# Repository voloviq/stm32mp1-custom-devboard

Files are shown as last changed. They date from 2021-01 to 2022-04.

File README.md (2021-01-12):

# stm32mp1-visionsom-custom-devboard
Custom development board for is located in two separated branch for stm32mp1-visionsom from Somlabs and osd32mp1 from Octavo Systems.

Development boards are created in KiCad.

Boards supported with DSI Display with touchscreen, arduino header, power supply, ethernet and usb.

Board 3D View

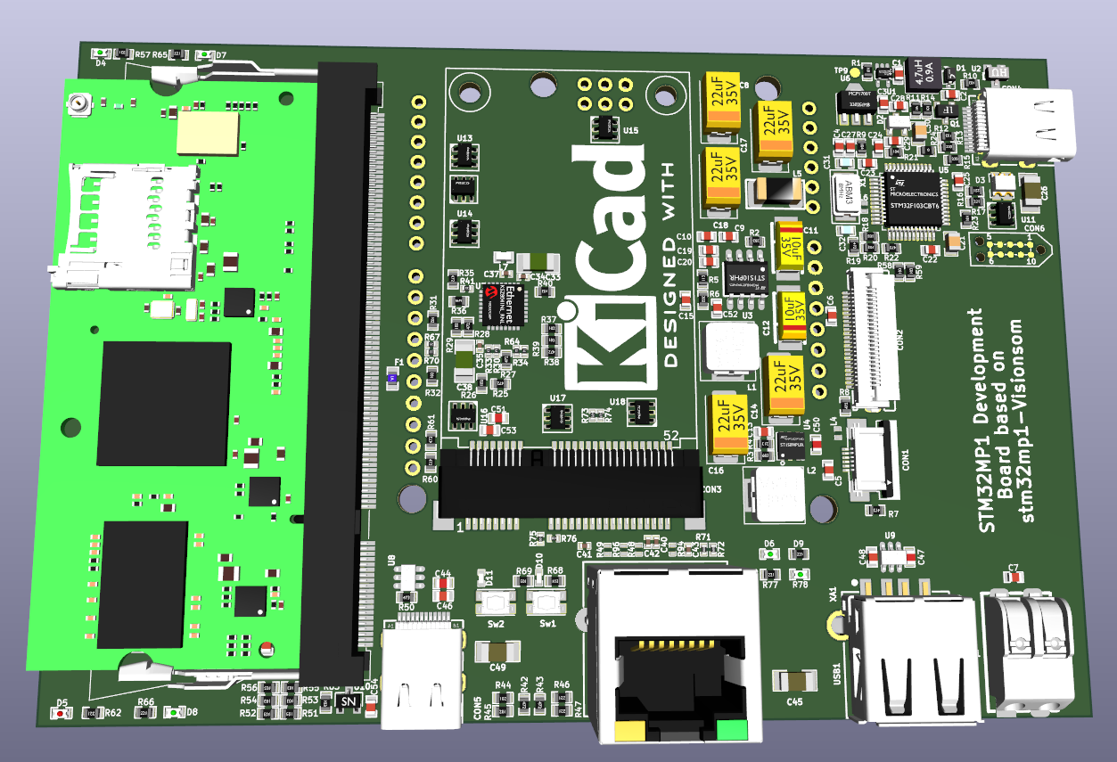
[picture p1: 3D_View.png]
Board 3D View


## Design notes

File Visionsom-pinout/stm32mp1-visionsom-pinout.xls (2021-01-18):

VisionSom STM32MP1xxx Pinout – MPU model STM32MP157AABxx LFBGA354
Signal Name | Module Pin Number | Ball Id | Pin Port Alternate function | Complete Pin Port Functions Description
DSI-Ckp | 195 | B14 | NA | DSI_CKP
DSI-Ckn | 193 | A14 | NA | DSI_CKN
SD2-CLK | 179 | A5 | AF9 | PE3_TRACED0,TIM15_BKIN,SAI1_SD_B,SDMMC2_CK,FMC_A19,EVENTOUT
SD2-DATA2 | 175 | A7 | AF9 | PB3_TRACED9,TIM2_CH2,SAI4_CK1,SPI1_SCK/I2S1_CK,SPI3_SCK/I2S3_CK,SPI6_SCK,SDMMC2_D2,SAI4_MCLK_A,UART7_RX,EVENTOUT
SD2-CMD | 173 | A6 | AF10 | PG6_TRACED14,TIM17_BKIN,SDMMC2_CMD,DCMI_D12,LCD_R7,EVENTOUT
SD2-DATA1 | 171 | A8 | AF9 | PB15_RTC_REFIN,TIM1_CH3N,TIM12_CH2,TIM8_CH3N,USART1_RX,SPI2_MOSI/I2S2_SDO,DFSDM1_CKIN2,SDMMC2_D1,EVENTOUT
SD2-DATA3 | 169 | B9 | AF9 | PB4_TRACED8,TIM16_BKIN,TIM3_CH1,SAI4_CK2,SPI1_MISO/I2S1_SDI,SPI3_MISO/I2S3_SDI,SPI2_NSS/I2S2_WS,SPI6_MISO,SDMMC2_D3,SAI4_SCK_A,UART7_TX,EVENTOUT
SD2-DATA0 | 167 | C9 | AF9 | PB14_TIM1_CH2N,TIM12_CH1,TIM8_CH2N,USART1_TX,SPI2_MISO/I2S2_SDI,DFSDM1_DATIN2,USART3_RTS/USART3_DE,SDMMC2_D0,EVENTOUT
LCD-ENABLE | 163 | C2 | AF14 | PE13_HDP2,TIM1_CH3,DFSDM1_CKIN5,SPI4_MISO,SAI2_FS_B,FMC_D10/FMC_DA10,DCMI_D6,LCD_DE,EVENTOUT
LCD-CLK | 161 | D3 | AF14 | PE14_TIM1_CH4,SPI4_MOSI,UART8_RTS/UART8_DE,SAI2_MCLK_B,SDMMC1_D123DIR,FMC_D11/FMC_DA11,LCD_G0,LCD_CLK,EVENTOUT
GPIO-PA1 | 157 | U4 | ? | PA1_ETH_CLK,TIM2_CH2,TIM5_CH2,LPTIM3_OUT,TIM15_CH1N,USART2_RTS/USART2_DE,UART4_RX,QUADSPI_BK1_IO3,SAI2_MCLK_B,ETH1_GMII_RX_CLK/ETH1_MII_RX_CLK/ETH1_RGMII_RX_CLK/ETH1_RMII_REF_CLK,LCD_R2,EVENTOUT,ADC1_INP17,ADC1_INN16
LCD-DATA1 | 155 | ? | ? | ?
LCD-DATA0 | 153 | ? | ? | ?
LCD-B6 | 151 | W6 | AF14 | REF_CLK
LCD-B5 | 149 | P3 | AF14 | PA3_TIM2_CH4,TIM5_CH4,LPTIM5_OUT,TIM15_CH2,USART2_RX,LCD_B2,ETH1_GMII_COL/ETH1_MII_COL,LCD_B5,EVENTOUT,ADC1_INP15,PVD_IN
LCD-DATA9 | 145 | ? | ? | ?
LCD-DATA8 | 143 | ? | ? | ?
LCD-G6 | 141 | A9 | AF14 | PC7_HDP4,TIM3_CH2,TIM8_CH2,DFSDM1_DATIN3,I2S3_MCK,USART6_RX,SDMMC1_D123DIR,SDMMC2_D123DIR,SDMMC2_D7,SDMMC1_D7,DCMI_D1,LCD_G6,EVENTOUT
LCD-G5 | 139 | U5 | AF14 | PF11_SPI5_MOSI,SAI2_SD_B,DCMI_D12,LCD_G5,EVENTOUT,ADC1_INP2
LCD-R2 | 137 | D11 | AF14 | PC10_TRACED2,DFSDM1_CKIN5,SPI3_SCK/I2S3_CK,USART3_TX,UART4_TX,QUADSPI_BK1_IO1,SAI4_MCLK_B,SDMMC1_D2,DCMI_D8,LCD_R2,EVENTOUT
LCD-DATA17 | 133 | ? | ? | ?
LCD-R6 | 131 | B8 | AF14 | PA8_MCO1,TIM1_CH1,TIM8_BKIN2,I2C3_SCL,SPI3_MOSI/I2S3_SDO,USART1_CK,SDMMC2_CKIN,SDMMC2_D4,OTG_FS_SOF/OTG_HS_SOF,SAI4_SD_B,UART7_RX,LCD_R6,EVENTOUT,
LCD-R5 | 129 | C8 | AF14 | PA9_TIM1_CH2,I2C3_SMBA,SPI2_SCK/I2S2_CK,USART1_TX,SDMMC2_CDIR,SDMMC2_D5,DCMI_D0,LCD_R5,EVENTOUT
GPIO-PE2 | 121 | T1 | ? | PE2_TRACECLK,SAI1_CK1,I2C4_SCL,SPI4_SCK,SAI1_MCLK_A,QUADSPI_BK1_IO2,ETH1_GMII_TXD3/ETH1_MII_TXD3/ETH1_RGMII_TXD3,FMC_A23,EVENTOUT
GPIO-PC2 | 119 | T2 | ? | PC2_DFSDM1_CKIN1,SPI2_MISO/I2S2_SDI,DFSDM1_CKOUT,ETH1_GMII_TXD2/ETH1_MII_TXD2/ETH1_RGMII_TXD2,DCMI_PIXCLK,EVENTOUT,ADC1_INP12,ADC1_INN11
GPIO-PA14 | 117 | R1 | ? | PA14_DBTRGO,DBTRGI,MCO2,EVENTOUT
GPIO-PA13 | 113 | P2 | ? | PA13_DBTRGO,DBTRGI,MCO1,UART4_TX,EVENTOUT,BOOTFAILN
GPIO-PD15 | 111 | G1 | ? | PD15_TIM4_CH4,SAI3_MCLK_A,UART8_CTS,FMC_D1/FMC_DA1,LCD_R1,EVENTOUT
GPIO-PG12 | 109 | F1 | ? | PG12_LPTIM1_IN1,SPI6_MISO,SAI4_CK2,USART6_RTS/USART6_DE,SPDIFRX_IN1,LCD_B4,SAI4_SCK_A,ETH1_PHY_INTN,FMC_NE4,LCD_B1,EVENTOUT
ENET1-CRS-DV | 101 | T6 | AF11 | PA7_TIM1_CH1N,TIM3_CH2,TIM8_CH1N,SAI4_D1,SPI1_MOSI/I2S1_SDO,SPI6_MOSI,TIM14_CH1,QUADSPI_CLK,ETH1_GMII_RX_DV/ETH1_MII_RX_DV/ETH1_RGMII_RX_CTL/ETH1_RMII_CRS_DV,SAI4_SD_A, EVENTOUT,ADC1_INP7,ADC1_INN3,ADC2_INP7,ADC2_INN3
ENET1-RXD1 | 99 | V4 | AF11 | PC5_SAI1_D3,DFSDM1_DATIN2,SAI4_D4, SAI1_D4,SPDIFRX_IN3,ETH1_GMII_RXD1/ETH1_MII_RXD1/ETH1_RGMII_RXD1/ETH1_RMII_RXD1, SAI4_D3,EVENTOUT,ADC1_INP8,ADC1_INN4,ADC2_INP8,ADC2_INN4
ENET1-RXD0 | 97 | W4 | AF11 | PC4_DFSDM1_CKIN2,I2S1_MCK,SPDIFRX_IN2,ETH1_GMII_RXD0/ETH1_MII_RXD0/ETH1_RGMII_RXD0/ETH1_RMII_RXD0,EVENTOUT,ADC1_INP4,ADC2_INP4
USART6-TXD | 79 | U1 | AF7 | PG14_TRACED1,LPTIM1_ETR,SPI6_MOSI, SAI4_D1,USART6_TX,QUADSPI_BK2_IO3,SAI4_SD_A,ETH1_GMII_TXD1/ETH1_MII_TXD1/ETH1_RGMII_TXD1/ETH1_RMII_TXD1,FMC_A25,LCD_B0,EVENTOUT
UART4-RXD | 77 | T13 | AF8 | PB2_TRACED4,RTC_OUT2,SAI1_D1,DFSDM1_CKIN1,USART1_RX,I2S_CKIN,SAI1_SD_A,SPI3_MOSI/I2S3_SDO,UART4_RX,QUADSPI_CLK,EVENTOUT
UART4-TXD | 75 | V6 | AF6 | PG11_TRACED11,USART1_TX,UART4_TX,SPDIFRX_IN0,ETH1_GMII_TX_EN/ETH1_MII_TX_EN/ETH1_RGMII_TX_CTL/ETH1_RMII_TX_EN,DCMI_D3,LCD_B3, EVENTOUT
USART1-TXD | 73 | T12 | AF7 | PB6_TIM16_CH1N,TIM4_CH1,I2C1_SCL, CEC,I2C4_SCL,USART1_TX,FDCAN2_TX,QUADSPI_BK1_NCS,DFSDM1_DATIN5,UART5_TX,DCMI_D5,EVENTOUT
USART1-RXD | 69 | T16 | AF7 | PA10_TIM1_CH3,SPI3_NSS/I2S3_WS,USART1_RX,MDIOS_MDIO,SAI4_FS_B,DCMI_D1,LCD_B1,EVENTOUT,OTG_FS_ID,OTG_HS_ID
USART3-RXD | 67 | G3 | AF7 | PD9_DFSDM1_DATIN3,SAI3_SD_B,USART3_RX,FMC_D14/FMC_DA14,DCMI_HSYNC,LCD_B0,EVENTOUT
USART3-TXD | 65 | F2 | AF7 | PD8_DFSDM1_CKIN3,SAI3_SCK_B,USART3_TX,SPDIFRX_IN1,FMC_D13/FMC_DA13,LCD_B7,EVENTOUT
UART8-RXD | 63 | C4 | AF8 | PE0_LPTIM1_ETR,TIM4_ETR,LPTIM2_ETR,SPI3_SCK/I2S3_CK,SAI4_MCLK_B,UART8_RX,SAI2_MCLK_A,FMC_NBL0,DCMI_D2,EVENTOUT
ENET1-MDIO | 61 | W2 | AF11 | PA2_TIM2_CH3,TIM5_CH3,LPTIM4_OUT,TIM15_CH1,USART2_TX,SAI2_SCK_B,SDMMC2_D0DIR, ETH1_MDIO, MDIOS_MDIO, LCD_R1, EVENTOUT, ADC1_INP14, WKUP2
UART8-TXD | 57 | B1 | AF8 | PE1_LPTIM1_IN2,I2S2_MCK,SAI3_SD_B,UART8_TX,FMC_NBL1,DCMI_D3,EVENTOUT
GPIO-PC0-ADC1-10 | 55 | T7 | ANALOG | PC0_DFSDM1_CKIN0,LPTIM2_IN2,DFSDM1_DATIN4,SAI2_FS_B,QUADSPI_BK2_NCS,LCD_R5,EVENTOUT,ADC1_INP10,ADC2_INP10
ENET1-MDC | 53 | V2 | AF11 | PC1_TRACED0,SAI1_D1,DFSDM1_DATIN0,DFSDM1_CKIN4,SPI2_MOSI/I2S2_SDO,SAI1_SD_A,SDMMC2_CK,ETH1_MDC,MDIOS_MDC,EVENTOUT,ADC1_INP11,ADC1_INN10,ADC2_INP11,ADC2_INN10,TAMP_IN3,WKUP6
GPIO-PD13 | 49 | U12 | ? | PD13_LPTIM1_OUT,TIM4_CH2,I2C4_SDA,I2C1_SDA,I2S3_MCK,QUADSPI_BK1_IO3,SAI2_SCK_A,FMC_A18,DSI_TE,EVENTOUT
GPIO-PC3-ADC1-13 | 47 | T3 | ANALOG | PC3_TRACECLK,DFSDM1_DATIN1,SPI2_MOSI/I2S2_SDO,ETH1_GMII_TX_CLK/ETH1_MII_TX_CLK,EVENTOUT,ADC1_INP13,ADC1_INN12
GPIO-PG10 | 45 | V7 | ? | PG10_TRACED10,UART8_CTS,LCD_G3,SAI2_SD_B,QUADSPI_BK2_IO2,FMC_NE3,DCMI_D2,LCD_B2,EVENTOUT
JTAG-TDI | 43 | D13 | NA | JTDI
USB-OTG2-DN | 27 | V13 | NA | USBH_HS_DM2,OTG_HS_DM
USB-OTG2-DP | 25 | W13 | NA | USBH_HS_DP2,OTG_HS_DP
USB-OTG1-DN | 21 | W14 | NA | USBH_HS_DM1
USB-OTG1-DP | 19 | V14 | NA | USBH_HS_DP1
USB-OTG2-VBUS | 11 |  | NA | NA
BOOT0 | 9 |  | NA | NA
BOOT1 | 7 |  | NA | NA
PWR-ON | 5 |  | NA | NA
PWR-LP | 3 |  | NA | NA
DSI-D1p | 194 | B15 | NA | DSI_D1P
DSI-D1n | 192 | A15 | NA | DSI_D1N
DSI-D0p | 188 | B13 | NA | DSI_D0P
DSI-D0n | 186 | A13 | NA | DSI_D0N
LCD-B7 | 166 | D9 | AF14 | PB9_HDP7,TIM17_CH1,TIM4_CH4,DFSDM1_DATIN7,I2C1_SDA,SPI2_NSS/I2S2_WS,I2C4_SDA,SDMMC2_CDIR,UART4_TX,FDCAN1_TX,SDMMC2_D5,SDMMC1_CDIR,SDMMC1_D5,DCMI_D7,LCD_B7,EVENTOUT
LCD-B2 | 164 | E3 | AF14 | PD6_TIM16_CH1N,SAI1_D1,DFSDM1_CKIN4,DFSDM1_DATIN1,SPI3_MOSI/I2S3_SDO,SAI1_SD_A,USART2_RX,FMC_NWAIT,DCMI_D10,LCD_B2,EVENTOUT
LCD-VSYNC | 162 | R4 | AF14 | PA4_HDP0,TIM5_ETR,SAI4_D2,SPI1_NSS/I2S1_WS,SPI3_NSS/I2S3_WS,USART2_CK,SPI6_NSS,SAI4_FS_A,DCMI_HSYNC,LCD_VSYNC,EVENTOUT,ADC1_INP18,ADC2_INP18,DAC_OUT1
LCD-HSYNC | 160 | D10 | AF14 | PC6_HDP1,TIM3_CH1,TIM8_CH1,DFSDM1_CKIN3,I2S2_MCK,USART6_TX,SDMMC1_D0DIR,SDMMC2_D0DIR,SDMMC2_D6,DSI_TE,SDMMC1_D6,DCMI_D0,LCD_HSYNC,EVENTOUT
LCD-B4 | 158 | D2 | AF14 | PE12_TIM1_CH3N,DFSDM1_DATIN5,SPI4_SCK,SDMMC1_D0DIR,SAI2_SCK_B,FMC_D9/FMC_DA9,LCD_B4,EVENTOUT
LCD-B3 | 154 | C5 | AF14 | PD10_RTC_REFIN,TIM16_BKIN,DFSDM1_CKOUT,I2C5_SMBA,SPI3_MISO/I2S3_SDI,SAI3_FS_B,USART3_CK,FMC_D15/FMC_DA15,LCD_B3,EVENTOUT
LCD-G2 | 152 | T5 | AF14 | PA6_TIM1_BKIN,TIM3_CH1,TIM8_BKIN,SAI4_CK2,SPI1_MISO/I2S1_SDI,SPI6_MISO,TIM13_CH1,MDIOS_MDC,SAI4_SCK_A,DCMI_PIXCLK,LCD_G2,EVENTOUT,ADC1_INP3,ADC2_INP3
LCD-G4 | 150 | W5 | AF14 | PB10_TIM2_CH3,LPTIM2_IN1,I2C2_SCL,SPI2_SCK/I2S2_CK,DFSDM1_DATIN7,USART3_TX,QUADSPI_BK1_NCS,ETH1_GMII_RX_ER/ETH1_MII_RX_ER,LCD_G4,EVENTOUT
LCD-G3 | 148 | C1 | AF14 | PE11_TIM1_CH2,DFSDM1_CKIN4,SPI4_NSS,USART6_CK,SAI2_SD_B,FMC_D8/FMC_DA8,DCMI_D4,LCD_G3,EVENTOUT
LCD-DATA16 | 144 | ? | ? | ?
LCD-G7 | 142 | U7 | AF14 | PG8_TRACED15,TIM2_CH1/TIM2_ETR,ETH_CLK,TIM8_ETR,SPI6_NSS,SAI4_D2,USART6_RTS/USART6_DE,USART3_RTS/USART3_DE,SPDIFRX_IN2,SAI4_FS_A,ETH1_PPS_OUT,LCD_G7,EVENTOUT
LCD-R4 | 140 | P4 | AF14 | PA5_TIM2_CH1/TIM2_ETR,TIM8_CH1N,SAI4_CK1,SPI1_SCK/I2S1_CK,SPI6_SCK,SAI4_MCLK_A,LCD_R4,EVENTOUT,ADC1_INP19,ADC1_INN18,ADC2_INP19,ADC2_INN18,DAC_OUT2
LCD-R3 | 138 | W3 | AF9 | PB0_TIM1_CH2N,TIM3_CH3,TIM8_CH2N,DFSDM1_CKOUT,UART4_CTS,LCD_R3,ETH1_GMII_RXD2/ETH1_MII_RXD2/ETH1_RGMII_RXD2,MDIOS_MDIO,LCD_G1,EVENTOUT,ADC1_INP9,ADC1_INN5,ADC2_INP9,ADC2_INN5
LCD-R7 | 134 | E1 | AF14 | PE15_HDP3,TIM1_BKIN,TIM15_BKIN,USART2_CTS/USART2_NSS,UART8_CTS,FMC_NCE2,FMC_D12/FMC_DA12,LCD_R7,EVENTOUT
ENET1-TXD1 | 124 | T9 | AF11 | PB13_TIM1_CH1N,DFSDM1_CKOUT,LPTIM2_OUT,SPI2_SCK/I2S2_CK,DFSDM1_CKIN1,USART3_CTS/USART3_NSS,FDCAN2_TX,ETH1_GMII_TXD1/ETH1_MII_TXD1/ETH1_RGMII_TXD1/ETH1_RMII_TXD1,UART5_TX,EVENTOUT
ENET1-TXD0 | 122 | U2 | AF11 | PG13_TRACED0,LPTIM1_OUT,SAI1_CK2,SAI4_CK1,SPI6_SCK,SAI1_SCK_A,USART6_CTS/USART6_NSS,SAI4_MCLK_A,ETH1_GMII_TXD0/ETH1_MII_TXD0/ETH1_RGMII_TXD0/ETH1_RMII_TXD0,FMC_A24,LCD_R0,EVENTOUT
ENET1-CLK | 118 | T8 | AF0 | PB5_ETH_CLK,TIM17_BKIN,TIM3_CH2,SAI4_D1,I2C1_SMBA,SPI1_MOSI/I2S1_SDO,I2C4_SMBA,SPI3_MOSI/I2S3_SDO,SPI6_MOSI,FDCAN2_RX,SAI4_SD_A,ETH1_PPS_OUT,UART5_RX,DCMI_D10,LCD_G7,EVENTOUT
ENET1-TX-EN | 114 | V1 | AF11 | PB11_TIM2_CH4,LPTIM2_ETR,I2C2_SDA,DFSDM1_CKIN7,USART3_RX,ETH1_GMII_TX_EN/ETH1_MII_TX_EN/ETH1_RGMII_TX_CTL/ETH1_RMII_TX_EN,DSI_TE,LCD_G5,EVENTOUT
USART1-RTS | 80 | U16 | AF7 | PA12_TIM1_ETR,I2C6_SDA,I2C5_SDA,UART4_TX,USART1_RTS/USART1_DE,SAI2_FS_B,FDCAN1_TX,LCD_R5,EVENTOUT,OTG_FS_DP
USART3-RTS | 78 | U11 | AF7 | PD12_LPTIM1_IN1,TIM4_CH1,LPTIM2_IN1,I2C4_SCL,I2C1_SCL,USART3_RTS/USART3_DE,QUADSPI_BK1_IO1,SAI2_FS_A,FMC_ALE/FMC_A17,EVENTOUT
USART1-CTS | 76 | V17 | AF7 | PA11_TIM1_CH4,I2C6_SCL,I2C5_SCL,SPI2_NSS/I2S2_WS,UART4_RX,USART1_CTS/USART1_NSS,FDCAN1_RX,LCD_R4,EVENTOUT,OTG_FS_DM
UART8-RTS | 74 | W10 | AF8 | PG7_TRACED5, SAI1_MCLK_A, USART6_CK, UART8_RTS/UART8_DE, QUADSPI_CLK, QUADSPI_BK2_IO3, DCMI_D13, LCD_CLK, EVENTOUT
USART3-CTS | 72 | V8 | AF7 | PD11_LPTIM2_IN2,I2C4_SMBA,I2C1_SMBA,USART3_CTS/USART3_NSS,QUADSPI_BK1_IO0,SAI2_SD_A,FMC_CLE/FMC_A16,EVENTOUT
USART6-RXD | 68 | T14 | AF7 | PG9_DBTRGO,USART6_RX,SPDIFRX_IN3,QUADSPI_BK2_IO2,SAI2_FS_B,FMC_NCE/FMC_NE2,DCMI_VSYNC,LCD_R1,EVENTOUT
UART8-CTS | 66 | F3 | AF8 | PD14_TIM4_CH3, SAI3_MCLK_B,UART8_CTS,FMC_AD0/FMC_D0, EVENTOUT
GPIO-PF10 | 64 | U9 | ? | PF10_TIM16_BKIN,SAI1_D3,SAI4_D4,SAI1_D4,QUADSPI_CLK,SAI4_D3,DCMI_D11, LCD_DE,EVENTOUT
GPIO-PA0-ADC1-16 | 62 | R3 | ANALOG | PA0_TIM2_CH1/TIM2_ETR,TIM5_CH1,TIM8_ETR,TIM15_BKIN,USART2_CTS/USART2_NSS,UART4_TX,SDMMC2_CMD,SAI2_SD_B,ETH1_GMII_CRS/ETH1_MII_CRS,EVENTOUT
GPIO-PB1-ADC1-5 | 58 | V3 | ANALOG | PB1_TIM1_CH3N,TIM3_CH4,TIM8_CH3N,DFSDM1_DATIN1,LCD_R6,ETH1_GMII_RXD3/ETH1_MII_RXD3/ETH1_RGMII_RXD3,MDIOS_MDC,LCD_G0,EVENTOUT,ADC1_INP5,ADC2_INP5
GPIO-PB7 | 56 | B5 | ? | PB7_TIM17_CH1N,TIM4_CH2,I2C1_SDA,I2C4_SDA,USART1_RX,SDMMC2_D1,DFSDM1_CKIN5,FMC_NL,DCMI_VSYNC,EVENTOUT
JTAG-TCK | 54 | D16 | NA | JTCK-SWCLK
JTAG-TDO | 52 | D14 | NA | JTDO-TRACESWO
JTAG-nTRST | 48 | D12 | NA | NJTRST
JTAG-TMS | 46 | D15 | NA | JTMS-SWDIO
BOOT2 | 10 |  | NA | NA
STM32-nRST | 4 |  | NA | NA

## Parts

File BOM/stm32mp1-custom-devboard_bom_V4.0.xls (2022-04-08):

Component | Description | References | Value | Footprint | Quantity Per PCB | Datasheet | Manufacturer | Manufacturer Part Number | Supplier | Supplier Part Number | URL | LCSC Part #(optional)
1 | 100nF, 50V, X7R, ±10%, -55ºC to +125ÂḞC | C5 C6 C7 C9 C10 C13 C19 C20 C22 C23 C24 C25 C27 C28 C29 C34 C35 C37 C40 C41 C42 C43 C46 C48 C52 C53 C54 C55 C56 | 100nF/50V | 402 | 29 | https://www.tme.eu/Document/558f361ed82994aff5a3e7789d970dd1/GRM155R71H104KE14-01.pdf | Murata | GRM155R71H104KE14D | Tme | GRM155R71H104KE14D | https://www.tme.eu/pl/details/grm155r71h104ke14d/kondensatory-mlcc-smd-0402/murata/ | C131394
2 | 10nF / 50V, X7R, ±10%, -55ºC to +125ºC | C15 | 10nF/50V | 603 | 1 | https://www.tme.eu/Document/6a5ad7ac81542ad65ce1ca82bcd21ffa/vjw1bcbascomseries.pdf | VISHAY | VJ0603Y103KXAPW1BC | Tme | VJ0603Y103KXAPW1BC | https://www.tme.eu/pl/details/vj0603y103kxapw1bc/kondensatory-mlcc-smd-0603/vishay/ | C342901
3 | 10uF, 6.3V, X5R, 10%, -55ºC to +85ºC MLCC | C44 C47 C50 C51 C21 C30 | 10uF | 603 | 6 | https://www.tme.eu/Document/08070be221b22b3ff38fe1f90e5753ee/C0603C106M9PACTU.pdf | KEMET | C0603C106M9PACTU | TME | C0603C106M9PAC | https://www.tme.eu/pl/details/c0603c106m9pac/kondensatory-mlcc-smd-0603/kemet/c0603c106m9pactu/ | C162265
4 | 10uF 35VDC Size C 2312 +/10% -55...125ºC Tantalum | C11 C12 | 10uF/35V | Size_C | 2 | https://www.tme.eu/Document/a5d90d85079967994fb49c0e8f8ad6e9/293d.pdf | VISHAY | 293D106X9035C2TE3 | TME | 293D106X9035C2TE3 | https://www.tme.eu/pl/details/293d106x9035c2te3/kondensatory-tantalowe-smd/vishay/ | C169217
5 | 1nF 2kV X7R ±10% -55...125ºC MLCC | C26 C45 C49 | 1nF/2kV | 1206 | 3 | https://www.tme.eu/Document/fbb9415081fcefba62c0f8bbf5b21210/UPY-GPHC_X7R_6.3V-to-50V_20.pdf | YAGEO | CC1206KKX7RDBB102 | Tme | CC1206KKX7RD102 | https://www.tme.eu/pl/details/cc1206kkx7rd102/kondensatory-mlcc-smd-1206/yageo/cc1206kkx7rdbb102/ | C282813
6 | 1uF/16V, X7R, ±10%, -55ºC to +125ºC | C1 C3 C4 | 1uF/16V | 603 | 3 | https://www.tme.eu/Document/4a42202b32dab16128fe107dd69598cc/samsung-chip-cap.pdf | SAMSUNG | CL10B105KO8NNNC | TME | CL10B105KO8NNNC | https://www.tme.eu/pl/details/cl10b105ko8nnnc/kondensatory-mlcc-smd-0603/samsung/ | C105504
7 | 20pF / 50V, C0G, 5%, -55ºC to +125ºC | C31 C32 | 20pF/50V | 603 | 2 | https://www.tme.eu/Document/83573c8f0792501446537ba84bc905ab/C0603C200J5GACTU.pdf | Kemet | C0603C200J5GACTU | Tme | C0603C200J5GAC | https://www.tme.eu/pl/details/c0603c200j5gac/kondensatory-mlcc-smd-0603/kemet/c0603c200j5gactu/ | C165733
8 | 22uF 35VDC Size C 2312 +/10% -55...125ºC Tantalum | C8 C14 C16 C17 C18 | 22uF35V | Size_D | 5 | https://www.tme.eu/Document/a5d90d85079967994fb49c0e8f8ad6e9/293d.pdf | VISHAY | 293D226X9035D2TE3 | TME | 293D226X9035D2TE3 | https://www.tme.eu/pl/details/293d226x9035d2te3/kondensatory-tantalowe-smd/vishay/ | C126947
9 | 22uF 10VDC Size C 2312 +/10% -55...125ºC Tantalum | C33 C38 | 22uF6V3 | 2312/Size_C | 2 | https://www.tme.eu/Document/a5d90d85079967994fb49c0e8f8ad6e9/293d.pdf | VISHAY | 293D226X9010C2TE3 | TME | 293D226X9010C2TE3 | https://www.tme.eu/pl/en/details/293d226x9010c2te3/smd-tantalum-capacitors/vishay/ | C159757
10 | 4_7uF / 6.3V SMD Capacitor | C2 | 4.7uF/35V | 603 | 1 | Smd_0603/Components_Documentation/KEM_C1005_Y5V_SMD.pdf | SAMSUNG | CL10A475KQ8NNNC | TME | CL10A475KQ8NNNC | https://www.tme.eu/pl/details/cl10a475kq8nnnc/kondensatory-mlcc-smd-0603/samsung/ | C326580
11 | Gold Flash Mini PCI-Express 52 pin Connector with hooks 0.5A 8mm high 0.8mm pitch | CON3 | 119A-80A00-R02-SET | MiniPci52 | 1 | https://www.tme.eu/Document/6644d089e05690dabd52e371ce675bbb/119A.pdf | ATTEND | 119A-80A00-R02 SET | Tme | 119A-80A00.SET | https://www.tme.eu/pl/details/119a-80a00.set/zlacza-do-kart/attend/119a-80a00-r02-set/
12 | FPC 24 pins bottom 0.5mm raster from MOLEX | CON2 | 505110-2491 | SMD/SMT FPC/FFC | 1 | https://pl.mouser.com/datasheet/2/276/2/5051102491_FFC_FPC_CONNECTORS-705759.pdf | MOLEX | 505110-2491 | Mouser | 538-505110-2491 | https://pl.mouser.com/ProductDetail/Molex/505110-2491?qs=fSIr1QPo%2F%2FQZaS1NuXTizw%3D%3D | C479748
13 | 6-Pin FPC FFC 0.5mm Pitch Bottom Entry MOLEX Connector | CON1 | 52746-0671 | fpc-6pos | 1 | https://pl.mouser.com/datasheet/2/276/0527460671_FFC_FPC_CONNECTORS-170646.pdf | MOLEX | 52746-0671 | Mouser | 538-52746-0671 | https://pl.mouser.com/ProductDetail/Molex/52746-0671?qs=6mwHGXDh%252BQw5M6CFKCiadw%3D%3D | C709367
14 | WR-COM USB 3.1 Type C Receptacle Horizontal Mid-Mount THR / SMT 1.6 mm | CON4 CON5 | 632723300011 | USB C | 2 | https://pl.mouser.com/datasheet/2/445/632723300011-1718173.pdf | Wurth Elektronik | 632723300011 | Mouser | 710-632723300011 | https://pl.mouser.com/ProductDetail/Wurth-Elektronik/632723300011?qs=NK6InXoXhq4%252B5eM1PePLPg%3D%3D
15 | SMD 0402 C=10pF Vdc=12V Wuerth ESD Suppressor | D10 D11 | 82357120100 | 402 | 2 | https://pl.mouser.com/datasheet/2/445/82357120100-1004233.pdf | Wurth Elektronik | 82357120100 | Mouser | 710-82357120100 | https://pl.mouser.com/ProductDetail/Wurth-Elektronik/82357120100?qs=zPgndZZmKGaQLkp%252BJgSqWQ%3D%3D | C39109
16 | Double Led Diode - Red / Green R(626nm), G(572nm) 4...15mcd 65/65mW 170º 2,1...2,6/2,2...2,6V 20mA | D3 | HSMF-C155 | 1210 | 1 | https://www.tme.eu/Document/5347ca759446376109b2a8fec5a7b694/HSMF-C155.pdf | Broadcom/Avago | HSMF-C155 | Tme | HSMF-C155 | https://www.tme.eu/pl/details/hsmf-c155/diody-led-smd-kolorowe/broadcom-avago/ | C273608
17 | Red LED 630nm 20mA 200...350mcd 120º -40ºC to +85ºC | D5 | KPG-1608SURKC-T | 603 | 1 | https://www.tme.eu/Document/d1801a08836278504c2ab877cf18852c/KPG-1608SURKC-T.pdf | KINGBRIGHT ELECTRONIC | KPG-1608SURKC-T | TME | KPG-1608SURKC-T | https://www.tme.eu/pl/details/kpg-1608surkc-t/diody-led-smd-kolorowe/kingbright-electronic/ | C192315
18 | Green LED 570nm 20mA 10...40mcd 120º -40ºC to +85ºC | D4 D6 D7 D8 D9 | KPT-1608CGCK | 603 | 5 | https://www.tme.eu/Document/a39d324b494aca9bed634649dc83966d/kp-1608cgck.pdf | KINGBRIGHT ELECTRONIC | KP-1608CGCK | TME | KP-1608CGCK | https://www.tme.eu/pl/details/kp-1608cgck/diody-led-smd-kolorowe/kingbright-electronic/ | C192316
19 | Schottky Barrier Diode 500mA | D1 | NSR0530H-D |  | 1 | https://www.digikey.pl/pl/datasheets/on-semiconductor/on-semiconductor-nsr0530h-d | On Semiconductor | NSR0530H | Digi-Key | NSR0530HT1G | https://www.digikey.pl/pl/products/detail/onsemi/NSR0530HT1G/5761752?s=N4IgTCBcDaIHIGUBKAGArAZhQCRAXQF8g | C191023
20 | Schottky Barrier Diode IF=1.5A Vr=20V Low VF - 65â +125â | D2 D12 | PMEG2015EA | SOD-323 | 2 | https://pl.mouser.com/datasheet/2/916/PMEG2015EA-1599826.pdf | Nexperia | PMEG2015EA,115 | Mouser | 771-PMEG2015EA115 | https://pl.mouser.com/ProductDetail/Nexperia/PMEG2015EA115?qs=LOCUfHb8d9uL8QMkobJwRA%3D%3D | C191023
21 | Fuse Super Quick Acting 1A 32V | F1 | FF_PW_1A0 | 603 | 1 | https://www.tme.eu/Document/d23fed0116a9e0192c3db408cb2a3cd4/81.pdf | ESKA | FUSE 0603-FF PW 1A | Tme | BSMD0603-SS1.0 | https://www.tme.eu/pl/details/bsmd0603-ss1.0/bezpieczniki-smd-0603-superszybkie/eska/fuse-0603-ff-pw-1a0/ | C354888
22 | 3.3uH 13.5A 45MHz 28mΩ ±20% -55...+125 ºC Inductor Ferrite | L1 L2 | 3.3uH-13.5A | 7.2 mm x 6.65 mm x 3 mm | 2 | https://pl.mouser.com/datasheet/2/3/ASPI-0630HI-1774982.pdf | ABRACON | ASPI-0630HI-3R3M-T15 | Mouser | 815-ASPI0630HI3R3T15 | https://pl.mouser.com/ProductDetail/ABRACON/ASPI-0630HI-3R3M-T15?qs=bWAYEm3xoCYwUcwgROPtBA%3D%3D | C351116
23 | 4.7uH 0.9A 35MHz 409mΩ ±20% -40...+125 ºC | L3 | 4.7uH-0.9A | 3mm x 3mm x 1mm | 1 | https://pl.mouser.com/datasheet/2/445/744030004-1720746.pdf | Wurth | 74438333047 | Mouser | 710-74438333047 | https://pl.mouser.com/ProductDetail/Wurth-Elektronik/744030004?qs=2kOmHSv6VfR%252BWe9vXKDhWA%3D%3D | C354565
24 | Z=785Ohm Load=3A R=50mOhm Temp=-55ºC+85ºC 1812 Ferrite Beads WE-TMSB Suppression | L5 | 742792515 | 1812 | 1 | https://pl.mouser.com/datasheet/2/445/742792515-1720486.pdf | Wurth Elektronik | 742792515 | Mouser | 710-742792515 | https://pl.mouser.com/ProductDetail/Wurth-Elektronik/742792515?qs=5twSNpOB8ICAMx1lqqYekg%3D%3D | C394526
25 | EMI Suppression Filters EMIFIL Z=600Ohm Load=0.3A R=0.7Ohm, -55...125ºC | L4 L6 | BLM15HG601SN1D | 402 | 2 | https://www.tme.eu/Document/ea442a092e4ff19cd70ec3627ff4728b/BLM15HG601SN1%23.pdf | MURATA | BLM15HG601SN1D | Tme | BLM15HG601SN1D | https://www.tme.eu/pl/details/blm15hg601sn1d/ferryty-koraliki/murata/ | C76890
26 | Z=120Ohm,Load=2A,R=0.05Ohm, Temp=-55C+125C, EMI Suppression Filters EMIFIL | L7 | BLM18PG121SN1D | 603 | 1 | https://www.tme.eu/Document/19a35c43258593752611d1c31a7dbf1a/MURATA-BLM18P.pdf | MURATA | BLM18PG121SN1D | Tme | BLM18PG121SN1D | https://www.tme.eu/pl/details/blm18pg121sn1d/ferryty-koraliki/murata/ | C14709
27 | 2-pole WAGO SMD flat compact connector | P1 | Main Power Supply |  | 1 | https://www.tme.eu/Document/28804af55c4b82310280e81efa5b25a7/smd%20terminal%20blocks.pdf | WAGO | 2060-452/998-404 | TME | 2060-452/998-404 | https://www.tme.eu/pl/details/2060-452_998-404/zlacza-do-led/wago/2060-452-998-404/ | C2765055
28 | NPN General Purpose Transistor 100mA 45V 0.25W | Q1 | BC847B | SOT23-3 | 1 | https://www.tme.eu/Document/6f1446946b61c6ee994e420fd75b3124/bc847_8_9_bc850.pdf | INFINEON TECHNOLOGIES | BC847BE6327 | TME | BC847BE6327 | https://www.tme.eu/pl/details/bc847be6327/tranzystory-npn-smd/infineon-technologies/ | C545561
29 | 0Ω 0,1W ±5% -55...155ºC | R24 | 0R | 603 | 1 | https://www.tme.eu/Document/4f50d320a6ddacb273098f84373b6259/rezystor-smd.pdf | ROYAL OHM | 0603SAJ0000T5E | TME | SMD0603-0R | https://www.tme.eu/pl/details/smd0603-0r/rezystory-smd-0603/royal-ohm/0603saj0000t5e/ | C15402
30 | 0Ω, 62.5mW, 50V, ±5%, -55...155ºC | R79 R80 | 0R | 402 | 2 | https://pl.mouser.com/datasheet/2/447/PYu_RC_Group_51_RoHS_L_10-1664068.pdf | Yageo | RC0402JR-070RL | TME | 603-RC0402JR-070RL | https://pl.mouser.com/ProductDetail/Yageo/RC0402JR-070RL?qs=5Bml4Cp94iv7ykKkzPrwpQ%3D%3D | C325378
31 | 100Ω 0,1W ±1% -55...155ºC | R14 R23 | 100R | 603 | 2 | https://www.tme.eu/Document/ec37243ca557adb02ebafc5c1ab83104/CQ%20datasheet.pdf | Royal Ohm | CQ03SAF1000T5E | Tme | CQ0603-100R-1% | https://www.tme.eu/pl/details/cq0603-100r-1%25/rezystory-smd-0603/royal-ohm/cq03saf1000t5e/ | C269700
32 | 100kΩ 0,1W ±1% -55...155ºC | R9 R21 | 100k | 603 | 2 | https://www.tme.eu/Document/fa390a0a31e891a154d3713216995c6e/HighPowerHP.pdf | ROYAL OHM | HP03W5J0104T5E | TME | HP03-100K5% | https://www.tme.eu/pl/details/hp03-100k5%25/rezystory-smd-0603/royal-ohm/hp03w5j0104t5e/ | C269699
33 | 10Ω 63mW ±1% -55...155ºC | R71 R72 | 10R | 402 | 2 | https://www.tme.eu/Document/9e42ba54d36a9bd3dfa2901986ac022d/rezystor-smd.pdf | ROYAL OHM | 0402WGF100JTCE | TME | SMD0402-10R-1% | https://www.tme.eu/pl/details/smd0402-10r-1%2525/rezystory-smd-0402/royal-ohm/0402wgf100jtce/ | C269385
34 | 10kΩ 0,1W ±5% -55...155ºC | R10 R18 R20 R40 R51 R52 R53 R54 R55 R56 R58 R59 R63 R68 R69 | 10k | 603 | 15 | https://www.tme.eu/Document/4f50d320a6ddacb273098f84373b6259/rezystor-smd.pdf | ROYAL OHM | 0603SAJ0103T5E | TME | SMD0603-10K | https://www.tme.eu/pl/details/smd0603-10k/rezystory-smd-0603/royal-ohm/0603saj0103t5e/ | C269701
35 | 10Ω 0,1W ±1% -55...155ºC | R1 | 10Ω/1%/0.1Wat | 603 | 1 | https://www.tme.eu/Document/b315665a56acbc42df513c99b390ad98/ROYALOHM-THICKFILM.pdf | ROYAL OHM | 0603SAF100JT5E | TME | SMD0603-10R-1% | https://www.tme.eu/pl/details/smd0603-10r-1%2525/rezystory-smd-0603/royal-ohm/0603saf100jt5e/ | C269702
36 | 11kΩ 0,1W ±5% -55...155ºC | R5 | 11k,1% | 603 | 1 | https://www.tme.eu/Document/b315665a56acbc42df513c99b390ad98/ROYALOHM-THICKFILM.pdf | ROYAL OHM | 0603SAF1102T5E | TME | SMD0603-11K-1% | https://www.tme.eu/pl/details/smd0603-11k-1%2525/rezystory-smd-0603/royal-ohm/0603saf1102t5e/ | C25950
37 | 1kΩ 0,1W ±1% -55...155ºC | R26 R29 R31 R32 R37 R39 R75 R76 | 1k | 603 | 8 | https://www.tme.eu/Document/b315665a56acbc42df513c99b390ad98/ROYALOHM-THICKFILM.pdf | ROYAL OHM | 0603SAF1001T5E | TME | SMD0603-1K-1% | https://www.tme.eu/pl/details/smd0603-1k-1%2525/rezystory-smd-0603/royal-ohm/0603saf1001t5e/ | C21190
38 | 1.5kΩ 0,1W ±1% -55...155ºC | R13 | 1k5 | 603 | 1 | https://www.tme.eu/Document/9e42ba54d36a9bd3dfa2901986ac022d/rezystor-smd.pdf | Royal Ohm | 0603SAF1501T5E | TME | SMD0603-1K5-1% | https://www.tme.eu/pl/details/smd0603-1k5-1%25/rezystory-smd-0603/royal-ohm/0603saf1501t5e/ | C22843
39 | 1kΩ 0,1W ±1% -55...155ºC | R44 R45 | 1k_NM | 603 | 2 | https://www.tme.eu/Document/b315665a56acbc42df513c99b390ad98/ROYALOHM-THICKFILM.pdf | ROYAL OHM | 0603SAF1001T5E | TME | SMD0603-1K-1% | https://www.tme.eu/pl/details/smd0603-1k-1%2525/rezystory-smd-0603/royal-ohm/0603saf1001t5e/
40 | 21kΩ 0,1W ±5% -55...155ºC | R4 | 21k | 603 | 1 | https://www.tme.eu/pl/details/smd0603-21k-1%25/rezystory-smd-0603/royal-ohm/0603saf2102t5e/ | ROYAL OHM | 0603SAF2102T5E | Tme | SMD0603-21K-1% | https://www.tme.eu/pl/details/smd0603-21k-1%25/rezystory-smd-0603/royal-ohm/0603saf2102t5e/ | C177529
41 | 220Ω 0,1W ±1% -55...155ºC | R16 R17 R46 R47 R57 R62 R65 R66 R77 R78 | 220R | 603 | 10 | https://www.tme.eu/Document/ec37243ca557adb02ebafc5c1ab83104/CQ%20datasheet.pdf | Royal Ohm | CQ03SAF2203T5E | Tme | CQ0603-220K-1% | https://www.tme.eu/pl/details/cq0603-220k-1%25/rezystory-smd-0603/royal-ohm/cq03saf2203t5e/ | C103414
42 | 22Ω 0,1W ±1% -55...155ºC | R12 R15 | 22R | 603 | 2 | https://www.tme.eu/Document/ec37243ca557adb02ebafc5c1ab83104/CQ%20datasheet.pdf | Royal Ohm | CQ03SAF220JT5E | Tme | CQ0603-22R-1% | https://www.tme.eu/pl/details/cq0603-22r-1%25/rezystory-smd-0603/royal-ohm/cq03saf220jt5e/ | C177623
43 | 2kΩ 0,1W ±5% -55...155ºC | R2 R6 | 2k,1% | 603 | 2 | https://www.tme.eu/Document/ec37243ca557adb02ebafc5c1ab83104/CQ%20datasheet.pdf | ROYAL OHM | CQ03SAF2001T5E | Tme | CQ0603-2K-1% | https://www.tme.eu/pl/details/cq0603-2k-1%25/rezystory-smd-0603/royal-ohm/cq03saf2001t5e/ | C234435
44 | 33Ω 63mW ±1% -55...155ºC | R30 R33 R34 R41 R64 R67 R70 | 33R | 402 | 7 | https://www.tme.eu/Document/9e42ba54d36a9bd3dfa2901986ac022d/rezystor-smd.pdf | Royal Ohm | CQ02WGF330JTCE | Tme | CQ0402-33R-1% | https://www.tme.eu/pl/details/cq0402-33r-1%25/rezystory-smd-0402/royal-ohm/cq02wgf330jtce/ | C208868
45 | 36kΩ 0,1W ±5% -55...155ºC | R11 | 36k | 603 | 1 | https://www.tme.eu/Document/9e42ba54d36a9bd3dfa2901986ac022d/rezystor-smd.pdf | Royal Ohm | 0603SAJ0363T5E | Tme | SMD0603-36K | https://www.tme.eu/pl/details/smd0603-36k/rezystory-smd-0603/royal-ohm/0603saj0363t5e/ | C170729
46 | 47kΩ 0,1W ±1% -55...155ºC | R50 | 47k | 603 | 1 | https://www.tme.eu/Document/b315665a56acbc42df513c99b390ad98/ROYALOHM-THICKFILM.pdf | Royal Ohm | 0603SAF4702T5E | Tme | SMD0603-47K-1% | https://www.tme.eu/pl/details/smd0603-47k-1%25/rezystory-smd-0603/royal-ohm/0603saf4702t5e/ | C105579
47 | 49.9Ω 63mW ±1% -55...155ºC | R48 R49 R94 R96 | 49R9_1% | 402 | 4 | https://www.tme.eu/Document/9e42ba54d36a9bd3dfa2901986ac022d/rezystor-smd.pdf | Royal Ohm | 0402WGF499JTCE | Tme | SMD0402-49.9R-1% | https://www.tme.eu/pl/details/smd0402-49.9r-1%25/rezystory-smd-0402/royal-ohm/0402wgf499jtce/ | C325388
48 | 4.7kΩ 0,1W ±5% -55...155ºC | R7 R8 R19 R22 R25 R27 R28 R35 R42 R43 R60 R61 R73 R74 | 4k7 | 603 | 14 | https://www.tme.eu/Document/b315665a56acbc42df513c99b390ad98/ROYALOHM-THICKFILM.pdf | ROYAL OHM | 0603SAF4701T5E | TME | SMD0603-4K7-1% | https://www.tme.eu/pl/details/smd0603-4k7-1%2525/rezystory-smd-0603/royal-ohm/0603saf4701t5e/ | C23162
49 | 4.7kΩ 0,1W ±5% -55...155ºC | R38 | 4k7_NM | 603 | 1 | https://www.tme.eu/Document/b315665a56acbc42df513c99b390ad98/ROYALOHM-THICKFILM.pdf | ROYAL OHM | 0603SAF4701T5E | TME | SMD0603-4K7-1% | https://www.tme.eu/pl/details/smd0603-4k7-1%2525/rezystory-smd-0603/royal-ohm/0603saf4701t5e/
50 | 68kΩ 0,1W ±5% -55...155ºC | R3 | 68k | 603 | 1 | https://www.tme.eu/Document/4f50d320a6ddacb273098f84373b6259/rezystor-smd.pdf | ROYAL OHM | 0603SAF6802T5E | TME | SMD0603-68K-1% | https://www.tme.eu/pl/details/smd0603-68k-1%2525/rezystory-smd-0603/royal-ohm/0603saf6802t5e/ | C228221
51 | 6.49Ω 0,1W ±1% -55...155ºC | R36 | 6k49 | 603 | 1 | https://www.tme.eu/Document/4f50d320a6ddacb273098f84373b6259/rezystor-smd.pdf | ROYAL OHM | 0603SAF6491T5E | Tme | SMD0603-6K49-1% | https://www.tme.eu/pl/details/smd0603-6k49-1%25/rezystory-smd-0603/royal-ohm/0603saf6491t5e/ | C269508
52 | VisionSOM-STM32MP1 based on STM32MP157AABxx LFBGA354 SD Card in SODIMM footprint | SOM1 | VisionSOM-STM32MP1 | SODIMM | 1 | https://somlabs.com/product/visionsom-stm32mp1-stm32mp157/ | Somlabs | VisionSOM-STM32MP1 | Soyter | Som000025 | https://soyter.pl/system-on-module-somlabs-visionsom-sls18mp157a_650c_512r_usd_0sf_c,c223,p2459,pl.html
53 | Wurth Electronics Tactile Switches WS-TASV SMD Switch 3.5x2.9 x1.7mm Jbend | Sw1 Sw2 | 434153017835 | 3.5x2.9 x1.7mm | 2 | https://pl.mouser.com/datasheet/2/445/434153017835-1717089.pdf | Wurth Electronics | 434153017835 | Mouser | 710-434153017835 | https://pl.mouser.com/ProductDetail/Wurth-Elektronik/434153017835?qs=DvsTirrhYfPgFeivYdn0UQ%3D%3D
54 | LAN-Transformer WE-RJ45LAN 10/100BaseT - 40ºC to + 85ºC | CON7 | LMJ3628844TA753 | Through Hole | 1 | https://www.tme.eu/Document/7dff8992a9b9ebe0d6e0b648b26633ee/LMJ362884XTA753.pdf | AMPHENOL | LMJ3628844TA753 | Tme | LMJ3628844TA753 | https://www.tme.eu/pl/details/lmj3628844ta753/zlacza-rj/amphenol/
55 | Microcontroller Supervisory Circuit with Open Drain Output | U10 | APX803D-29SRG-7 | SOT-23R | 1 | https://pl.mouser.com/datasheet/2/115/APX803-D-Not-Recommended-1512836.pdf | Diodes Incorporated | APX803D-29SRG-7 | Mouser | 621-APX803D-29SRG-7 | https://pl.mouser.com/ProductDetail/Diodes-Incorporated/APX803D-29SRG-7?qs=j2HO5yQWbRfWqxaJ%252BVX6CA%3D%3D | C460556
56 | Dual USB 2.0 integrated ESD protection | U11 U12 U13 U14 U15 U16 U17 U18 U19 | IP4220CZ6 | SOT-457 | 9 | https://www.tme.eu/Document/8d0df3f4f949e8290c51efff41085b51/IP4220CZ6.pdf | NEXPERIA | IP4220CZ6.125 | TME | IP4220CZ6 | https://www.tme.eu/pl/details/ip4220cz6/diody-zabezpieczajace-drabinki/nexperia/ip4220cz6-125/ | C2687127
57 | MII/RMII 10BASE-T/100BASE-TX Physical Layer Transceiver | U7 | KSZ8041NL_RNL | QFN-32 | 1 | https://pl.mouser.com/datasheet/2/268/00002245B-1369279.pdf | Microchip / Micrel | KSZ8041NL-TR | Mouser | 998-KSZ8041NLTR | https://pl.mouser.com/ProductDetail/Microchip-Technology-Micrel/KSZ8041NL-TR/?qs=U6T8BxXiZAVZIRxJn65IVw%3D%3D | C11146
58 | 3V3 / 250mA Low Dropout Positive Voltage Regulator | U6 | MCP1700T-3302E_MB | SOT89 | 1 | https://www.tme.eu/Document/952a4cca9caea28f850f0bc3e82de190/MCP1700-3002ETO.pdf | Microchip Technology | MCP1700T-3302E/MB | TME | MCP1700T-3302E/MB | https://www.tme.eu/pl/details/mcp1700t-3302e_mb/stabilizatory-napiecia-nieregulowane-ldo/microchip-technology/ | C108493
59 | 3V3 / 250mA Low Dropout Positive Voltage Regulators (Quiescent Current) | U2 | MCP1703T-3302E | SOT23 | 1 | https://www.tme.eu/Document/de7d38f249f36fadffea0e6430703bcf/_LDO_SG.pdf | MICROCHIP TECHNOLOGY | MCP1703T-3302E/CB | Tme | MCP1703T3302ECB | https://www.tme.eu/pl/details/mcp1703t3302ecb/stabilizatory-napiecia-nieregulowane-ldo/microchip-technology/mcp1703t-3302e-cb/ | C39051
60 | 2 A, 1.5 MHz PWM step-down switching regulator with synchronous rectification | U4 | ST1S09IPUR | DFN-6 | 1 | https://pl.mouser.com/datasheet/2/389/st1s09-1850123.pdf | ST Microelectronics | ST1S09IPUR | Mouser | 511-ST1S09IPUR | https://pl.mouser.com/ProductDetail/STMicroelectronics/ST1S09IPUR?qs=z4PnFkYVEVnLKA2ltiW6RQ%3D%3D | C361028
61 | IOUT=3A MAX_VOUT=15V VIN=18V 900kHz step down regulator | U3 | ST1S10PHR | SOIC-8 | 1 | https://pl.mouser.com/datasheet/2/389/st1s10-1850024.pdf | ST Microelectronics | ST1S10PHR | Mouser | 511-ST1S10PHR | https://pl.mouser.com/ProductDetail/STMicroelectronics/ST1S10PHR?qs=qolwYojYp3QSBN7PdO5xhg%3D%3D | C11175
62 | Medium-density performance line ARMÂ®-based 32-bit MCU with 64 or 128 KB Flash, USB, CAN, 7 timers, 2 ADCs, 9 com. interfaces | U5 | STM32F103C(8-B)Tx | LQFP-48 | 1 | https://pl.mouser.com/datasheet/2/389/stm32f103c8-1851025.pdf | ST Microelectronics | STM32F103CBT6 | Mouser | 511-STM32F103CBT6 | https://pl.mouser.com/ProductDetail/STMicroelectronics/STM32F103CBT6/?qs=WxFF5lh7QM3goh6GV5Ogig%3D%3D | C8304
63 | LED Lighting Drivers TPS61169 38-V High Current-Boost WLED Driver With PWM Control | U1 | TPS61169DCKR | SC70-5 | 1 | http://www.ti.com/general/docs/suppproductinfo.tsp?distId=26 | Texat Instruments | TPS61169DCKR | Mouser | 595-TPS61169DCKR | https://pl.mouser.com/ProductDetail/Texas-Instruments/TPS61169DCKR | C71045
64 | Very low capacitance ESD protection 2 data line protection 3.5pF 150nA leakage current | U8 U9 | USBLC6-2 | SOT23-6 | 2 | https://www.tme.eu/Document/db59d28d28a96c34f26d05f234ff409c/USBLC6-2.pdf | STMicroelectronics | USBLC6-2SC6 | Tme | USBLC6-2SC6 | https://www.tme.eu/pl/details/usblc6-2sc6/diody-zabezpieczajace-drabinki/stmicroelectronics/ | C7519
65 | USB Connectors WR-COM Type A SMT 4Pin Horztl Female | USB1 | USB-A-Wurth-62900416021 | USB Type A Connectors SMT | 1 | https://pl.mouser.com/datasheet/2/445/62900416021-1718169.pdf | Wurth | 62900416021 | Mouser | 710-62900416021 | https://pl.mouser.com/ProductDetail/?qs=7gQLVZk5cPluNNYrEeR0bw==
66 | 8MHz Abracon 5mm x 3.2mm SMD Crystal Resonator | X1 | 8.000MHZ | 5032 | 1 | Resonators/Components_Documentation/ABM8G-106-12.000MHz-T.pdf | ABRACON | ABM3AIG-8.000MHZ-8-1R-T | Mouser | 815-ABM8G-106-12-T | https://pl.mouser.com/ProductDetail/ABRACON/ABM3AIG-8000MHZ-8-1R-T | C156253

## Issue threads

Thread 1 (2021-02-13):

Dsi Panel reset panel

voloviq, 2021-02-13:
During yocto bring-up discover that reset pin is necessary for and dts. Unfortunately, there are insufficient available ports.

voloviq, 2021-02-13:
Considering change ethernet from MII to RMII. This allows 4 port to be free.

voloviq, 2021-05-25:
Resolved in different solution

Closed 2021-05-25.

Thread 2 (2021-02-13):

Mistake port id on schematic

voloviq, 2021-02-13:
During the system, bring-up discover that one of the i2c connected to touch panel. Change PE2_I2C4_SDA to PB7_I2C4_SDA.

voloviq, 2021-05-25:
Corrected.

Closed 2021-05-25.

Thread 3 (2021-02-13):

Arduino Shield

voloviq, 2021-02-13:
The AREF pin is nowhere connected on the Arduino shield.

voloviq, 2021-05-25:
Corrected.

Closed 2021-05-25.

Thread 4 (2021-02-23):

Wrong capacitor used for MCP1703T-3302E

voloviq, 2021-02-23:
Discover the wrong capacitor used for MCP1703T-3302E.
According to the documentation, output capacitance should be 1uF at least.

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

Currently, used capacitors are only 100nF.

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

Replace in BOM and on schematic capacitors from 100nF to 1uF.

voloviq, 2021-02-23:
Applied

Closed 2021-02-23.

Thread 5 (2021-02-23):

BOM błędna specyfikacja LDO

voloviq, 2021-02-23:
The wrong part number of LDO U2 discover on 54 positions in BOM
Link go trough
https://www.tme.eu/pl/details/mcp1703t-3302e_db/stabilizatory-napiecia-nieregulowane-ldo/microchip-technology/
Correctly part number is specified in LCSC Part #(optional).
Proper LDO should be **MCP1700T-3302E/TT**

https://www.tme.eu/pl/details/mcp1700t3302ett/stabilizatory-napiecia-nieregulowane-ldo/microchip-technology/mcp1700t-3302e-tt/

Update BOM and schematic part.

voloviq, 2021-02-23:
Issue applied

Closed 2021-02-23.

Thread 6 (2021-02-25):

Rak833 wrong connections

voloviq, 2021-02-25:
During bring up procedure discover the wrong pin set on RAK833 and some pins unavailable.

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

Adopt freed signals to other functions with other modules

voloviq, 2021-05-25:
Corrected.

Closed 2021-05-25.

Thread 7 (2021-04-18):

Ethernet problem PG13/PG14

voloviq, 2021-04-18:
Discover that TXD0 is missing. Currently, ENET1_TXD0 is assigned to PG14 but PG14 have no TXD0 function. PG13 has a TXD0 function so PG13 and PG14 need to be swapped.

voloviq, 2021-05-25:
Corrected.

Closed 2021-05-25.

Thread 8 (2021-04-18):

Backlight dc-dc konverter wrong track size

voloviq, 2021-04-18:
Discover that 3.3V line which supply TPS backlight dc-dc have too thin track. On the output, lines backlight high and low can be 10mils due to high voltage about 22VDC with max current 60mA. Instead of using power track use polygons.

voloviq, 2021-05-25:
Not necessary.

Closed 2021-05-25.

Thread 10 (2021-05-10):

3V3 DC-DC Converter wrong connected

voloviq, 2021-05-10:
During board bring up DC-DC converter is wrong connected to the main power supply. This converter should be connected to 5V due to its limit to 6V max.

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

voloviq, 2021-05-25:
Correted.

Closed 2021-05-25.

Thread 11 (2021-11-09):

Ethernet power supply wrong connections

voloviq, 2021-11-09:
Discover wrong connection in the power supply path - connect 3V3 to C38.
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

voloviq, 2025-02-03:
Postponed maybe in future.

Closed 2025-02-03.

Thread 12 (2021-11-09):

Wrong connection on separate transformer

voloviq, 2021-11-09:
Documentation order to the following connection

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

Align to schematic and on PCB

voloviq, 2025-02-03:
Postponed maybe in future.

Closed 2025-02-03.

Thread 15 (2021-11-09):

IRQ change pin

voloviq, 2021-11-09:
According to CubeMX change, IRQ pin from PE12 to PG12, just swap the pins

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

voloviq, 2025-02-03:
Postponed maybe in future.

Closed 2025-02-03.

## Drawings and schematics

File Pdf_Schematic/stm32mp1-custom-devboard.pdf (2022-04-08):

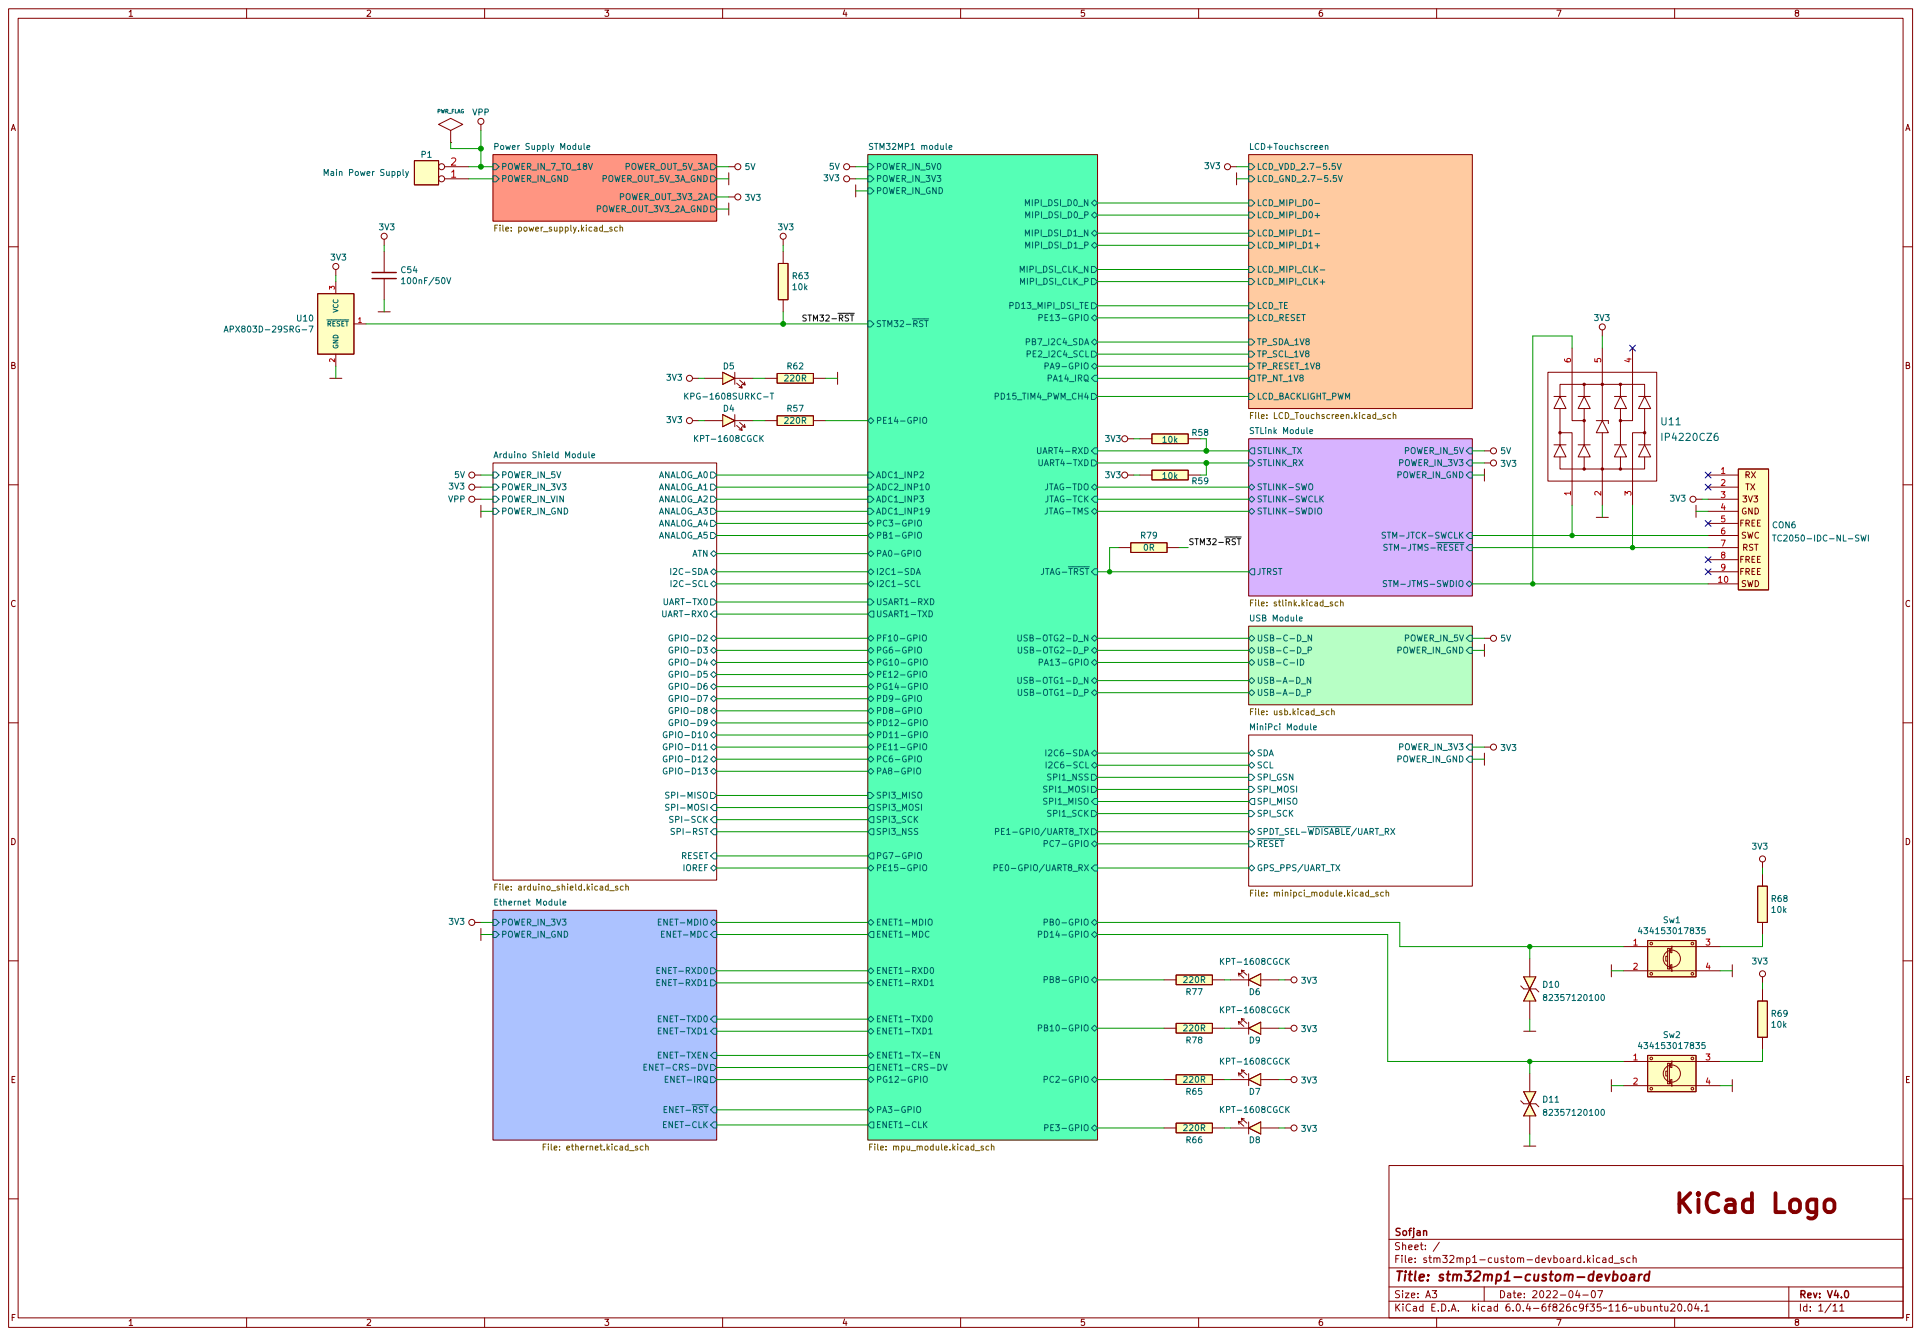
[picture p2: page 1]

Arduino Shield Module File: arduino_shield.kicad_sch

8 10

I2C-SDA
I2C-SCL UART-TX0 UART-RX0 GPIO-D2 GPIO-D3 GPIO-D4 GPIO-D5 GPIO-D6 GPIO-D7 GPIO-D8 GPIO-D9 GPIO-D10 GPIO-D11 GPIO-D12 GPIO-D13 SPI-MISO

USB Module File: usb.kicad_sch

SCL SDA MiniPci Module File: minipci_module.kicad_sch

SPI-MOSI SPI-SCK

IOREF
ENET-RXD0 ENET-TXD1 ENET-TXD0 ENET-MDC

ENET-~{RST} Ethernet Module File: ethernet.kicad_sch

File: stm32mp1-custom-devboard.kicad_sch Sheet: / Sofjan

Id: 1/11 Title: stm32mp1-custom-devboard

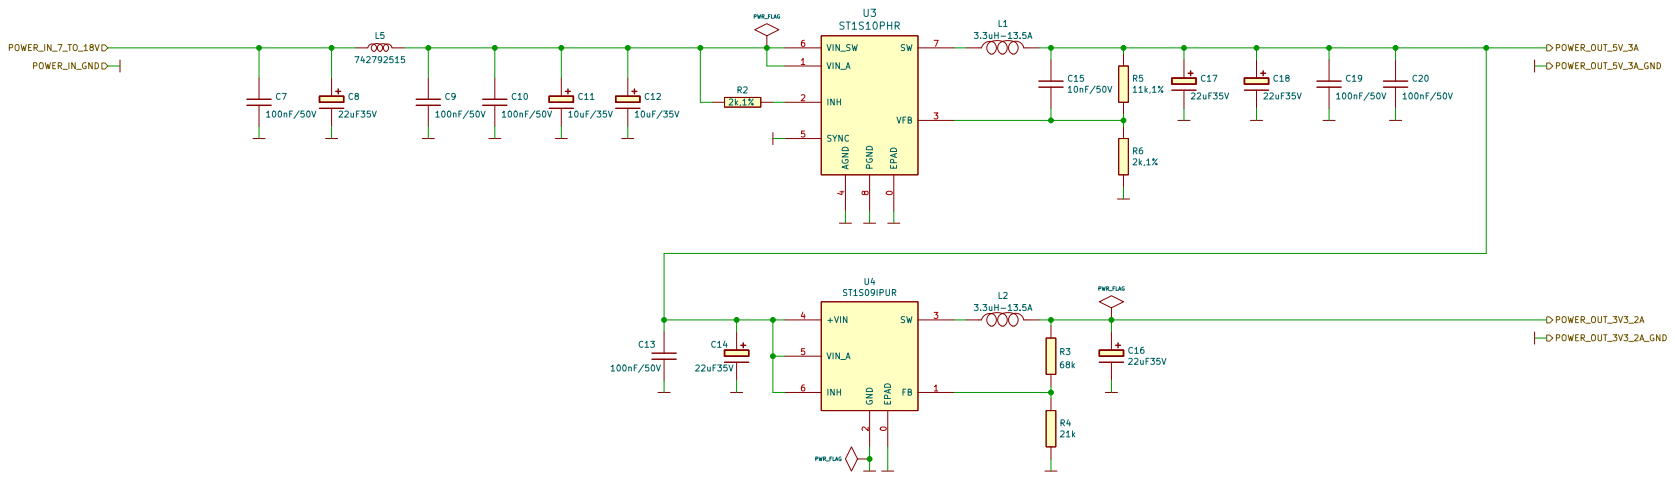
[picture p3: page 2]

Embedded System Labs
Sheet: /Power Supply Module/
File: power_supply.kicad_sch
Id: 2/11 Title: Power Supply Module 5V/3V3

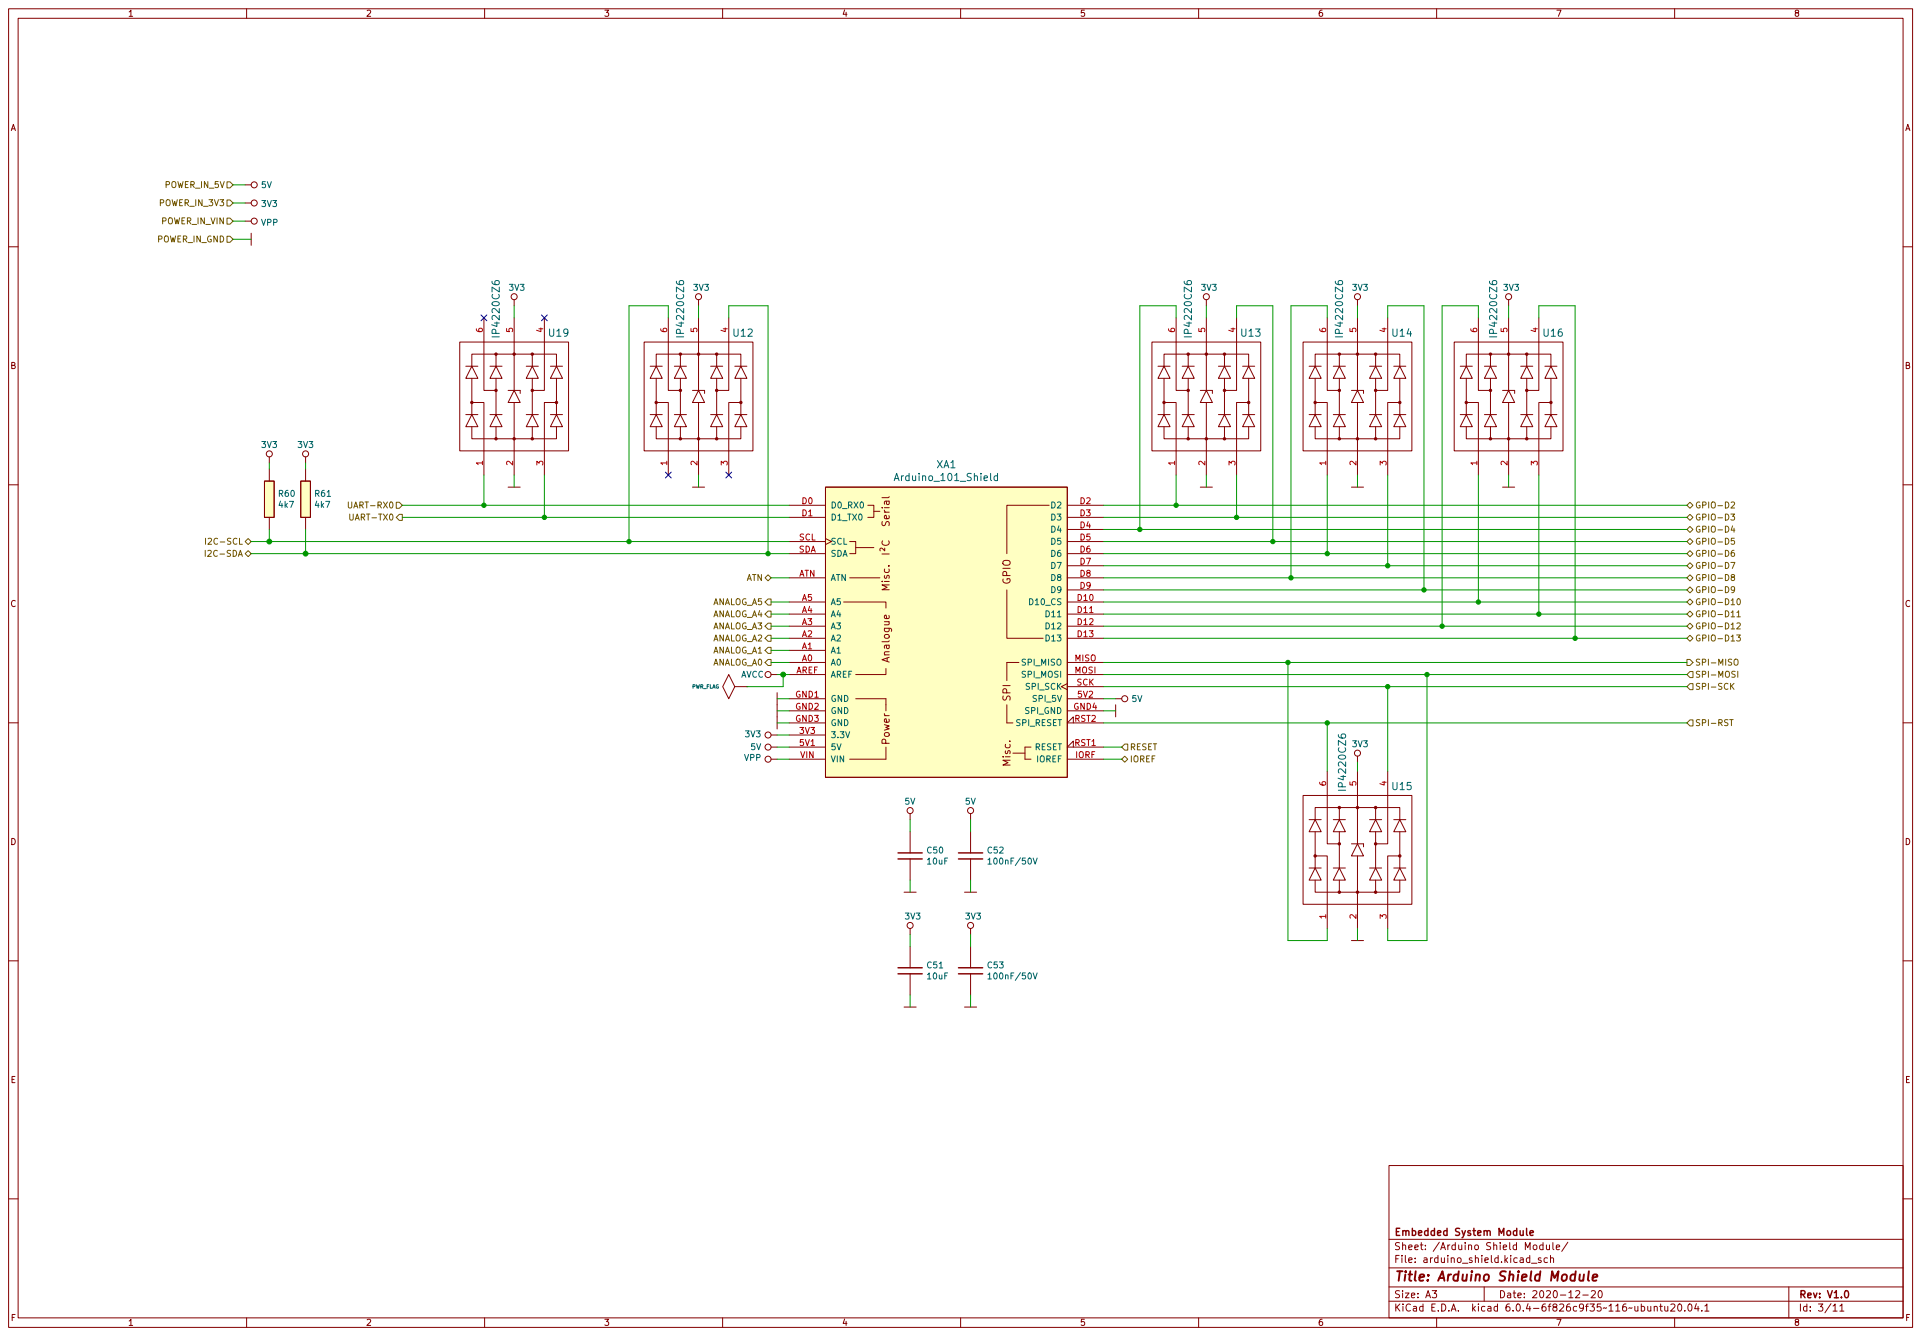
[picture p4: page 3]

File: arduino_shield.kicad_sch Sheet: /Arduino Shield Module/ Embedded System Module

Id: 3/11 Title: Arduino Shield Module

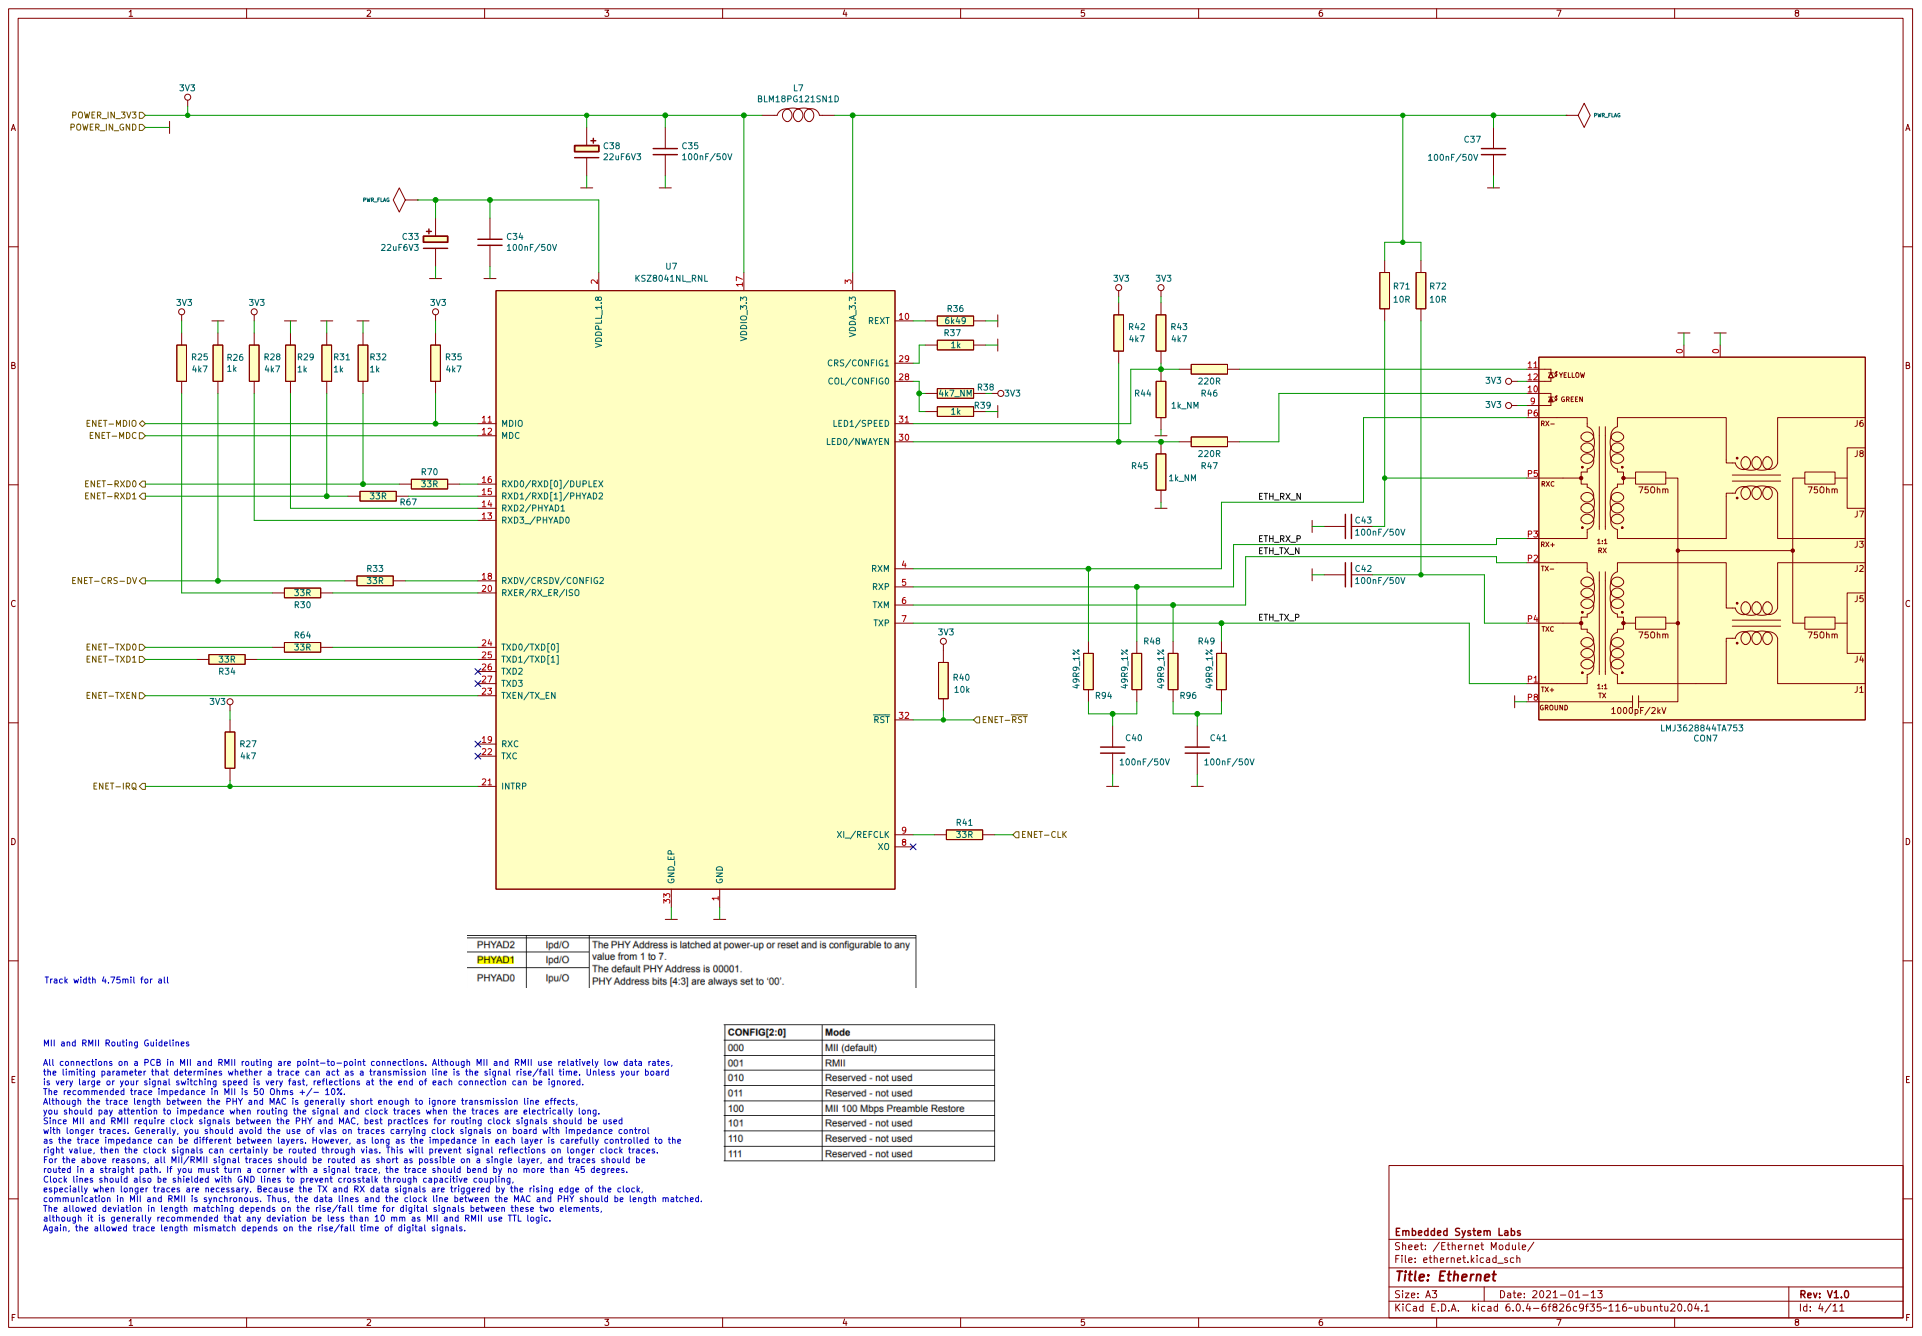
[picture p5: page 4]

1 REXT 10 MDIO 11 MDC 12 RXD3_/PHYAD0 13 RXD2/PHYAD1 14 RXD1/RXD[1]/PHYAD2 15 RXD0/RXD[0]/DUPLEX 16 VDDIO_3.3 17 RXDV/CRSDV/CONFIG2 18 RXC 19 VDDPLL_1.8

ENET-~{RST} ENET-MDIO
ENET-MDC

J8 RX RX+ RX- RXC

ENET-RXD0 ENET-RXD1 ENET-CRS-DV

Track width 4.75mil for all MII and RMII Routing Guidelines

All connections on a PCB in MII and RMII routing are point-to-point connections. Although MII and RMII use relatively low data rates,
the limiting parameter that determines whether a trace can act as a transmission line is the signal rise/fall time. Unless your board
is very large or your signal switching speed is very fast, reflections at the end of each connection can be ignored.
The recommended trace impedance in MII is 50 Ohms +/- 10%.
Although the trace length between the PHY and MAC is generally short enough to ignore transmission line effects,
you should pay attention to impedance when routing the signal and clock traces when the traces are electrically long.
Since MII and RMII require clock signals between the PHY and MAC, best practices for routing clock signals should be used
with longer traces. Generally, you should avoid the use of vias on traces carrying clock signals on board with impedance control
as the trace impedance can be different between layers. However, as long as the impedance in each layer is carefully controlled to the
right value, then the clock signals can certainly be routed through vias. This will prevent signal reflections on longer clock traces.
For the above reasons, all MII/RMII signal traces should be routed as short as possible on a single layer, and traces should be
routed in a straight path. If you must turn a corner with a signal trace, the trace should bend by no more than 45 degrees.
Clock lines should also be shielded with GND lines to prevent crosstalk through capacitive coupling,
especially when longer traces are necessary. Because the TX and RX data signals are triggered by the rising edge of the clock,
communication in MII and RMII is synchronous. Thus, the data lines and the clock line between the MAC and PHY should be length matched.
The allowed deviation in length matching depends on the rise/fall time for digital signals between these two elements,
although it is generally recommended that any deviation be less than 10 mm as MII and RMII use TTL logic.
Again, the allowed trace length mismatch depends on the rise/fall time of digital signals.

File: ethernet.kicad_sch Sheet: /Ethernet Module/ Embedded System Labs

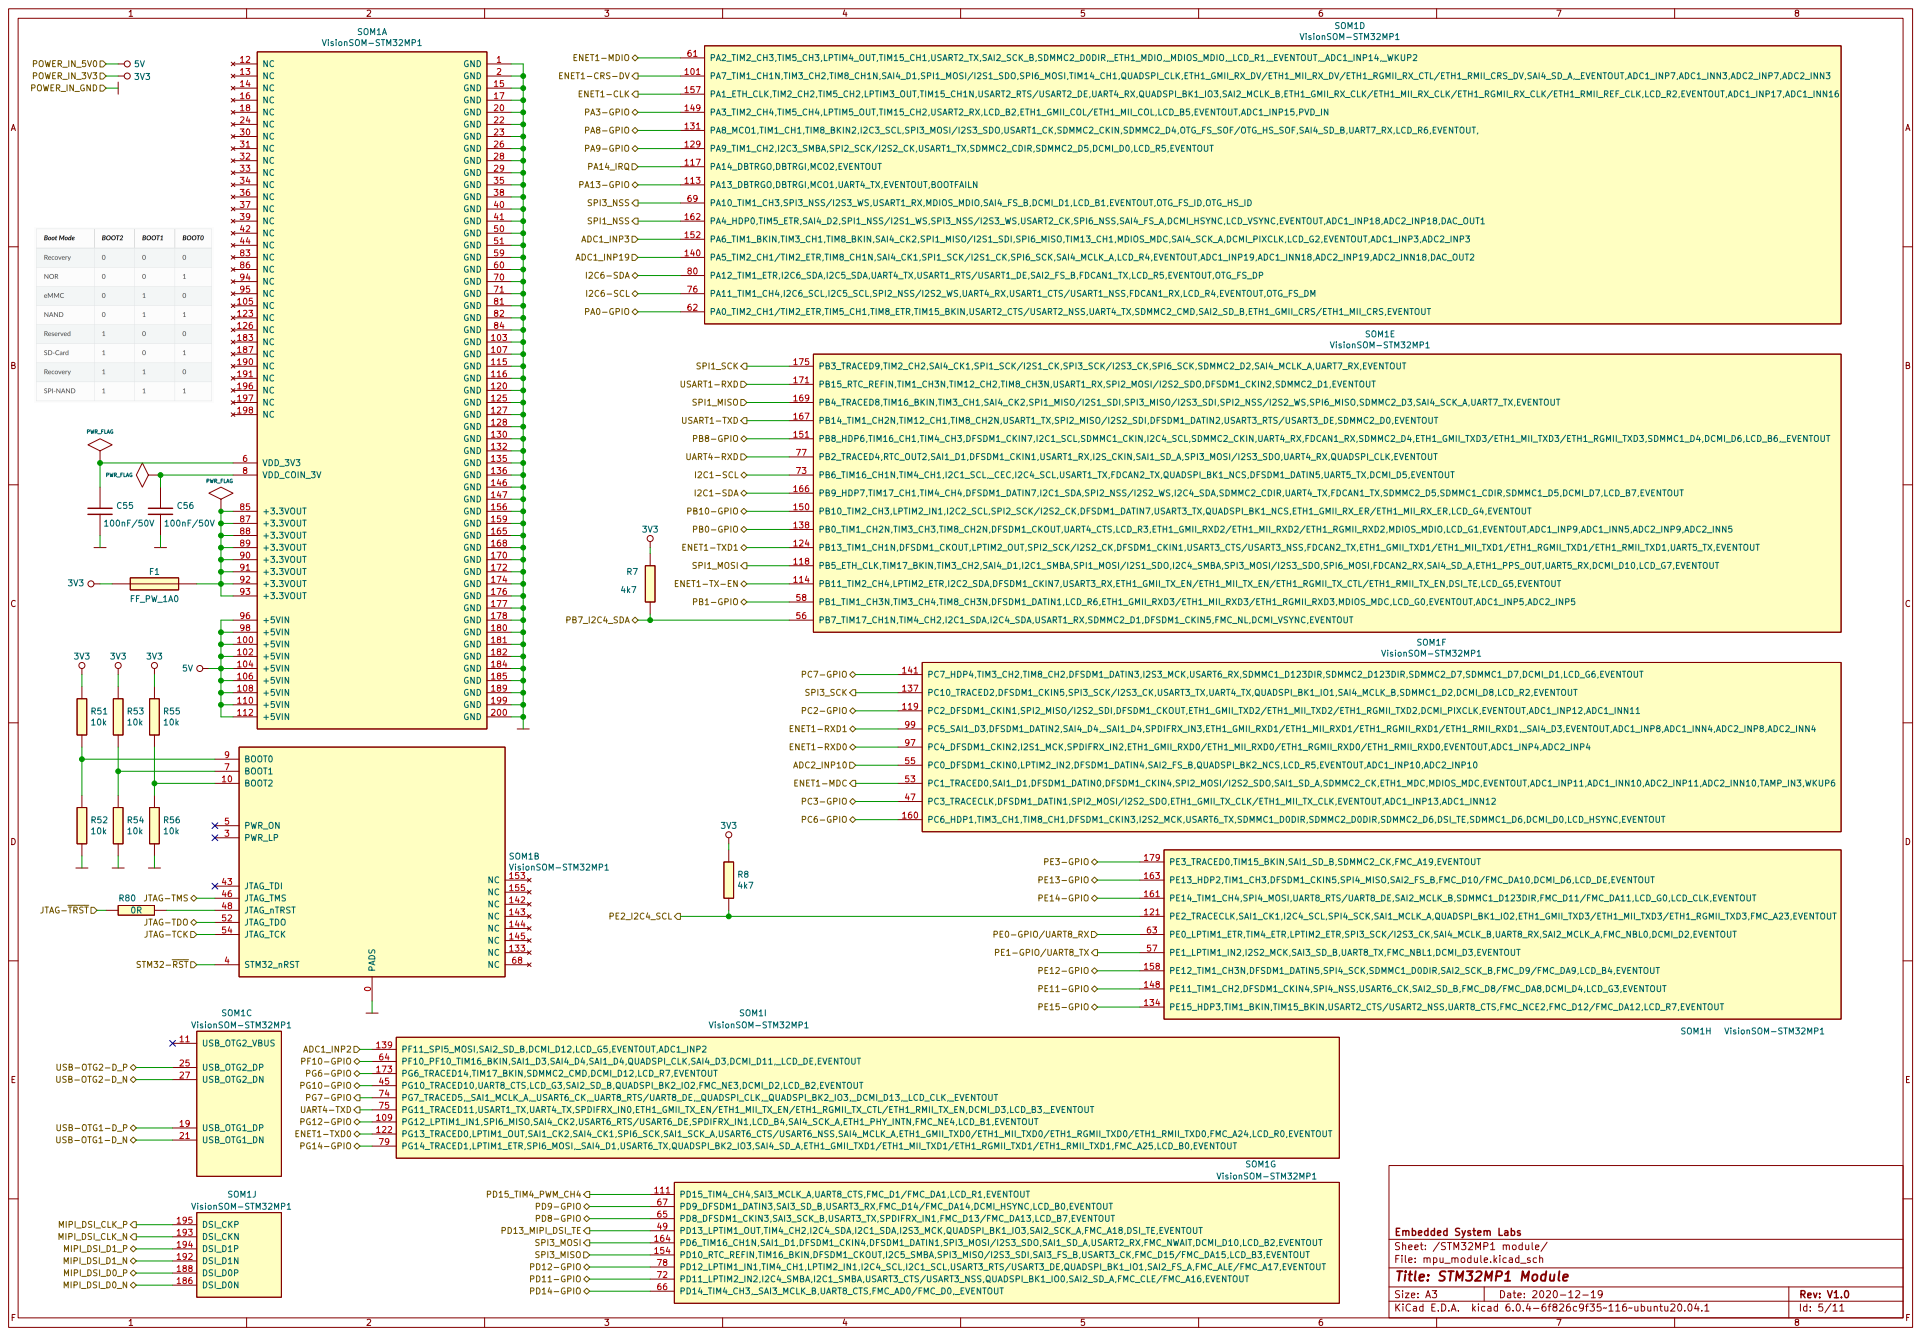
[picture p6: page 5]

0 BOOT2 10 NC 133 NC 142 NC 143 NC 144 NC 145 NC 153 NC 155 PWR_LP 3 STM32_nRST 4

File: mpu_module.kicad_sch Sheet: /STM32MP1 module/ Embedded System Labs R54

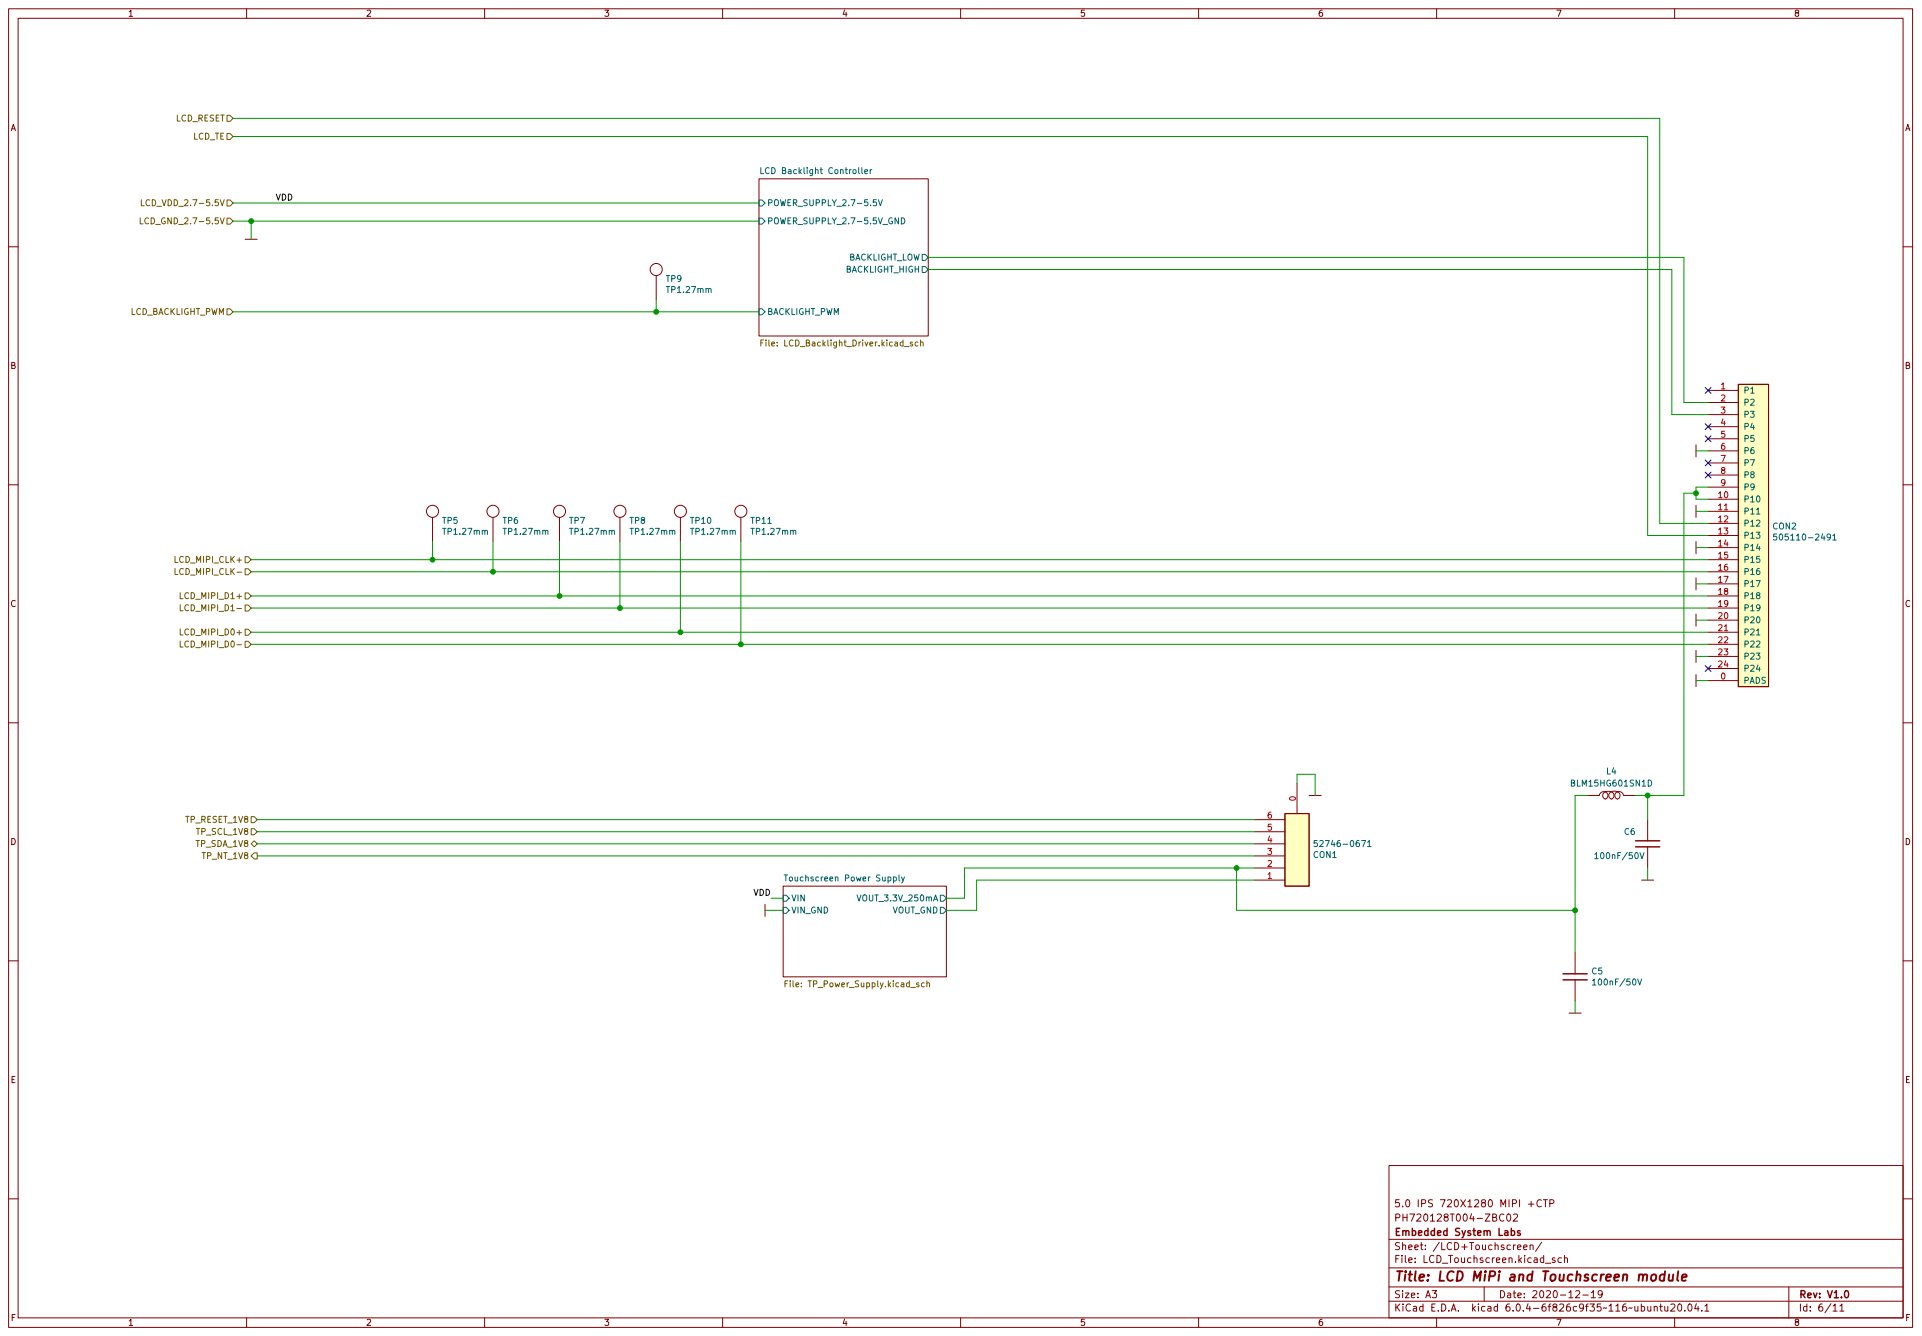
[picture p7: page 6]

5.0 IPS 720X1280 MIPI +CTP
File: LCD_Touchscreen.kicad_sch Sheet: /LCD+Touchscreen/ Embedded System Labs PH720128T004-ZBC02

Id: 6/11 Title: LCD MiPi and Touchscreen module

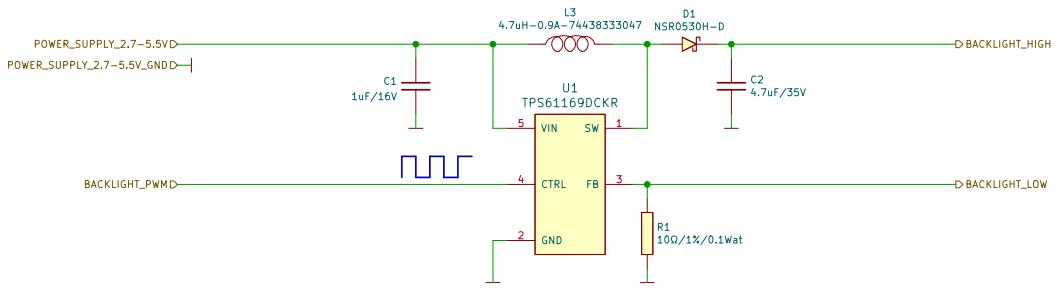
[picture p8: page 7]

Embedded System Labs
Sheet: /LCD+Touchscreen/LCD Backlight Controller/
File: LCD_Backlight_Driver.kicad_sch
Id: 7/11 Title: LCD Backlight Controller

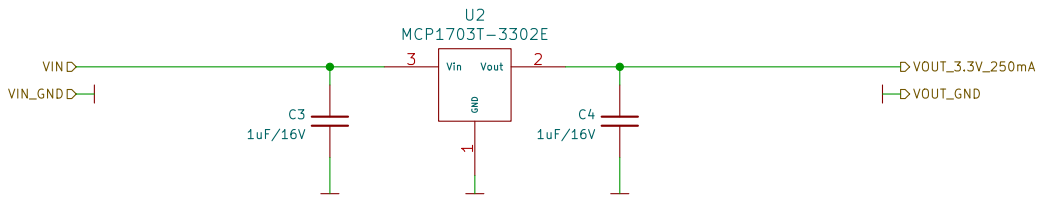
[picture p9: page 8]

Embedded System Labs GND 1

Sheet: /LCD+Touchscreen/Touchscreen Power Supply/
File: TP_Power_Supply.kicad_sch
Id: 8/11 Title: 2.8V LDO Regulator

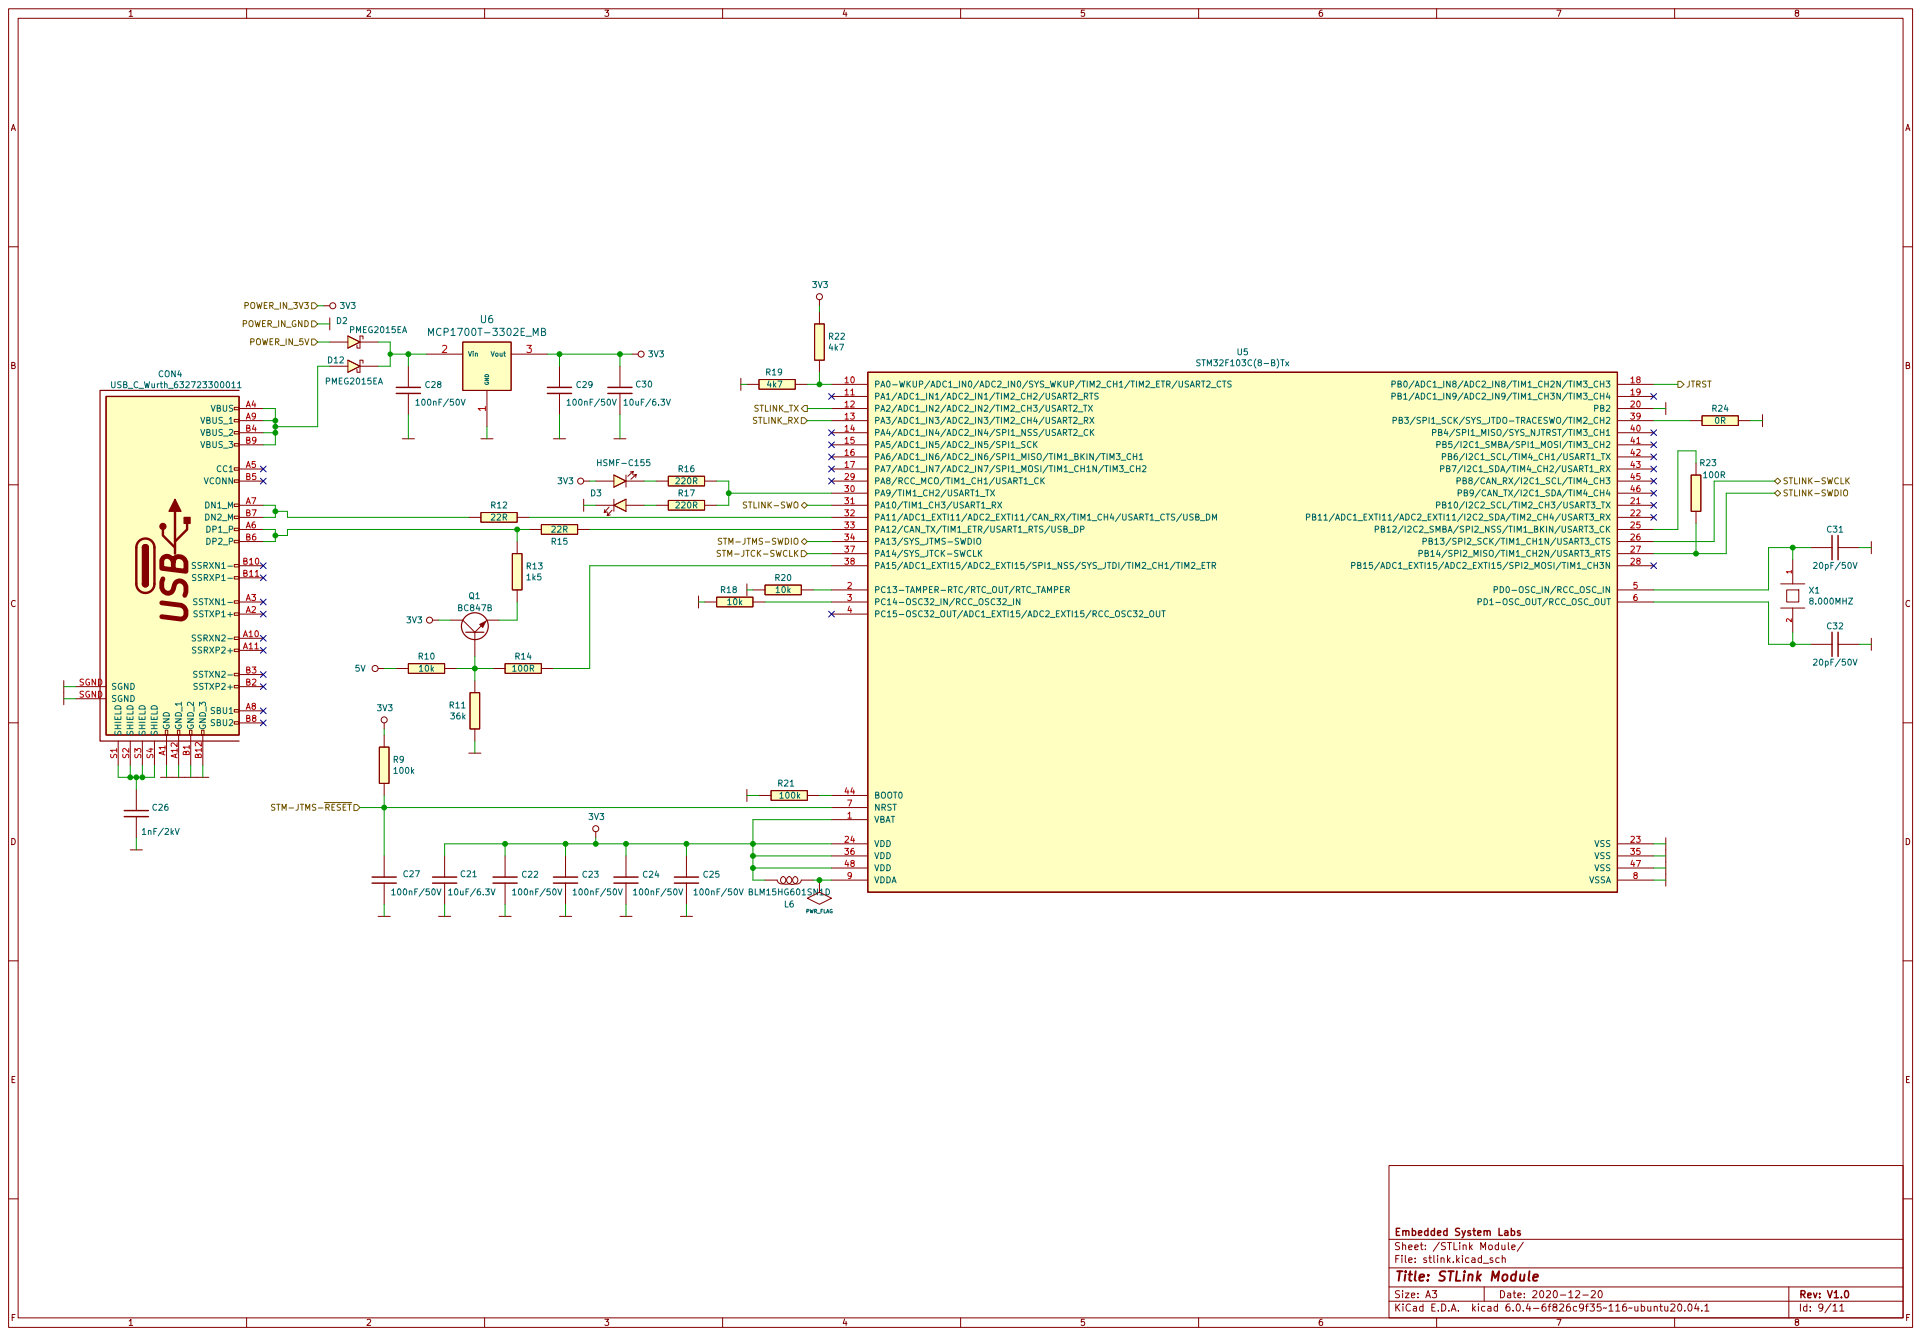
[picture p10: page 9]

File: stlink.kicad_sch Sheet: /STLink Module/ Embedded System Labs

Id: 9/11 Title: STLink Module

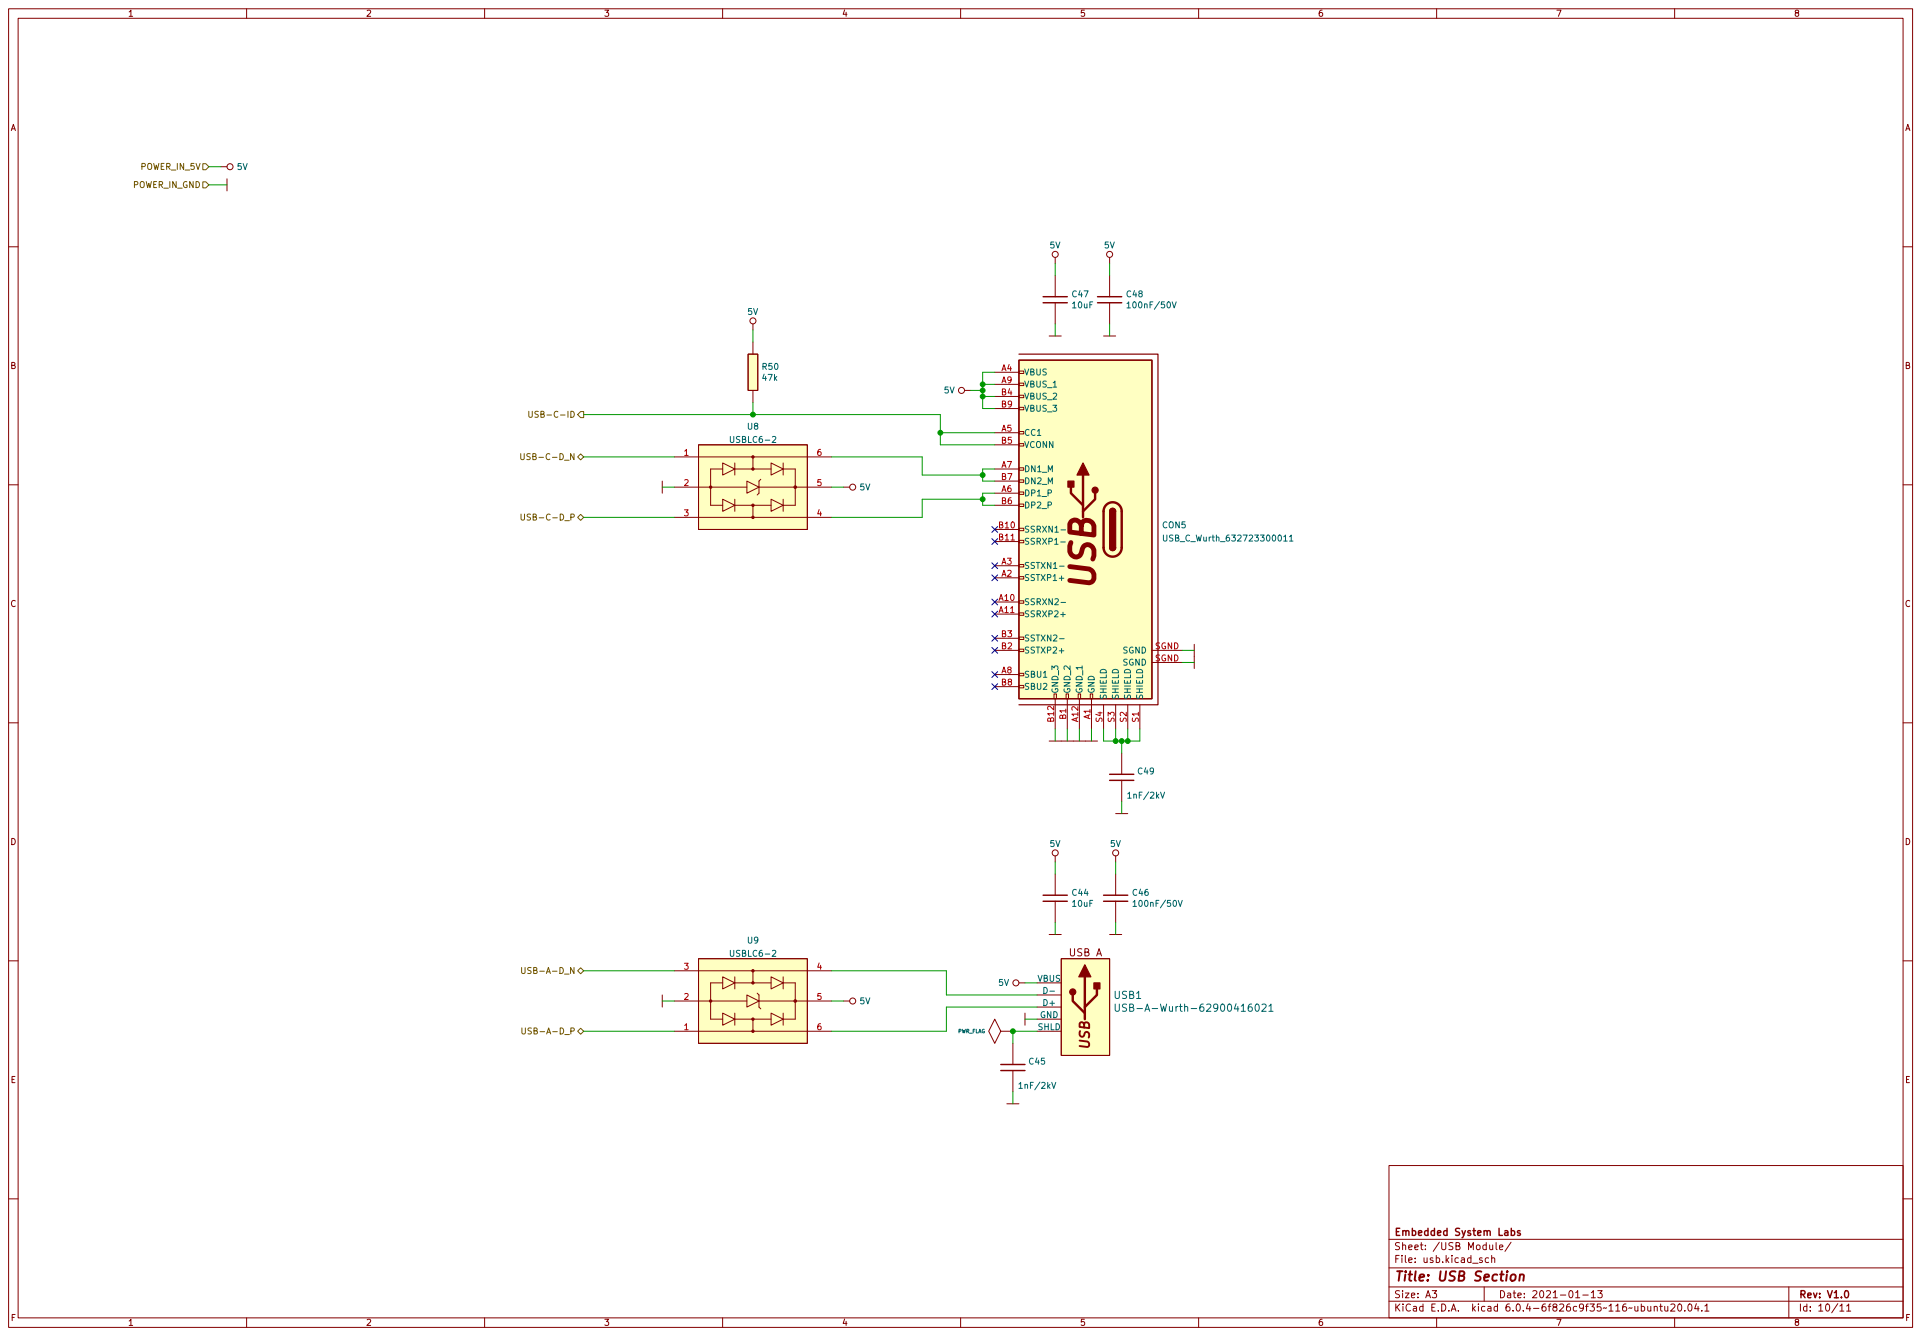
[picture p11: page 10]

File: usb.kicad_sch Sheet: /USB Module/ Embedded System Labs

Id: 10/11 Title: USB Section

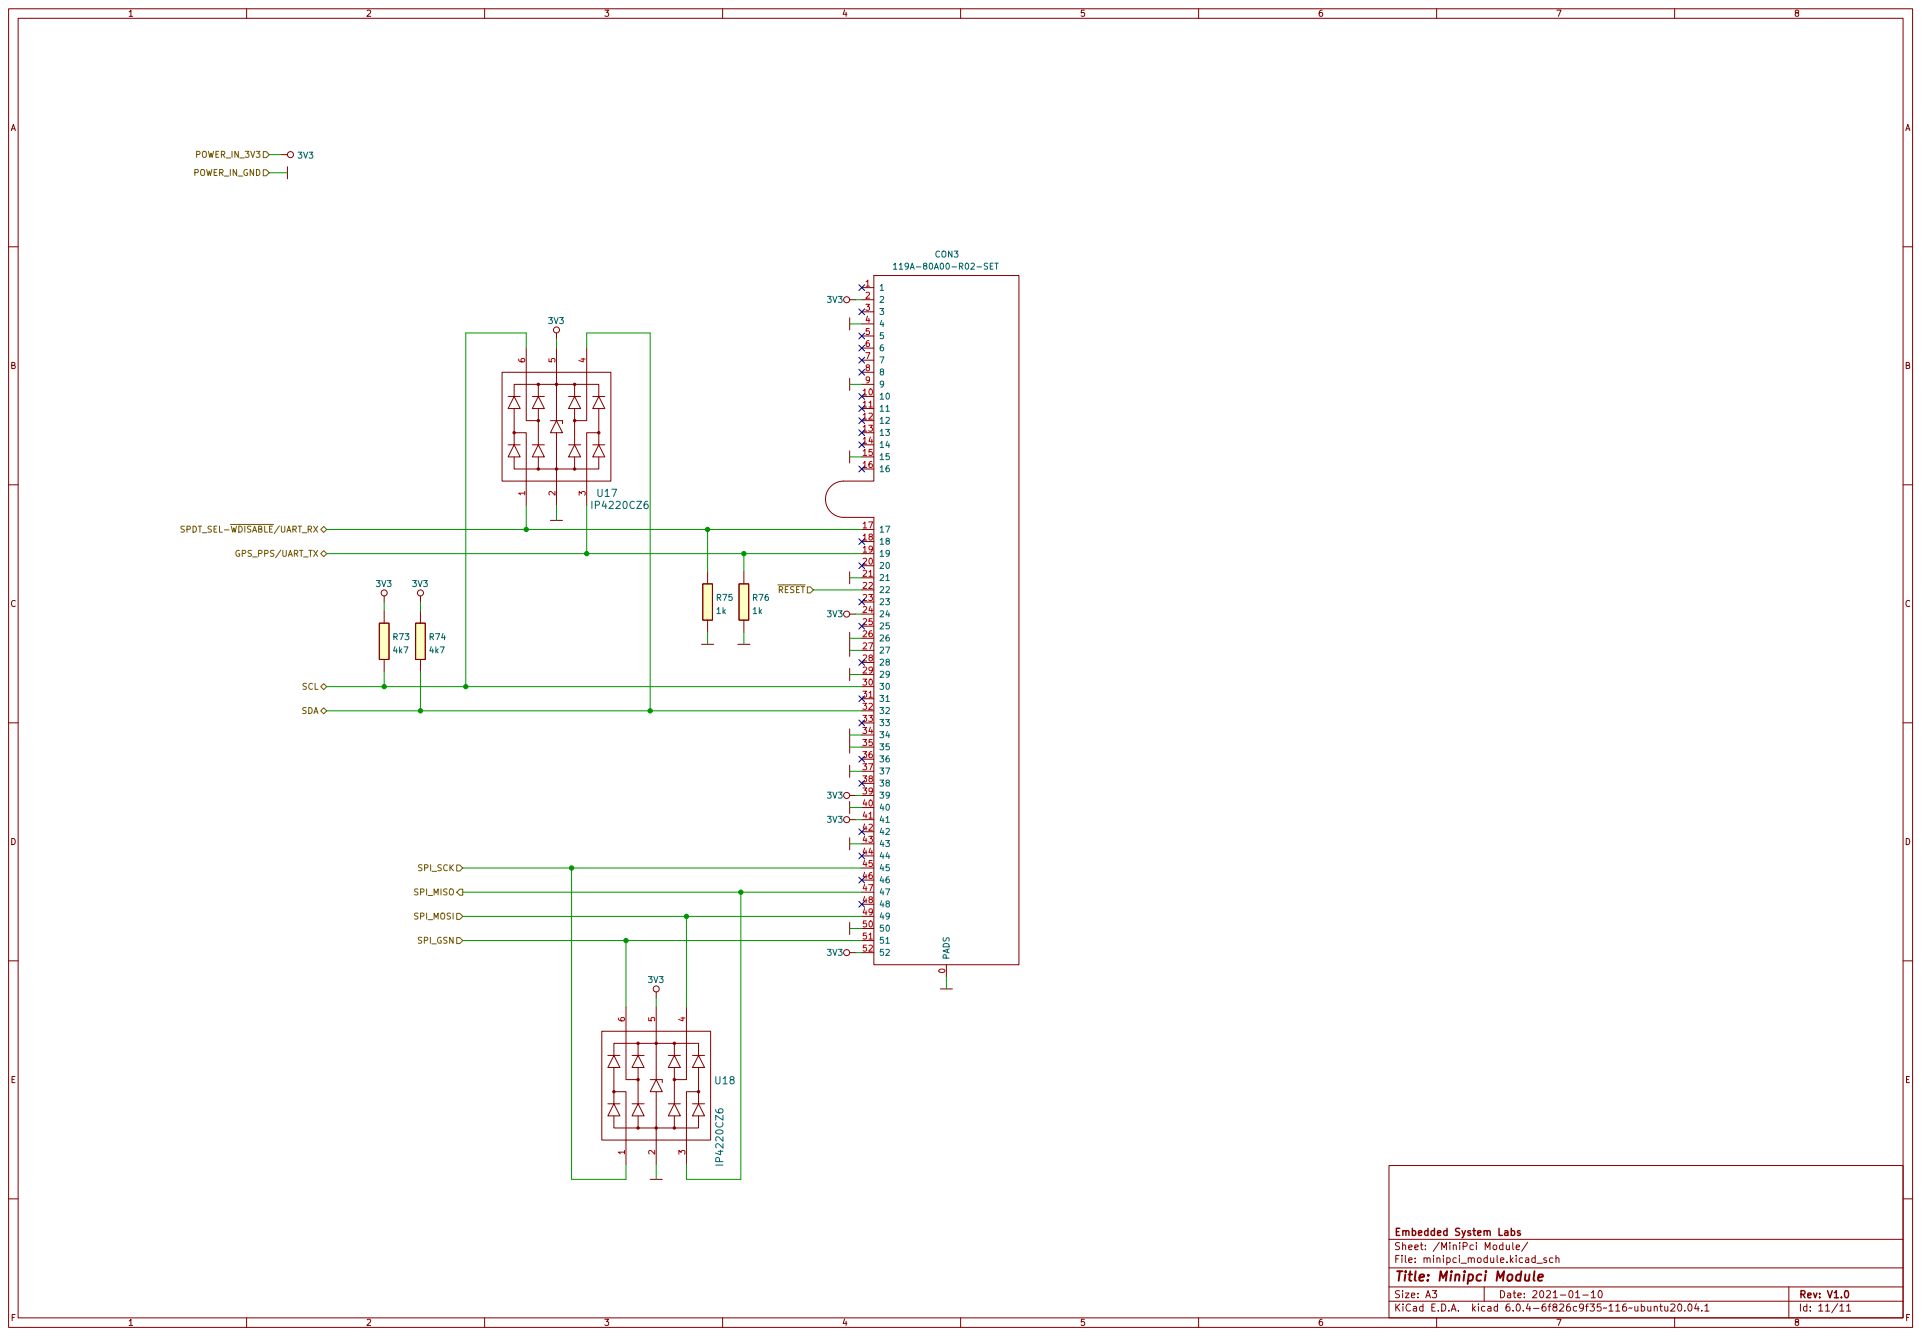
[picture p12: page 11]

File: minipci_module.kicad_sch Sheet: /MiniPci Module/ Embedded System Labs

Id: 11/11 Title: Minipci Module

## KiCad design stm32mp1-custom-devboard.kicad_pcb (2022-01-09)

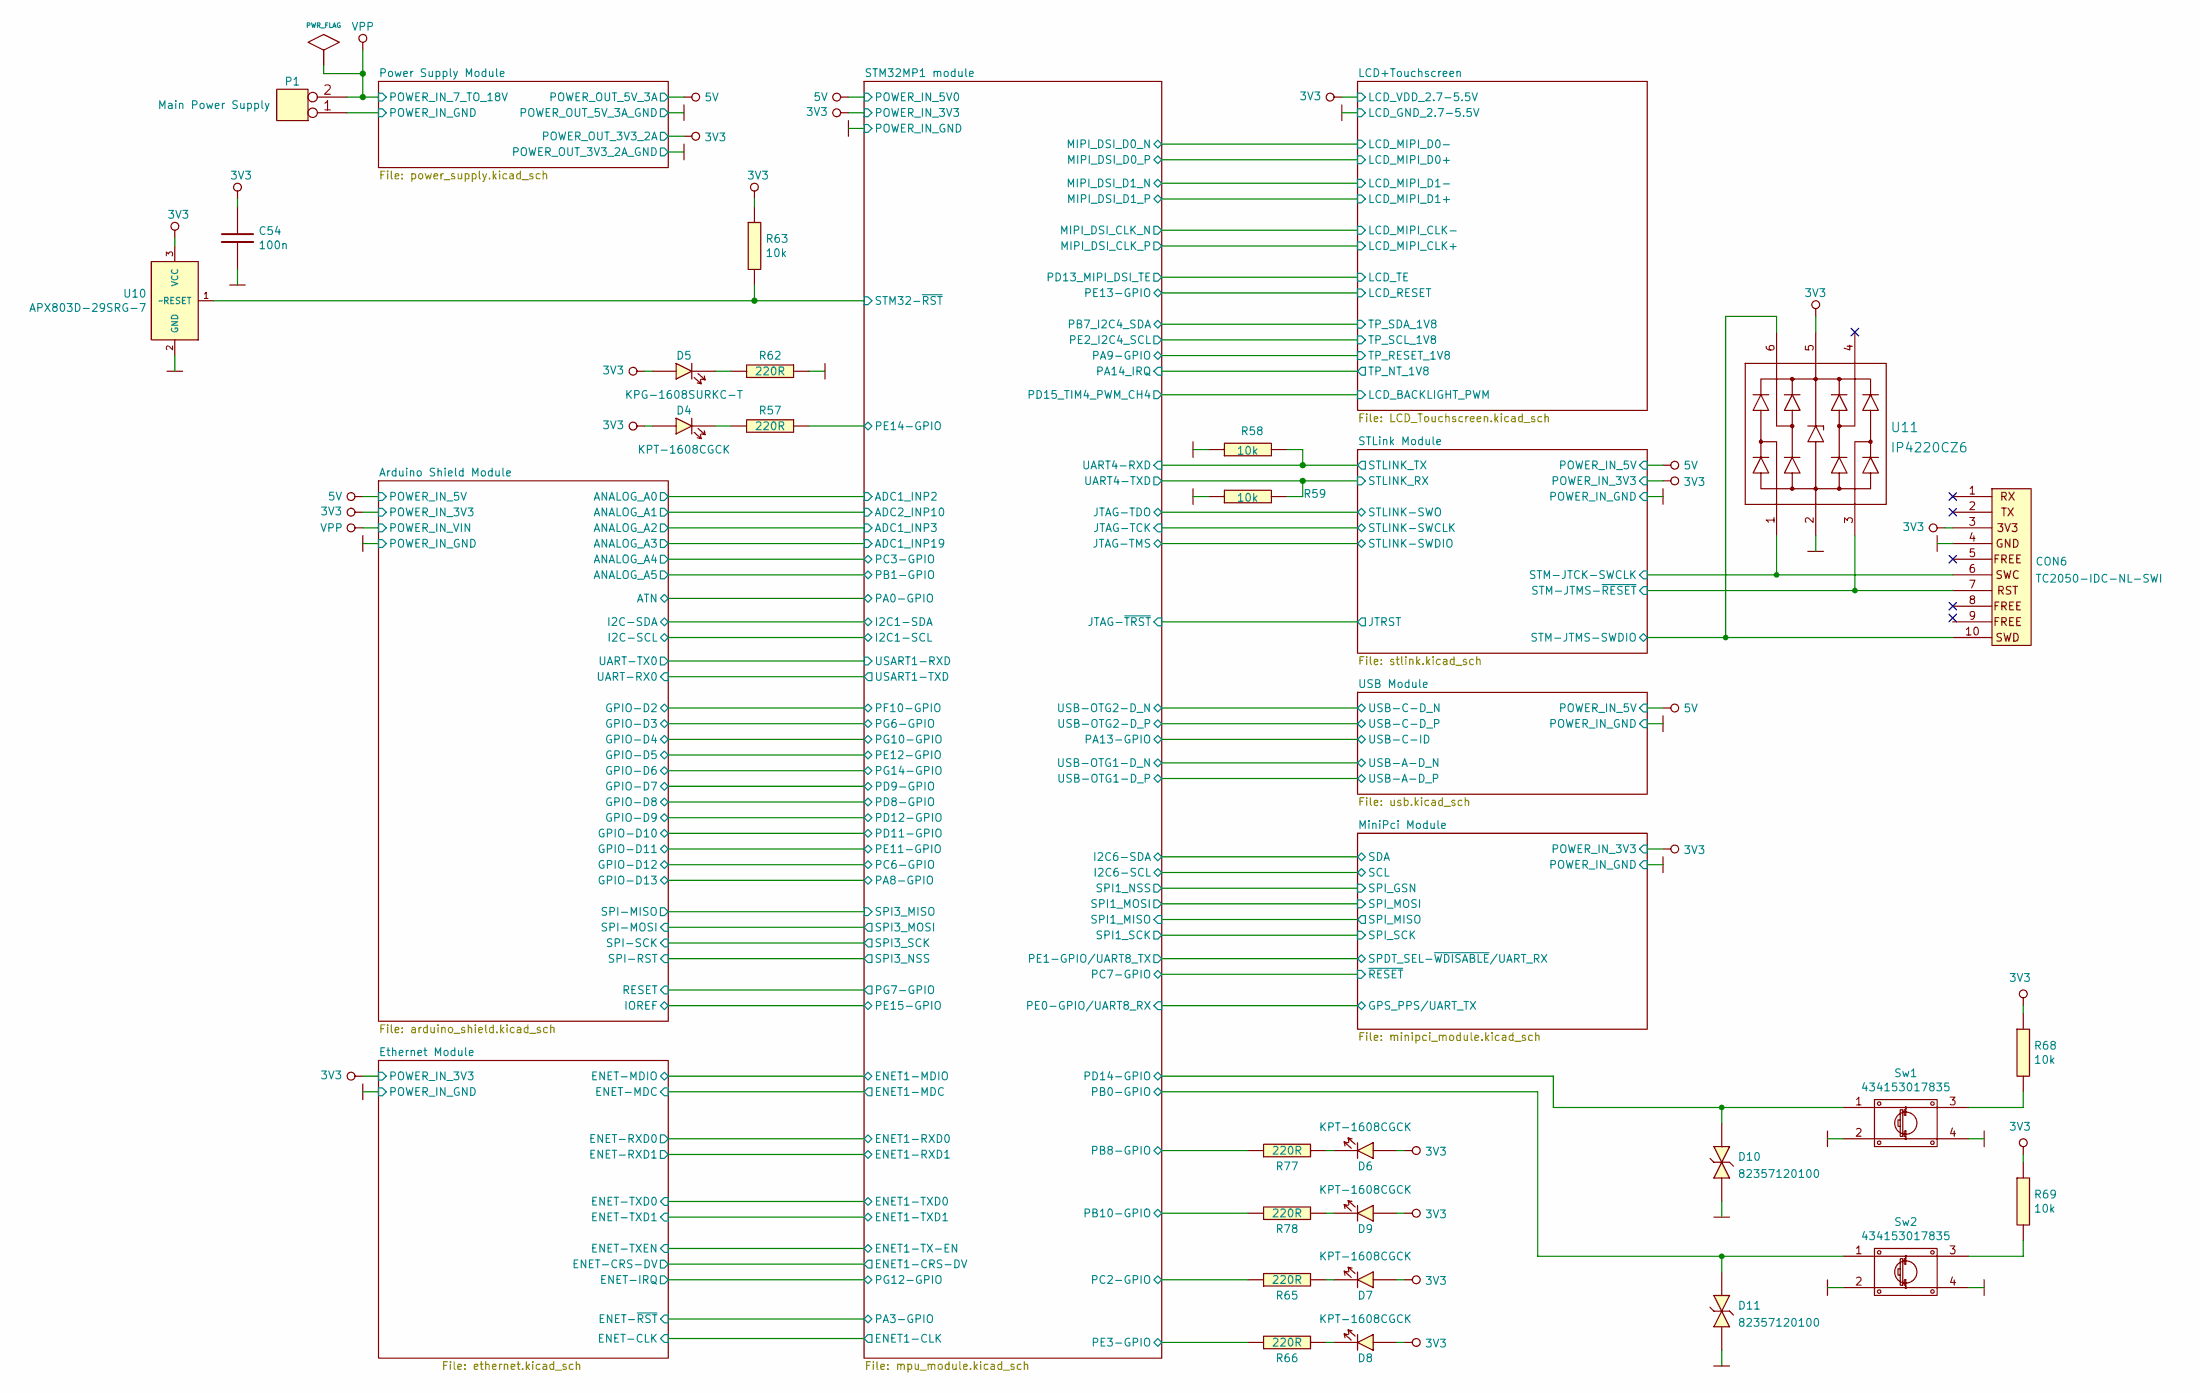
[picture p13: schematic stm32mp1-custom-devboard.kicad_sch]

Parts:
C54: 100n; 100nF_0603; Manufacturer Part Number CL10B104JB8NNNC
CON6: TC2050-IDC-NL-SWI; TC2050-IDC-NL
D4, D6, D7, D8, D9: KPT-1608CGCK; LED_KPT-1608CGCK; Manufacturer Part Number KP-1608CGCK; LCSC Part # (optional) C192316
D5: KPG-1608SURKC-T; LED_KPG-1608SURKC-T; Manufacturer Part Number KPG-1608SURKC-T; LCSC Part # (optional) C192315
D10, D11: 82357120100; Manufacturer Part Number 82357120100; LCSC Part #(optional) C39109
P1: Main Power Supply; 2060-452_998-404; Manufacturer Part Number 2060-452/998-404
R57, R62, R65, R66, R77, R78: 220R; 220R_0603; Manufacturer Part Number CQ03SAF2203T5E; LCSC Part #(optional) C103414
R58, R59, R63, R68, R69: 10k; 10k_0603; Manufacturer Part Number 0603SAJ0103T5E
Sw1, Sw2: 434153017835; Manufacturer Part Number 434153017835
U10: APX803D-29SRG-7; Manufacturer Part Number APX803D-29SRG-7; LCSC Part #(optional) C460556
U11: IP4220CZ6; IP4220CZ6_SOT457; Manufacturer Part Number IP4220CZ6.125; LCSC Part #(optional) C2687127

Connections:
3V3: C54.1, CON6.3, D4.1 (A), D5.1 (A), D6.1 (A), D7.1 (A), D8.1 (A), D9.1 (A), R63.1, R68.1, R69.1, U10.3 (VCC), U11.5 (Vp); also elsewhere on the board
/STLink Module/STLINK_RX: R59.2; also elsewhere on the board
/STLink Module/STLINK_TX: R58.2; also elsewhere on the board
/STLink Module/STM-JTCK-SWCLK: CON6.6, U11.1 (I/O1); also elsewhere on the board
/STLink Module/STM-JTMS-SWDIO: CON6.10, U11.6 (I/O4); also elsewhere on the board
/STLink Module/STM-JTMS-~RESET: CON6.7, U11.3 (I/O2); also elsewhere on the board
/STM32MP1 module/PB0-GPIO: D11.2 (K), Sw2.1; also elsewhere on the board
/STM32MP1 module/PB8-GPIO: R77.1; also elsewhere on the board
/STM32MP1 module/PB10-GPIO: R78.1; also elsewhere on the board
/STM32MP1 module/PC2-GPIO: R65.1; also elsewhere on the board
/STM32MP1 module/PD14-GPIO: D10.2 (K), Sw1.1; also elsewhere on the board
/STM32MP1 module/PE3-GPIO: R66.1; also elsewhere on the board
/STM32MP1 module/PE14-GPIO: R57.1; also elsewhere on the board
/STM32MP1 module/STM32-~RST: R63.2, U10.1 (~RESET); also elsewhere on the board
GND: C54.2, CON6.4, D10.1 (A), D11.1 (A), P1.1, R58.1, R59.1, R62.1, Sw1.2, Sw1.4, Sw2.2, Sw2.4, U10.2 (GND), U11.2 (GND); also elsewhere on the board
unnamed: D4.2 (K), R57.2
unnamed: D5.2 (K), R62.2
unnamed: D6.2 (K), R77.2
unnamed: D7.2 (K), R65.2
unnamed: D8.2 (K), R66.2
unnamed: D9.2 (K), R78.2
unnamed: R68.2, Sw1.3
unnamed: R69.2, Sw2.3
VPP: P1.2; also elsewhere on the board

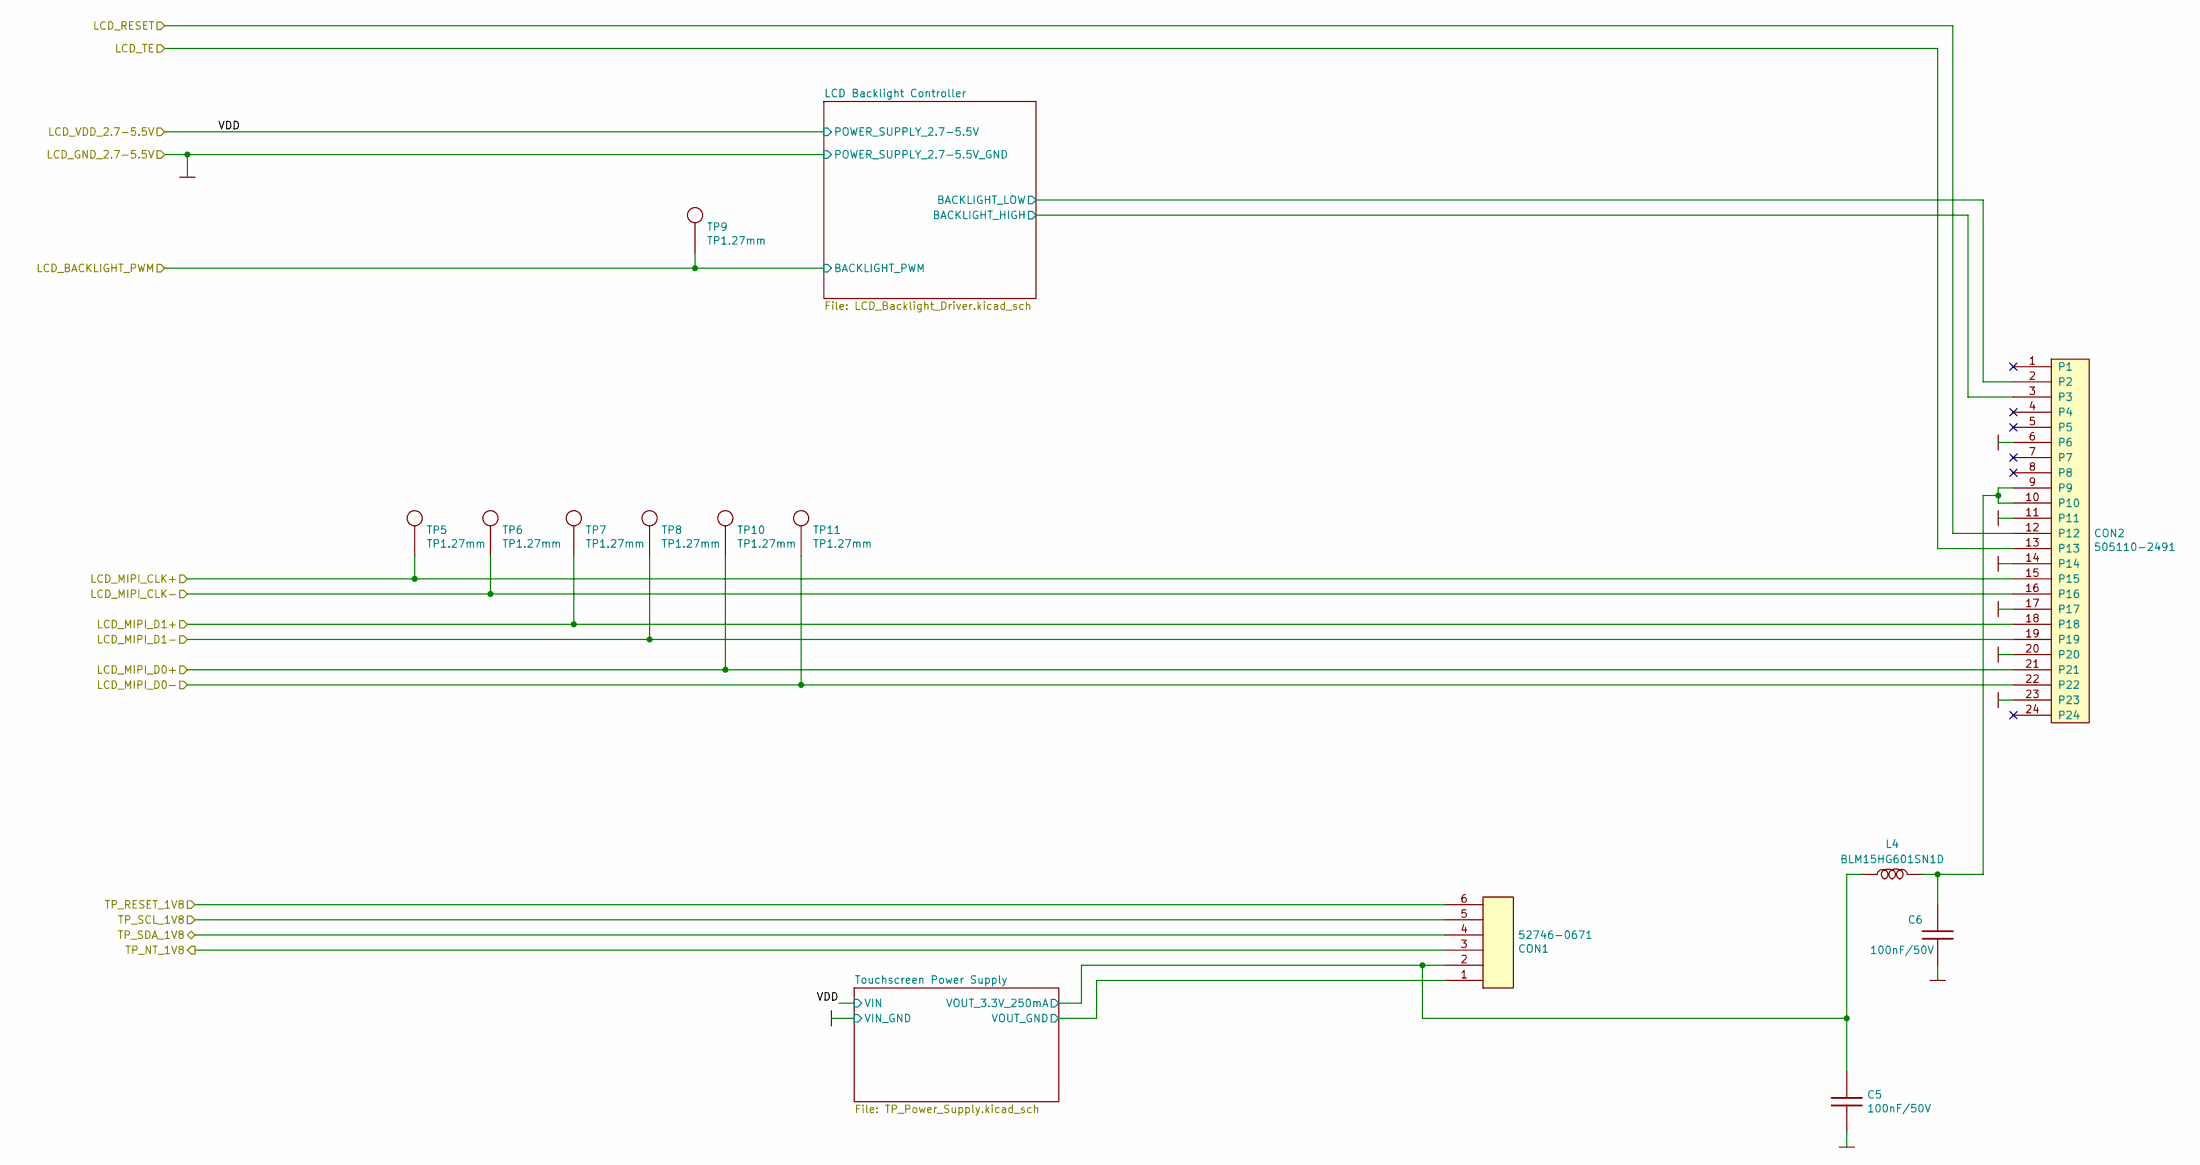
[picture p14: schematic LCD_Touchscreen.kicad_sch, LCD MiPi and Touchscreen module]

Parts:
C5, C6: 100nF/50V; 100nF_0603; Manufacturer Part Number CL10B104JB8NNNC
CON1: 52746-0671; Manufacturer Part Number 52746-0671
CON2: 505110-2491; Manufacturer Part Number 505110-2491
L4: BLM15HG601SN1D; BLM15HG601SN1D_0402
TP5, TP6, TP7, TP8, TP9, TP10, TP11: TP1.27mm; Test_Point_1.27mm

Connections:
/LCD+Touchscreen/LCD Backlight Controller/BACKLIGHT_HIGH: CON2.3; also elsewhere on the board
/LCD+Touchscreen/LCD Backlight Controller/BACKLIGHT_LOW: CON2.2; also elsewhere on the board
/LCD+Touchscreen/LCD_BACKLIGHT_PWM: TP9.1 (TP); also elsewhere on the board
/LCD+Touchscreen/LCD_MIPI_CLK+: CON2.15, TP5.1 (TP); also elsewhere on the board
/LCD+Touchscreen/LCD_MIPI_CLK-: CON2.16, TP6.1 (TP); also elsewhere on the board
/LCD+Touchscreen/LCD_MIPI_D0+: CON2.21, TP10.1 (TP); also elsewhere on the board
/LCD+Touchscreen/LCD_MIPI_D0-: CON2.22, TP11.1 (TP); also elsewhere on the board
/LCD+Touchscreen/LCD_MIPI_D1+: CON2.18, TP7.1 (TP); also elsewhere on the board
/LCD+Touchscreen/LCD_MIPI_D1-: CON2.19, TP8.1 (TP); also elsewhere on the board
/LCD+Touchscreen/LCD_RESET: CON2.12; also elsewhere on the board
/LCD+Touchscreen/LCD_TE: CON2.13; also elsewhere on the board
/LCD+Touchscreen/TP_NT_1V8: CON1.3; also elsewhere on the board
/LCD+Touchscreen/TP_RESET_1V8: CON1.6; also elsewhere on the board
/LCD+Touchscreen/TP_SCL_1V8: CON1.5; also elsewhere on the board
/LCD+Touchscreen/TP_SDA_1V8: CON1.4; also elsewhere on the board
/LCD+Touchscreen/Touchscreen Power Supply/VOUT_3.3V_250mA: C5.1, CON1.2, L4.2; also elsewhere on the board
GND: C5.2, C6.2, CON1.1, CON2.6, CON2.11, CON2.14, CON2.17, CON2.20, CON2.23; also elsewhere on the board
unnamed: C6.1, CON2.9, CON2.10, L4.1

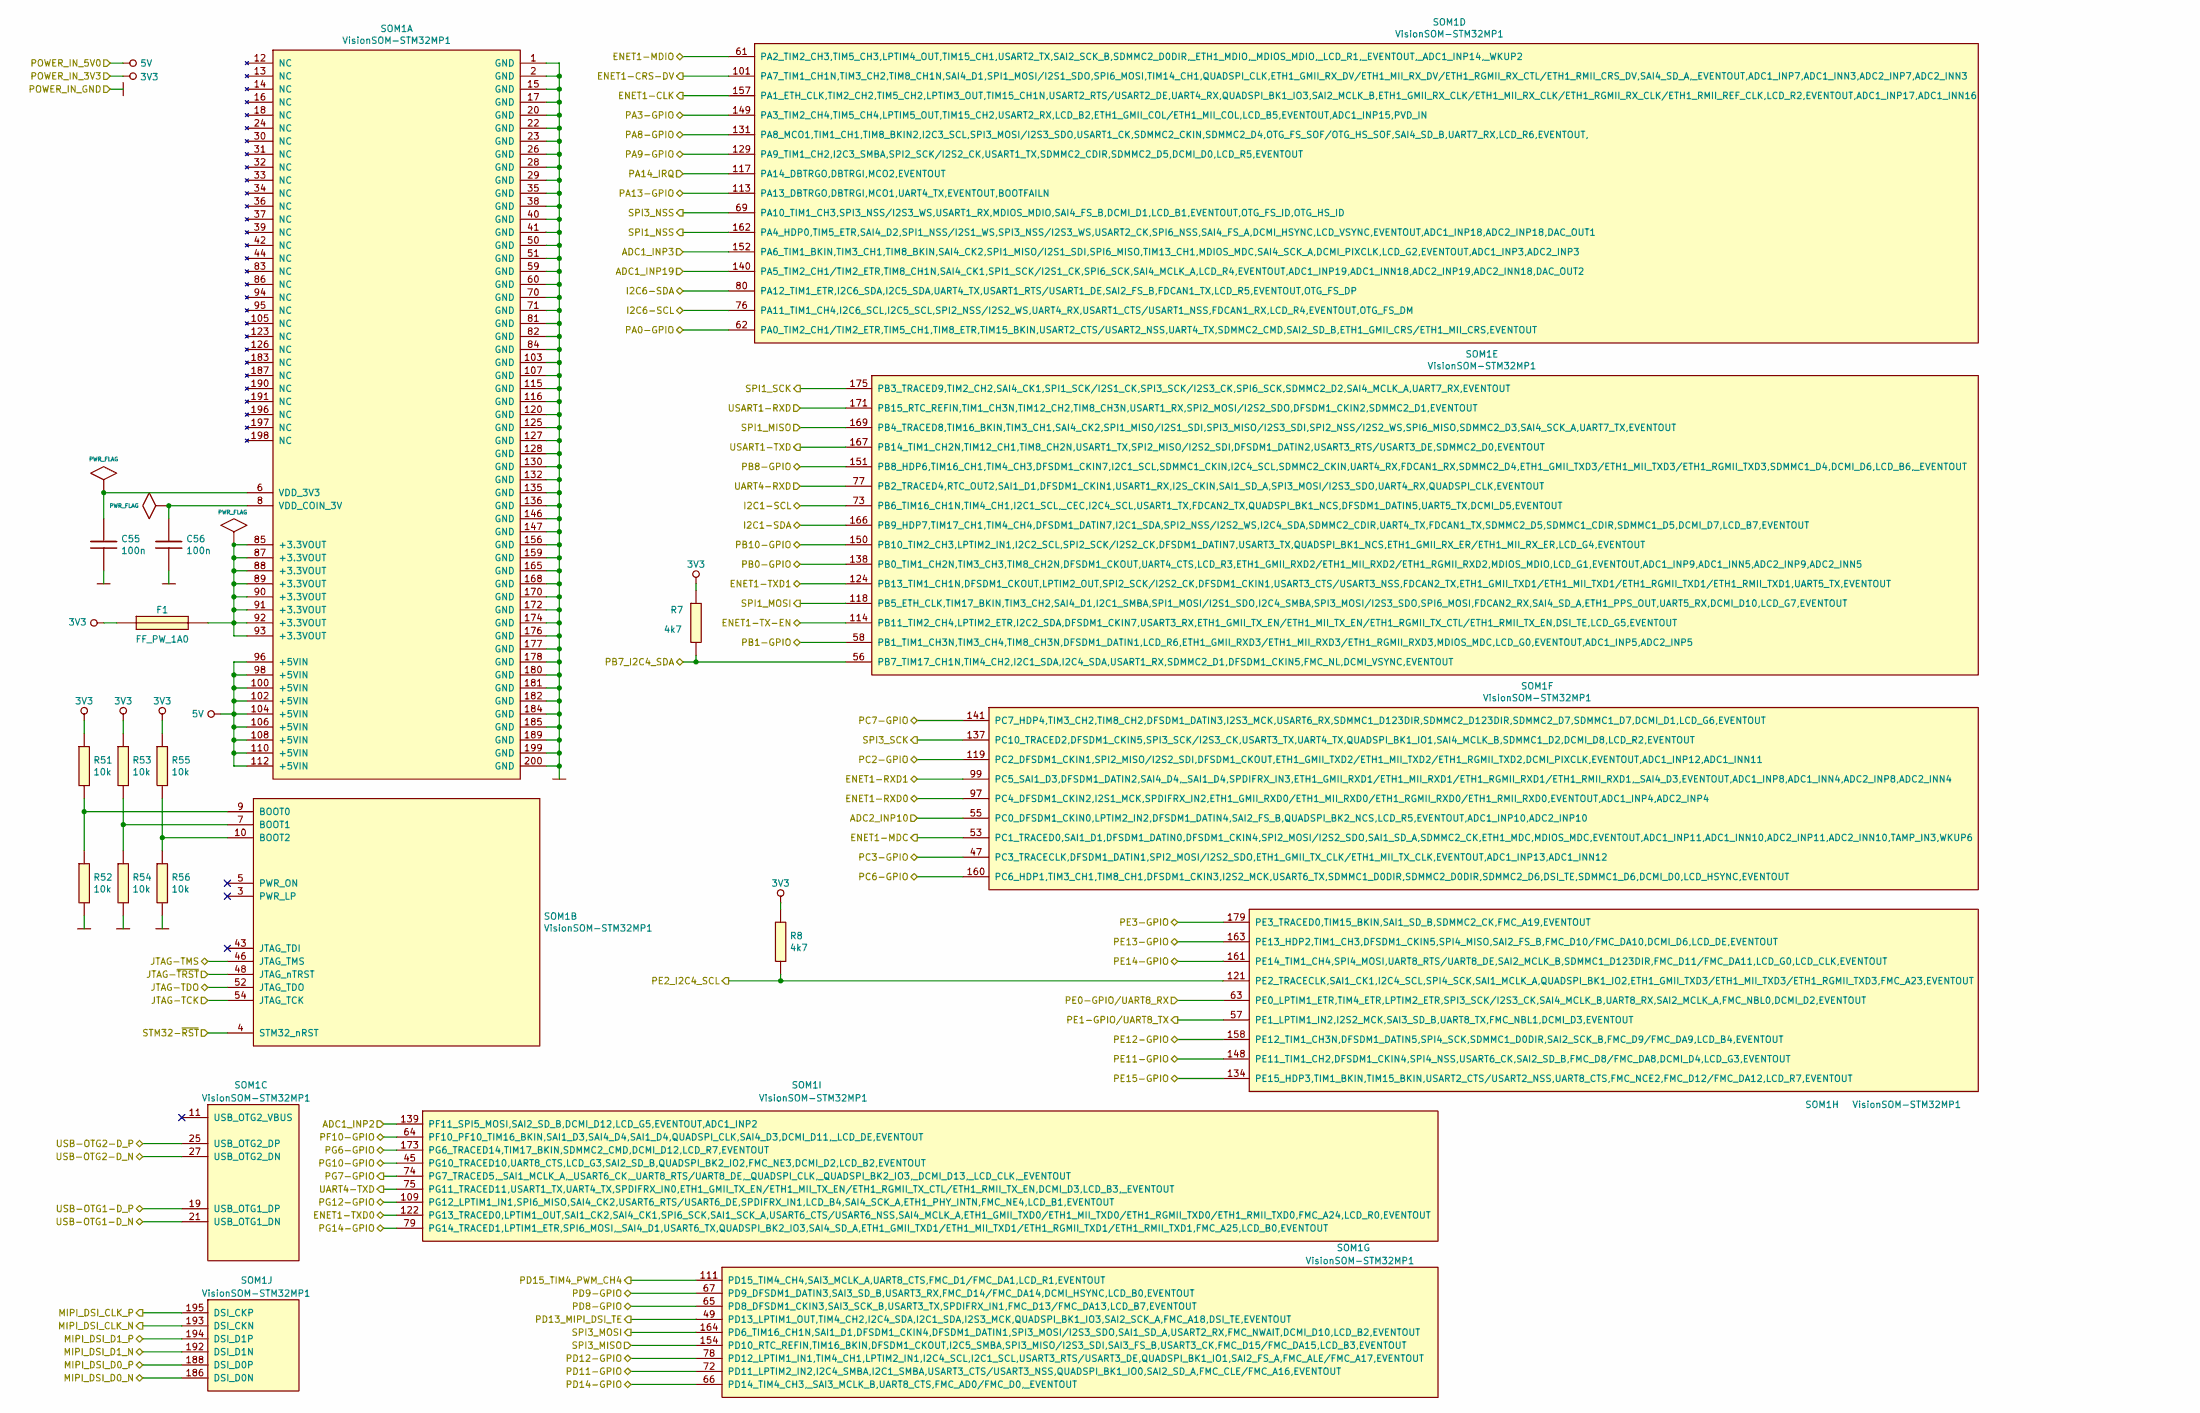
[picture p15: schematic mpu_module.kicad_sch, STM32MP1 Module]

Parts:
C55, C56: 100n; 100nF_0603; Manufacturer Part Number CL10B104JB8NNNC
F1: FF_PW_1A0; Fuse_0603-FF_PW_1A0; Manufacturer Part Number FUSE 0603-FF PW 1A
R7, R8: 4k7; 4k7_0603; Manufacturer Part Number 0603SAF4701T5E
R51, R52, R53, R54, R55, R56: 10k; 10k_0603; Manufacturer Part Number 0603SAJ0103T5E
SOM1: VisionSOM-STM32MP1; Manufacturer Part Number VisionSOM-STM32MP1

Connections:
3V3: F1.1, R7.1, R8.1, R51.1, R53.1, R55.1; also elsewhere on the board
5V: SOM1.96 (+5VIN), SOM1.98 (+5VIN), SOM1.100 (+5VIN), SOM1.102 (+5VIN), SOM1.104 (+5VIN), SOM1.106 (+5VIN), SOM1.108 (+5VIN), SOM1.110 (+5VIN), SOM1.112 (+5VIN); also elsewhere on the board
/Arduino Shield Module/ANALOG_A0: SOM1.139 (PF11_SPI5_MOSI,SAI2_SD_B,DCMI_D12,LCD_G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); also elsewhere on the board
/Arduino Shield Module/ANALOG_A1: SOM1.55 (PC0_DFSDM1_CKIN0,LPTIM2_IN2,DFSDM1_DATI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); also elsewhere on the board
/Arduino Shield Module/ANALOG_A2: SOM1.152 (PA6_TIM1_BKIN,TIM3_CH1,TIM8_BKIN,SAI4_C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); also elsewhere on the board
/Arduino Shield Module/ANALOG_A3: SOM1.140 (PA5_TIM2_CH1/TIM2_ETR,TIM8_CH1N,SAI4_CK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); also elsewhere on the board
/Arduino Shield Module/ANALOG_A4: SOM1.47 (PC3_TRACECLK,DFSDM1_DATIN1,SPI2_MOSI/I2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); also elsewhere on the board
/Arduino Shield Module/ANALOG_A5: SOM1.58 (PB1_TIM1_CH3N,TIM3_CH4,TIM8_CH3N,DFSDM1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); also elsewhere on the board
/Arduino Shield Module/ATN: SOM1.62 (PA0_TIM2_CH1/TIM2_ETR,TIM5_CH1,TIM8_ETR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); also elsewhere on the board
/Arduino Shield Module/GPIO-D2: SOM1.64 (PF10_PF10_TIM16_BKIN,SAI1_D3,SAI4_D4,SA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); also elsewhere on the board
/Arduino Shield Module/GPIO-D3: SOM1.173 (PG6_TRACED14,TIM17_BKIN,SDMMC2_CMD,DCMI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); also elsewhere on the board
/Arduino Shield Module/GPIO-D4: SOM1.45 (PG10_TRACED10,UART8_CTS,LCD_G3,SAI2_SD_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); also elsewhere on the board
/Arduino Shield Module/GPIO-D5: SOM1.158 (PE12_TIM1_CH3N,DFSDM1_DATIN5,SPI4_SCK,S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); also elsewhere on the board
/Arduino Shield Module/GPIO-D6: SOM1.79 (PG14_TRACED1,LPTIM1_ETR,SPI6_MOSI,_SAI4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); also elsewhere on the board
/Arduino Shield Module/GPIO-D7: SOM1.67 (PD9_DFSDM1_DATIN3,SAI3_SD_B,USART3_RX,F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); also elsewhere on the board
/Arduino Shield Module/GPIO-D8: SOM1.65 (PD8_DFSDM1_CKIN3,SAI3_SCK_B,USART3_TX,S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); also elsewhere on the board
/Arduino Shield Module/GPIO-D9: SOM1.78 (PD12_LPTIM1_IN1,TIM4_CH1,LPTIM2_IN1,I2C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); also elsewhere on the board
/Arduino Shield Module/GPIO-D10: SOM1.72 (PD11_LPTIM2_IN2,I2C4_SMBA,I2C1_SMBA,USA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); also elsewhere on the board
/Arduino Shield Module/GPIO-D11: SOM1.148 (PE11_TIM1_CH2,DFSDM1_CKIN4,SPI4_NSS,USA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); also elsewhere on the board
/Arduino Shield Module/GPIO-D12: SOM1.160 (PC6_HDP1,TIM3_CH1,TIM8_CH1,DFSDM1_CKIN3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); also elsewhere on the board
/Arduino Shield Module/GPIO-D13: SOM1.131 (PA8_MCO1,TIM1_CH1,TIM8_BKIN2,I2C3_SCL,S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); also elsewhere on the board
/Arduino Shield Module/I2C-SCL: SOM1.73 (PB6_TIM16_CH1N,TIM4_CH1,I2C1_SCL,_CEC,I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); also elsewhere on the board
/Arduino Shield Module/I2C-SDA: SOM1.166 (PB9_HDP7,TIM17_CH1,TIM4_CH4,DFSDM1_DATI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); also elsewhere on the board
/Arduino Shield Module/IOREF: SOM1.134 (PE15_HDP3,TIM1_BKIN,TIM15_BKIN,USART2_C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); also elsewhere on the board
/Arduino Shield Module/RESET: SOM1.74 (PG7_TRACED5,_SAI1_MCLK_A,_USART6_CK,_UA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); also elsewhere on the board
/Arduino Shield Module/SPI-MISO: SOM1.154 (PD10_RTC_REFIN,TIM16_BKIN,DFSDM1_CKOUT,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); also elsewhere on the board
/Arduino Shield Module/SPI-MOSI: SOM1.164 (PD6_TIM16_CH1N,SAI1_D1,DFSDM1_CKIN4,DFS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); also elsewhere on the board
/Arduino Shield Module/SPI-RST: SOM1.69 (PA10_TIM1_CH3,SPI3_NSS/I2S3_WS,USART1_R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); also elsewhere on the board
/Arduino Shield Module/SPI-SCK: SOM1.137 (PC10_TRACED2,DFSDM1_CKIN5,SPI3_SCK/I2S3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); also elsewhere on the board
/Arduino Shield Module/UART-RX0: SOM1.167 (PB14_TIM1_CH2N,TIM12_CH1,TIM8_CH2N,USAR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); also elsewhere on the board
/Arduino Shield Module/UART-TX0: SOM1.171 (PB15_RTC_REFIN,TIM1_CH3N,TIM12_CH2,TIM8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); also elsewhere on the board
/Ethernet Module/ENET-CLK: SOM1.157 (PA1_ETH_CLK,TIM2_CH2,TIM5_CH2,LPTIM3_OU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); also elsewhere on the board
/Ethernet Module/ENET-CRS-DV: SOM1.101 (PA7_TIM1_CH1N,TIM3_CH2,TIM8_CH1N,SAI4_D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); also elsewhere on the board
/Ethernet Module/ENET-IRQ: SOM1.109 (PG12_LPTIM1_IN1,SPI6_MISO,SAI4_CK2,USAR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); also elsewhere on the board
/Ethernet Module/ENET-MDC: SOM1.53 (PC1_TRACED0,SAI1_D1,DFSDM1_DATIN0,DFSDM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); also elsewhere on the board
/Ethernet Module/ENET-MDIO: SOM1.61 (PA2_TIM2_CH3,TIM5_CH3,LPTIM4_OUT,TIM15_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); also elsewhere on the board
/Ethernet Module/ENET-RXD0: SOM1.97 (PC4_DFSDM1_CKIN2,I2S1_MCK,SPDIFRX_IN2,E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); also elsewhere on the board
/Ethernet Module/ENET-RXD1: SOM1.99 (PC5_SAI1_D3,DFSDM1_DATIN2,SAI4_D4,_SAI1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); also elsewhere on the board
/Ethernet Module/ENET-TXD0: SOM1.122 (PG13_TRACED0,LPTIM1_OUT,SAI1_CK2,SAI4_C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); also elsewhere on the board
/Ethernet Module/ENET-TXD1: SOM1.124 (PB13_TIM1_CH1N,DFSDM1_CKOUT,LPTIM2_OUT,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); also elsewhere on the board
/Ethernet Module/ENET-TXEN: SOM1.114 (PB11_TIM2_CH4,LPTIM2_ETR,I2C2_SDA,DFSDM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); also elsewhere on the board
/Ethernet Module/ENET-~RST: SOM1.149 (PA3_TIM2_CH4,TIM5_CH4,LPTIM5_OUT,TIM15_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); also elsewhere on the board
/LCD+Touchscreen/LCD_BACKLIGHT_PWM: SOM1.111 (PD15_TIM4_CH4,SAI3_MCLK_A,UART8_CTS,FMC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); also elsewhere on the board
/LCD+Touchscreen/LCD_MIPI_CLK+: SOM1.195 (DSI_CKP); also elsewhere on the board
/LCD+Touchscreen/LCD_MIPI_CLK-: SOM1.193 (DSI_CKN); also elsewhere on the board
/LCD+Touchscreen/LCD_MIPI_D0+: SOM1.188 (DSI_D0P); also elsewhere on the board
/LCD+Touchscreen/LCD_MIPI_D0-: SOM1.186 (DSI_D0N); also elsewhere on the board
/LCD+Touchscreen/LCD_MIPI_D1+: SOM1.194 (DSI_D1P); also elsewhere on the board
/LCD+Touchscreen/LCD_MIPI_D1-: SOM1.192 (DSI_D1N); also elsewhere on the board
/LCD+Touchscreen/LCD_RESET: SOM1.163 (PE13_HDP2,TIM1_CH3,DFSDM1_CKIN5,SPI4_MI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); also elsewhere on the board
/LCD+Touchscreen/LCD_TE: SOM1.49 (PD13_LPTIM1_OUT,TIM4_CH2,I2C4_SDA,I2C1_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); also elsewhere on the board
/LCD+Touchscreen/TP_NT_1V8: SOM1.117 (PA14_DBTRGO,DBTRGI,MCO2,EVENTOUT); also elsewhere on the board
/LCD+Touchscreen/TP_RESET_1V8: SOM1.129 (PA9_TIM1_CH2,I2C3_SMBA,SPI2_SCK/I2S2_CK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); also elsewhere on the board
/LCD+Touchscreen/TP_SCL_1V8: R8.2, SOM1.121 (PE2_TRACECLK,SAI1_CK1,I2C4_SCL,SPI4_SCK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); also elsewhere on the board
/LCD+Touchscreen/TP_SDA_1V8: R7.2, SOM1.56 (PB7_TIM17_CH1N,TIM4_CH2,I2C1_SDA,I2C4_S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); also elsewhere on the board
/MiniPci Module/GPS_PPS/UART_TX: SOM1.63 (PE0_LPTIM1_ETR,TIM4_ETR,LPTIM2_ETR,SPI3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); also elsewhere on the board
/MiniPci Module/SCL: SOM1.76 (PA11_TIM1_CH4,I2C6_SCL,I2C5_SCL,SPI2_NS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); also elsewhere on the board
/MiniPci Module/SDA: SOM1.80 (PA12_TIM1_ETR,I2C6_SDA,I2C5_SDA,UART4_T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); also elsewhere on the board
/MiniPci Module/SPDT_SEL-~WDISABLE/UART_RX: SOM1.57 (PE1_LPTIM1_IN2,I2S2_MCK,SAI3_SD_B,UART8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); also elsewhere on the board
/MiniPci Module/SPI_GSN: SOM1.162 (PA4_HDP0,TIM5_ETR,SAI4_D2,SPI1_NSS/I2S1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); also elsewhere on the board
/MiniPci Module/SPI_MISO: SOM1.169 (PB4_TRACED8,TIM16_BKIN,TIM3_CH1,SAI4_CK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); also elsewhere on the board
/MiniPci Module/SPI_MOSI: SOM1.118 (PB5_ETH_CLK,TIM17_BKIN,TIM3_CH2,SAI4_D1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); also elsewhere on the board
/MiniPci Module/SPI_SCK: SOM1.175 (PB3_TRACED9,TIM2_CH2,SAI4_CK1,SPI1_SCK/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); also elsewhere on the board
/MiniPci Module/~RESET: SOM1.141 (PC7_HDP4,TIM3_CH2,TIM8_CH2,DFSDM1_DATIN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); also elsewhere on the board
/STLink Module/JTRST: SOM1.48 (JTAG_nTRST); also elsewhere on the board
/STLink Module/STLINK-SWCLK: SOM1.54 (JTAG_TCK); also elsewhere on the board
/STLink Module/STLINK-SWDIO: SOM1.46 (JTAG_TMS); also elsewhere on the board
/STLink Module/STLINK-SWO: SOM1.52 (JTAG_TDO); also elsewhere on the board
/STLink Module/STLINK_RX: SOM1.75 (PG11_TRACED11,USART1_TX,UART4_TX,SPDIFR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); also elsewhere on the board
/STLink Module/STLINK_TX: SOM1.77 (PB2_TRACED4,RTC_OUT2,SAI1_D1,DFSDM1_CKI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); also elsewhere on the board
/STM32MP1 module/PA13-GPIO: SOM1.113 (PA13_DBTRGO,DBTRGI,MCO1,UART4_TX,EVENTO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); also elsewhere on the board
/STM32MP1 module/PB0-GPIO: SOM1.138 (PB0_TIM1_CH2N,TIM3_CH3,TIM8_CH2N,DFSDM1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); also elsewhere on the board
/STM32MP1 module/PB8-GPIO: SOM1.151 (PB8_HDP6,TIM16_CH1,TIM4_CH3,DFSDM1_CKIN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); also elsewhere on the board
/STM32MP1 module/PB10-GPIO: SOM1.150 (PB10_TIM2_CH3,LPTIM2_IN1,I2C2_SCL,SPI2_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); also elsewhere on the board
/STM32MP1 module/PC2-GPIO: SOM1.119 (PC2_DFSDM1_CKIN1,SPI2_MISO/I2S2_SDI,DFS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); also elsewhere on the board
/STM32MP1 module/PD14-GPIO: SOM1.66 (PD14_TIM4_CH3,_SAI3_MCLK_B,UART8_CTS,FM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); also elsewhere on the board
/STM32MP1 module/PE3-GPIO: SOM1.179 (PE3_TRACED0,TIM15_BKIN,SAI1_SD_B,SDMMC2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); also elsewhere on the board
/STM32MP1 module/PE14-GPIO: SOM1.161 (PE14_TIM1_CH4,SPI4_MOSI,UART8_RTS/UART8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); also elsewhere on the board
/STM32MP1 module/STM32-~RST: SOM1.4 (STM32_nRST); also elsewhere on the board
/STM32MP1 module/USB-OTG1-D_N: SOM1.21 (USB_OTG1_DN); also elsewhere on the board
/STM32MP1 module/USB-OTG1-D_P: SOM1.19 (USB_OTG1_DP); also elsewhere on the board
/STM32MP1 module/USB-OTG2-D_N: SOM1.27 (USB_OTG2_DN); also elsewhere on the board
/STM32MP1 module/USB-OTG2-D_P: SOM1.25 (USB_OTG2_DP); also elsewhere on the board
GND: C55.2, C56.2, R52.2, R54.2, R56.2, SOM1.1 (GND), SOM1.2 (GND), SOM1.15 (GND), SOM1.17 (GND), SOM1.20 (GND), SOM1.22 (GND), SOM1.23 (GND), SOM1.26 (GND), SOM1.28 (GND), SOM1.29 (GND), SOM1.35 (GND), SOM1.38 (GND), SOM1.40 (GND), SOM1.41 (GND), SOM1.50 (GND), SOM1.51 (GND), SOM1.59 (GND), SOM1.60 (GND), SOM1.70 (GND), SOM1.71 (GND), SOM1.81 (GND), SOM1.82 (GND), SOM1.84 (GND), SOM1.103 (GND), SOM1.107 (GND), SOM1.115 (GND), SOM1.116 (GND), SOM1.120 (GND), SOM1.125 (GND), SOM1.127 (GND), SOM1.128 (GND), SOM1.130 (GND), SOM1.132 (GND), SOM1.135 (GND), SOM1.136 (GND), SOM1.146 (GND), SOM1.147 (GND), SOM1.156 (GND), SOM1.159 (GND), SOM1.165 (GND), SOM1.168 (GND), SOM1.170 (GND), SOM1.172 (GND), SOM1.174 (GND), SOM1.176 (GND), SOM1.177 (GND), SOM1.178 (GND), SOM1.180 (GND), SOM1.181 (GND), SOM1.182 (GND), SOM1.184 (GND), SOM1.185 (GND), SOM1.189 (GND), SOM1.199 (GND), SOM1.200 (GND); also elsewhere on the board
unnamed: C55.1, SOM1.6 (VDD_3V3)
unnamed: C56.1, SOM1.8 (VDD_COIN_3V)
unnamed: F1.2, SOM1.85 (+3.3VOUT), SOM1.87 (+3.3VOUT), SOM1.88 (+3.3VOUT), SOM1.89 (+3.3VOUT), SOM1.90 (+3.3VOUT), SOM1.91 (+3.3VOUT), SOM1.92 (+3.3VOUT), SOM1.93 (+3.3VOUT)
unnamed: R51.2, R52.1, SOM1.9 (BOOT0)
unnamed: R53.2, R54.1, SOM1.7 (BOOT1)
unnamed: R55.2, R56.1, SOM1.10 (BOOT2)

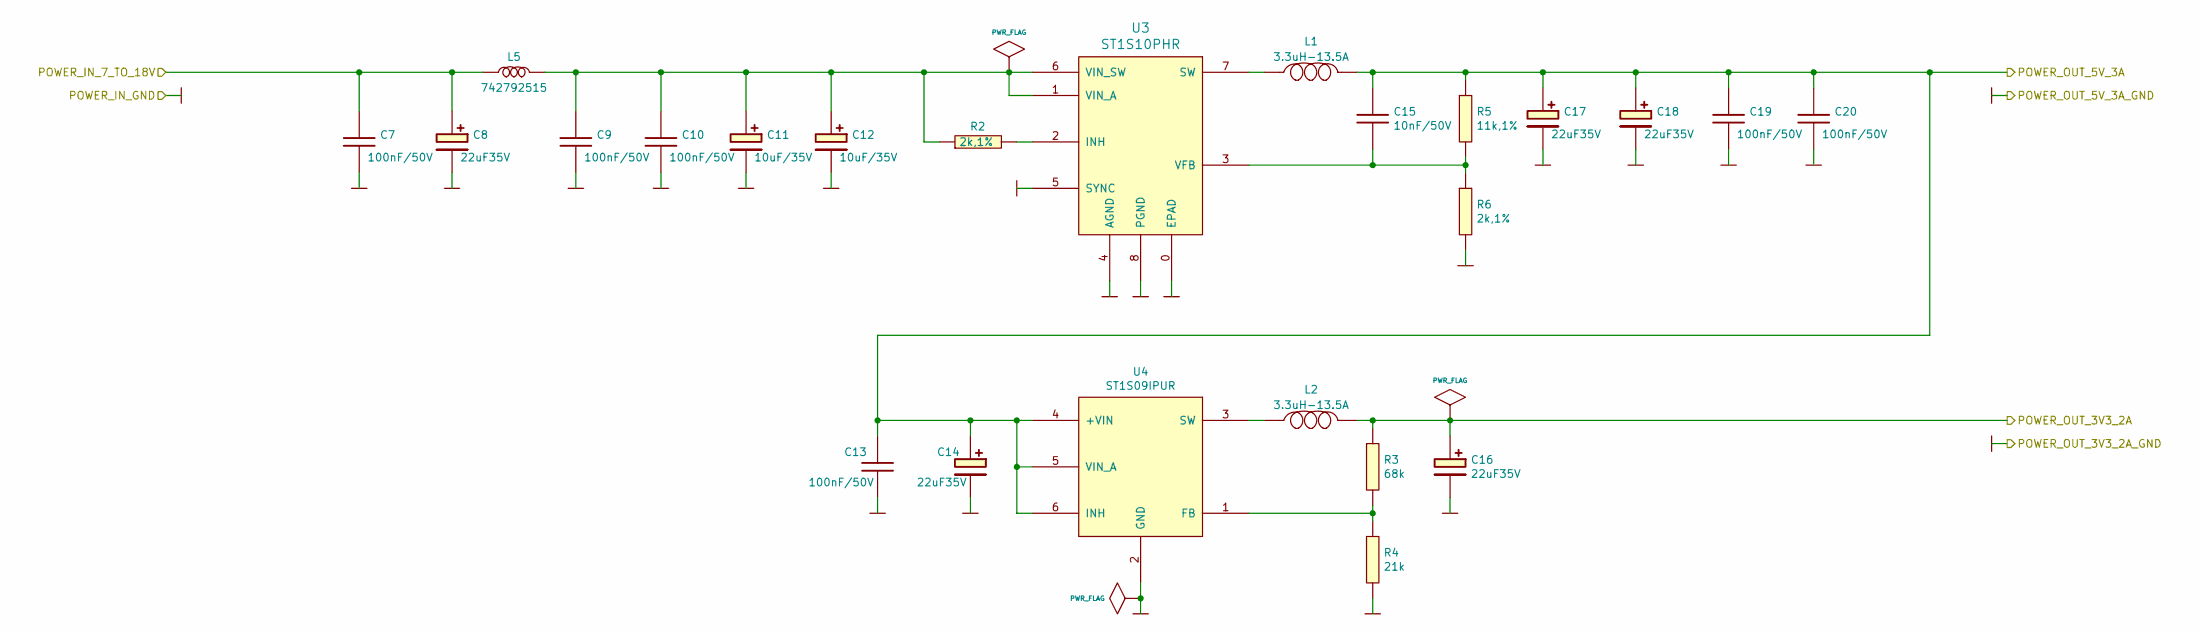
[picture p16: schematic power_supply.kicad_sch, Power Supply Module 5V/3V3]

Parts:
C7, C9, C10, C13, C19, C20: 100nF/50V; 100nF_0603; Manufacturer Part Number CL10B104JB8NNNC
C8, C14, C16, C17, C18: 22uF35V; 22uF_35V_Size_D; Manufacturer Part Number 293D226X9035D2TE3; LCSC Part # (optional) C126947
C11, C12: 10uF/35V; 10uF_35V_C; Manufacturer Part Number 293D106X9035C2TE3; LCSC Part # (optional) C169217
C15: 10nF/50V; 10nF_0603; Manufacturer Part Number VJ0603Y103KXAPW1BC; LCSC Part # (optional) C342901
L1, L2: 3.3uH-13.5A; ASPI-0630HI-3R3M-T15; Manufacturer Part Number ASPI-0630HI-3R3M-T15
L5: 742792515; Manufacturer Part Number 742792515; LCSC Part #(optional) C350947
R2, R6: 2k,1%; 2k_0603; Manufacturer Part Number CQ03SAF2001T5E; LCSC Part #(optional) C234435
R3: 68k; 68k_0603; Manufacturer Part Number 0603SAF6802T5E; LCSC Part #(optional) C160055
R4: 21k; 21k_0603; Manufacturer Part Number 0603SAF2102T5E; LCSC Part #(optional) C177529
R5: 11k,1%; 11k_0603; Manufacturer Part Number 0603SAF1102T5E
U3: ST1S10PHR; ST1S10PHR_SOIC8; Manufacturer Part Number ST1S10PHR; LCSC Part #(optional) C11175
U4: ST1S09IPUR; Manufacturer Part Number ST1S09IPUR; LCSC Part #(optional) C361028

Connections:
3V3: C16.1, L2.2, R3.1; also elsewhere on the board
5V: C13.1, C14.1, C15.1, C17.1, C18.1, C19.1, C20.1, L1.2, R5.1, U4.4 (+VIN), U4.5 (VIN_A), U4.6 (INH); also elsewhere on the board
GND: C7.2, C8.2, C9.2, C10.2, C11.2, C12.2, C13.2, C14.2, C16.2, C17.2, C18.2, C19.2, C20.2, R4.2, R6.2, U3.0 (EPAD), U3.4 (AGND), U3.5 (SYNC), U3.8 (PGND), U4.2 (GND); also elsewhere on the board
unnamed: C9.1, C10.1, C11.1, C12.1, L5.2, R2.1, U3.1 (VIN_A), U3.6 (VIN_SW)
unnamed: C15.2, R5.2, R6.1, U3.3 (VFB)
unnamed: L1.1, U3.7 (SW)
unnamed: L2.1, U4.3 (SW)
unnamed: R2.2, U3.2 (INH)
unnamed: R3.2, R4.1, U4.1 (FB)
VPP: C7.1, C8.1, L5.1; also elsewhere on the board

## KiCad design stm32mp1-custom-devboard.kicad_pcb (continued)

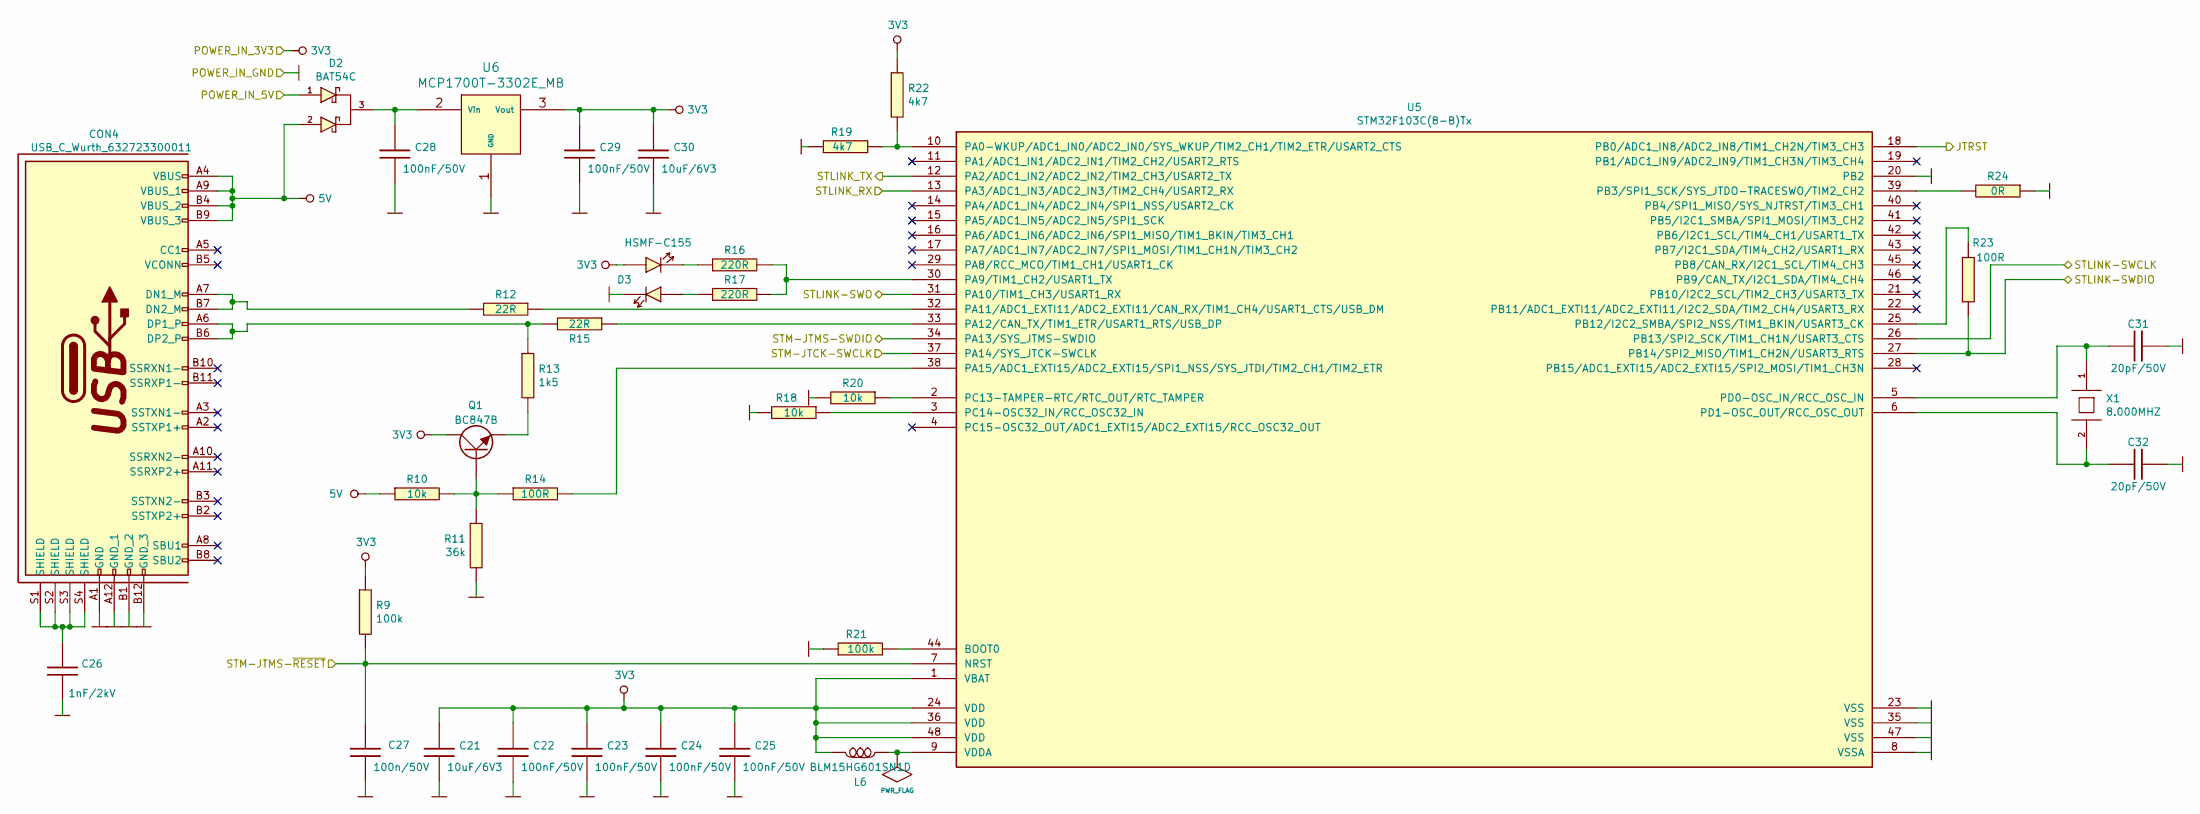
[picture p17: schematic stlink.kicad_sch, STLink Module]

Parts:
C21, C30: 10uF/6V3; 10uF_0805; Manufacturer Part Number CC0805KKX5R5BB106; LCSC Part # (optional) C386087
C22, C23, C24, C25, C28, C29: 100nF/50V; 100nF_0603; Manufacturer Part Number CL10B104JB8NNNC
C26: 1nF/2kV; 1nF_2kV_1206; Manufacturer Part Number CC1206KKX7RDBB102
C27: 100n/50V; 100nF_0603; Manufacturer Part Number CL10B104JB8NNNC
C31, C32: 20pF/50V; 20pF_0603; Manufacturer Part Number C0603C200J5GACTU; LCSC Part #(optional) C165733
CON4: USB_C_Wurth_632723300011; 632723300011; Manufacturer Part Number 632723300011
D2: BAT54C; Manufacturer Part Number BAT54C.215; LCSC Part #(optional) C369922
D3: HSMF-C155; Manufacturer Part Number HSMF-C155; LCSC Part #(optional) C188725
L6: BLM15HG601SN1D; BLM15HG601SN1D_0402
Q1: BC847B; BC847B_SOT23; Manufacturer Part Number BC847BE6327
R9, R21: 100k; 100k_0603; Manufacturer Part Number HP03W5J0104T5E; LCSC Part # (optional) C269699
R10, R18, R20: 10k; 10k_0603; Manufacturer Part Number 0603SAJ0103T5E
R11: 36k; 36k_0603; Manufacturer Part Number 0603SAJ0363T5E; LCSC Part #(optional) C170729
R12, R15: 22R; 22R_0603; Manufacturer Part Number CQ03SAF220JT5E; LCSC Part #(optional) C177623
R13: 1k5; 1k5_0603; Manufacturer Part Number 0603SAF1501T5E; LCSC Part # (optional) C177600
R14, R23: 100R; 100R_0603; Manufacturer Part Number CQ03SAF1000T5E; LCSC Part #(optional) C269700
R16, R17: 220R; 220R_0603; Manufacturer Part Number CQ03SAF2203T5E; LCSC Part #(optional) C103414
R19, R22: 4k7; 4k7_0603; Manufacturer Part Number 0603SAF4701T5E
R24: 0R; 0R_0603; Manufacturer Part Number 0603SAJ0000T5E; LCSC Part #(optional) C15402
U5: STM32F103C(8-B)Tx; STM32F103CBT6; Manufacturer Part Number STM32F103CBT6; LCSC Part #(optional) C8304
U6: MCP1700T-3302E_MB; MCP1700T-3302E_MB_SOT89; Manufacturer Part Number MCP1700T-3302E/MB
X1: 8.000MHZ; ABM3AIG-8.000MHZ-8-1R-T; Manufacturer Part Number ABM3AIG-8.000MHZ-8-1R-T

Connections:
3V3: C21.1, C22.1, C23.1, C24.1, C25.1, C29.1, C30.1, D3.1 (A1), L6.2, Q1.3 (C), R9.1, R22.1, U5.1 (VBAT), U5.24 (VDD), U5.36 (VDD), U5.48 (VDD), U6.3 (Vout); also elsewhere on the board
5V: CON4.A4 (VBUS), CON4.A9 (VBUS_1), CON4.B4 (VBUS_2), CON4.B9 (VBUS_3), D2.1 (A), D2.2 (A), R10.1; also elsewhere on the board
/STLink Module/JTRST: U5.18 (PB0/ADC1_IN8/ADC2_IN8/TIM1_CH2N/TIM3_CH3); also elsewhere on the board
/STLink Module/STLINK-SWCLK: U5.26 (PB13/SPI2_SCK/TIM1_CH1N/USART3_CTS); also elsewhere on the board
/STLink Module/STLINK-SWDIO: R23.1, U5.27 (PB14/SPI2_MISO/TIM1_CH2N/USART3_RTS); also elsewhere on the board
/STLink Module/STLINK-SWO: U5.31 (PA10/TIM1_CH3/USART1_RX); also elsewhere on the board
/STLink Module/STLINK_RX: U5.13 (PA3/ADC1_IN3/ADC2_IN3/TIM2_CH4/USART2_RX); also elsewhere on the board
/STLink Module/STLINK_TX: U5.12 (PA2/ADC1_IN2/ADC2_IN2/TIM2_CH3/USART2_TX); also elsewhere on the board
/STLink Module/STM-JTCK-SWCLK: U5.37 (PA14/SYS_JTCK-SWCLK); also elsewhere on the board
/STLink Module/STM-JTMS-SWDIO: U5.34 (PA13/SYS_JTMS-SWDIO); also elsewhere on the board
/STLink Module/STM-JTMS-~RESET: C27.1, R9.2, U5.7 (NRST); also elsewhere on the board
GND: C21.2, C22.2, C23.2, C24.2, C25.2, C26.1, C27.2, C28.2, C29.2, C30.2, C31.1, C32.1, CON4.A1 (GND), CON4.A12 (GND_1), CON4.B1 (GND_2), CON4.B12 (GND_3), D3.4 (C2), R11.1, R18.2, R19.1, R20.2, R21.1, R24.1, U5.8 (VSSA), U5.20 (PB2), U5.23 (VSS), U5.35 (VSS), U5.47 (VSS), U6.1 (GND); also elsewhere on the board
unnamed: C26.2, CON4.S1 (SHIELD), CON4.S2 (SHIELD), CON4.S3 (SHIELD), CON4.S4 (SHIELD)
unnamed: C28.1, D2.3 (K), U6.2 (Vin)
unnamed: C31.2, U5.5 (PD0-OSC_IN/RCC_OSC_IN), X1.1
unnamed: C32.2, U5.6 (PD1-OSC_OUT/RCC_OSC_OUT), X1.2
unnamed: CON4.A6 (DP1_P), CON4.B6 (DP2_P), R13.1, R15.2
unnamed: CON4.A7 (DN1_M), CON4.B7 (DN2_M), R12.2
unnamed: D3.2 (C1), R16.1
unnamed: D3.3 (A2), R17.1
unnamed: L6.1, U5.9 (VDDA)
unnamed: Q1.1 (B), R10.2, R11.2, R14.1
unnamed: Q1.2 (E), R13.2
unnamed: R12.1, U5.32 (PA11/ADC1_EXTI11/ADC2_EXTI11/CAN_RX/TIM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)
unnamed: R14.2, U5.38 (PA15/ADC1_EXTI15/ADC2_EXTI15/SPI1_NSS/S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)
unnamed: R15.1, U5.33 (PA12/CAN_TX/TIM1_ETR/USART1_RTS/USB_DP)
unnamed: R16.2, R17.2, U5.30 (PA9/TIM1_CH2/USART1_TX)
unnamed: R18.1, U5.3 (PC14-OSC32_IN/RCC_OSC32_IN)
unnamed: R19.2, R22.2, U5.10 (PA0-WKUP/ADC1_IN0/ADC2_IN0/SYS_WKUP/TIM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)
unnamed: R20.1, U5.2 (PC13-TAMPER-RTC/RTC_OUT/RTC_TAMPER)
unnamed: R21.2, U5.44 (BOOT0)
unnamed: R23.2, U5.25 (PB12/I2C2_SMBA/SPI2_NSS/TIM1_BKIN/USART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)
unnamed: R24.2, U5.39 (PB3/SPI1_SCK/SYS_JTDO-TRACESWO/TIM2_CH2)

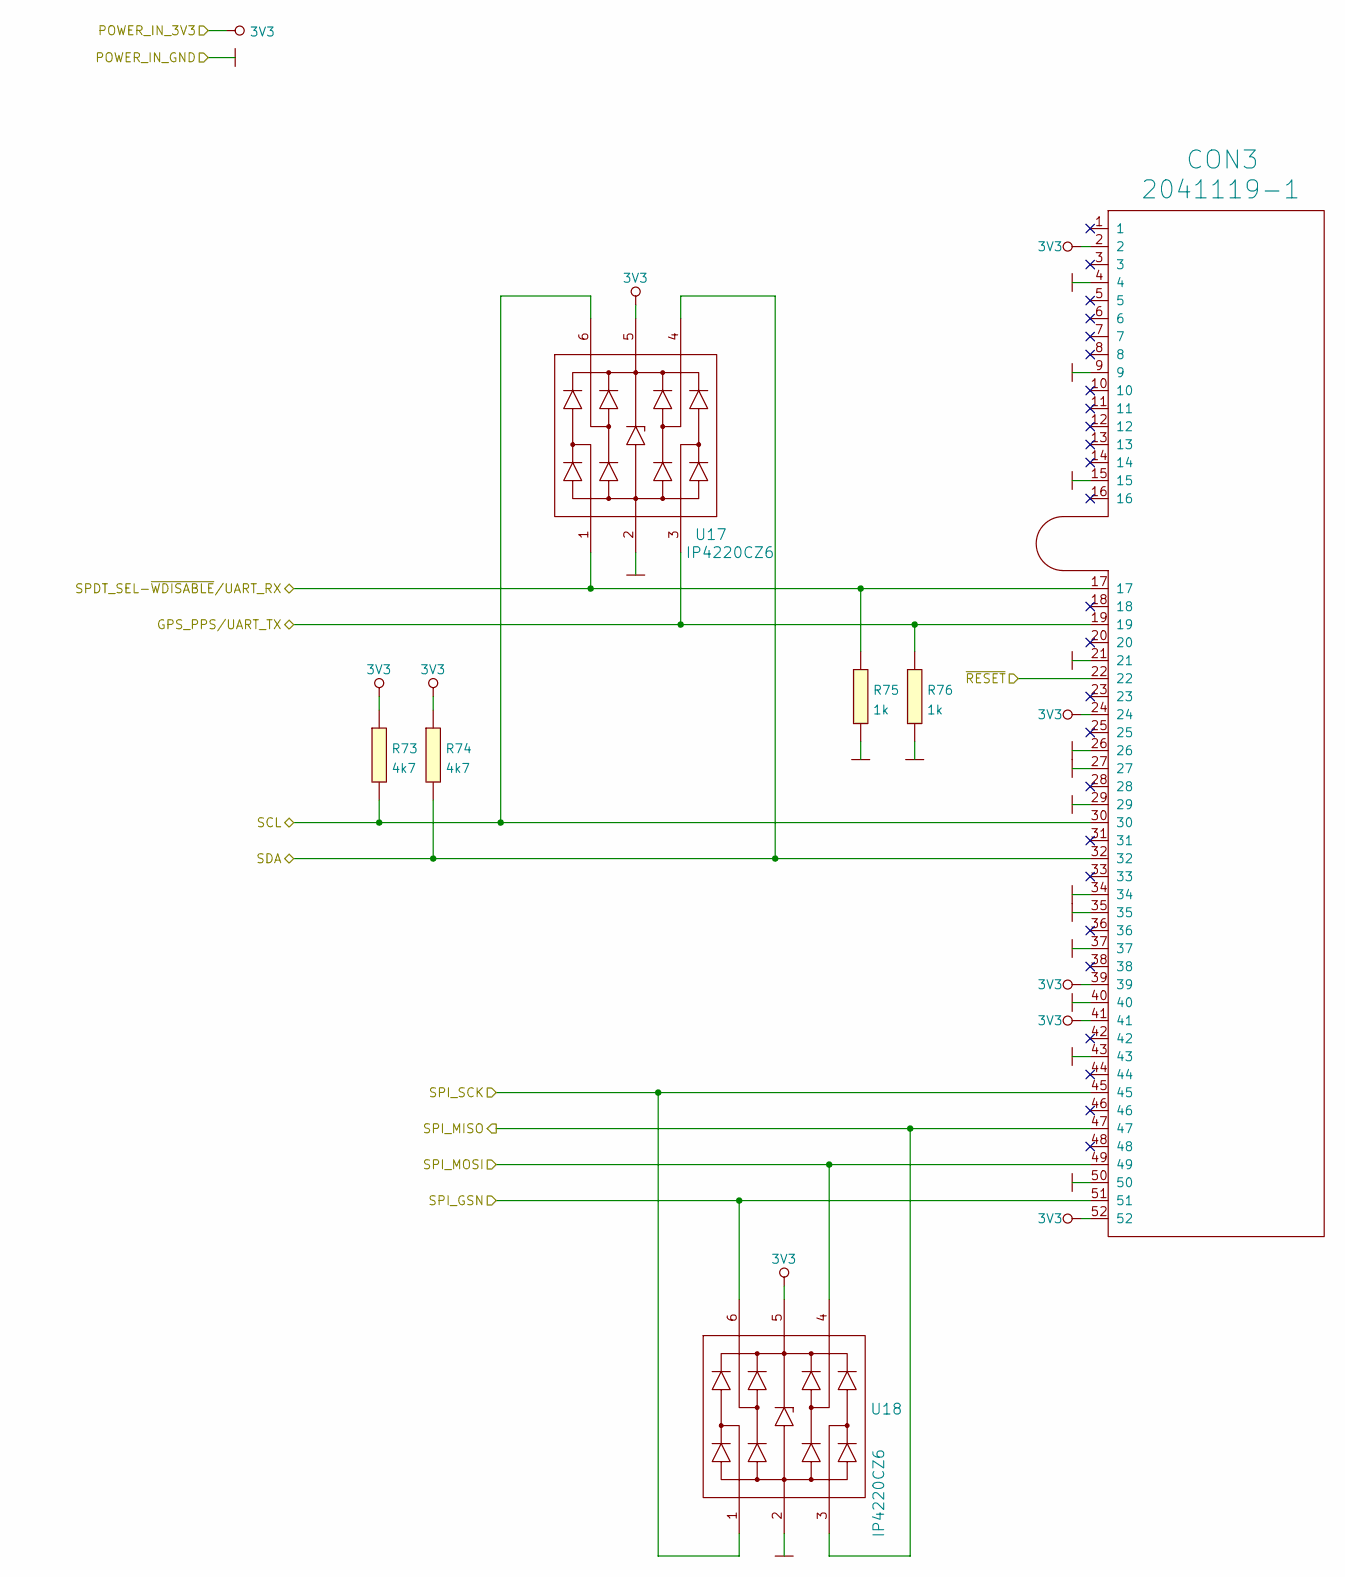
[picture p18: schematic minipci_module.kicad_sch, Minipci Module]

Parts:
CON3: 2041119-1; Manufacturer Part Number 2041119-1
R73, R74: 4k7; 4k7_0402; Manufacturer Part Number 0402WGF4701TCE
R75, R76: 1k; 1k_0402; Manufacturer Part Number SMD0402-1K-1%; LCSC Part #(optional) C269675
U17, U18: IP4220CZ6; IP4220CZ6_SOT457; Manufacturer Part Number IP4220CZ6.125; LCSC Part #(optional) C2687127

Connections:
3V3: CON3.2, CON3.24, CON3.39, CON3.41, CON3.52, R73.1, R74.1, U17.5 (Vp), U18.5 (Vp); also elsewhere on the board
/MiniPci Module/GPS_PPS/UART_TX: CON3.19, R76.1, U17.3 (I/O2); also elsewhere on the board
/MiniPci Module/SCL: CON3.30, R73.2, U17.6 (I/O4); also elsewhere on the board
/MiniPci Module/SDA: CON3.32, R74.2, U17.4 (I/O3); also elsewhere on the board
/MiniPci Module/SPDT_SEL-~WDISABLE/UART_RX: CON3.17, R75.1, U17.1 (I/O1); also elsewhere on the board
/MiniPci Module/SPI_GSN: CON3.51, U18.6 (I/O4); also elsewhere on the board
/MiniPci Module/SPI_MISO: CON3.47, U18.3 (I/O2); also elsewhere on the board
/MiniPci Module/SPI_MOSI: CON3.49, U18.4 (I/O3); also elsewhere on the board
/MiniPci Module/SPI_SCK: CON3.45, U18.1 (I/O1); also elsewhere on the board
/MiniPci Module/~RESET: CON3.22; also elsewhere on the board
GND: CON3.4, CON3.9, CON3.15, CON3.21, CON3.26, CON3.27, CON3.29, CON3.34, CON3.35, CON3.37, CON3.40, CON3.43, CON3.50, R75.2, R76.2, U17.2 (GND), U18.2 (GND); also elsewhere on the board

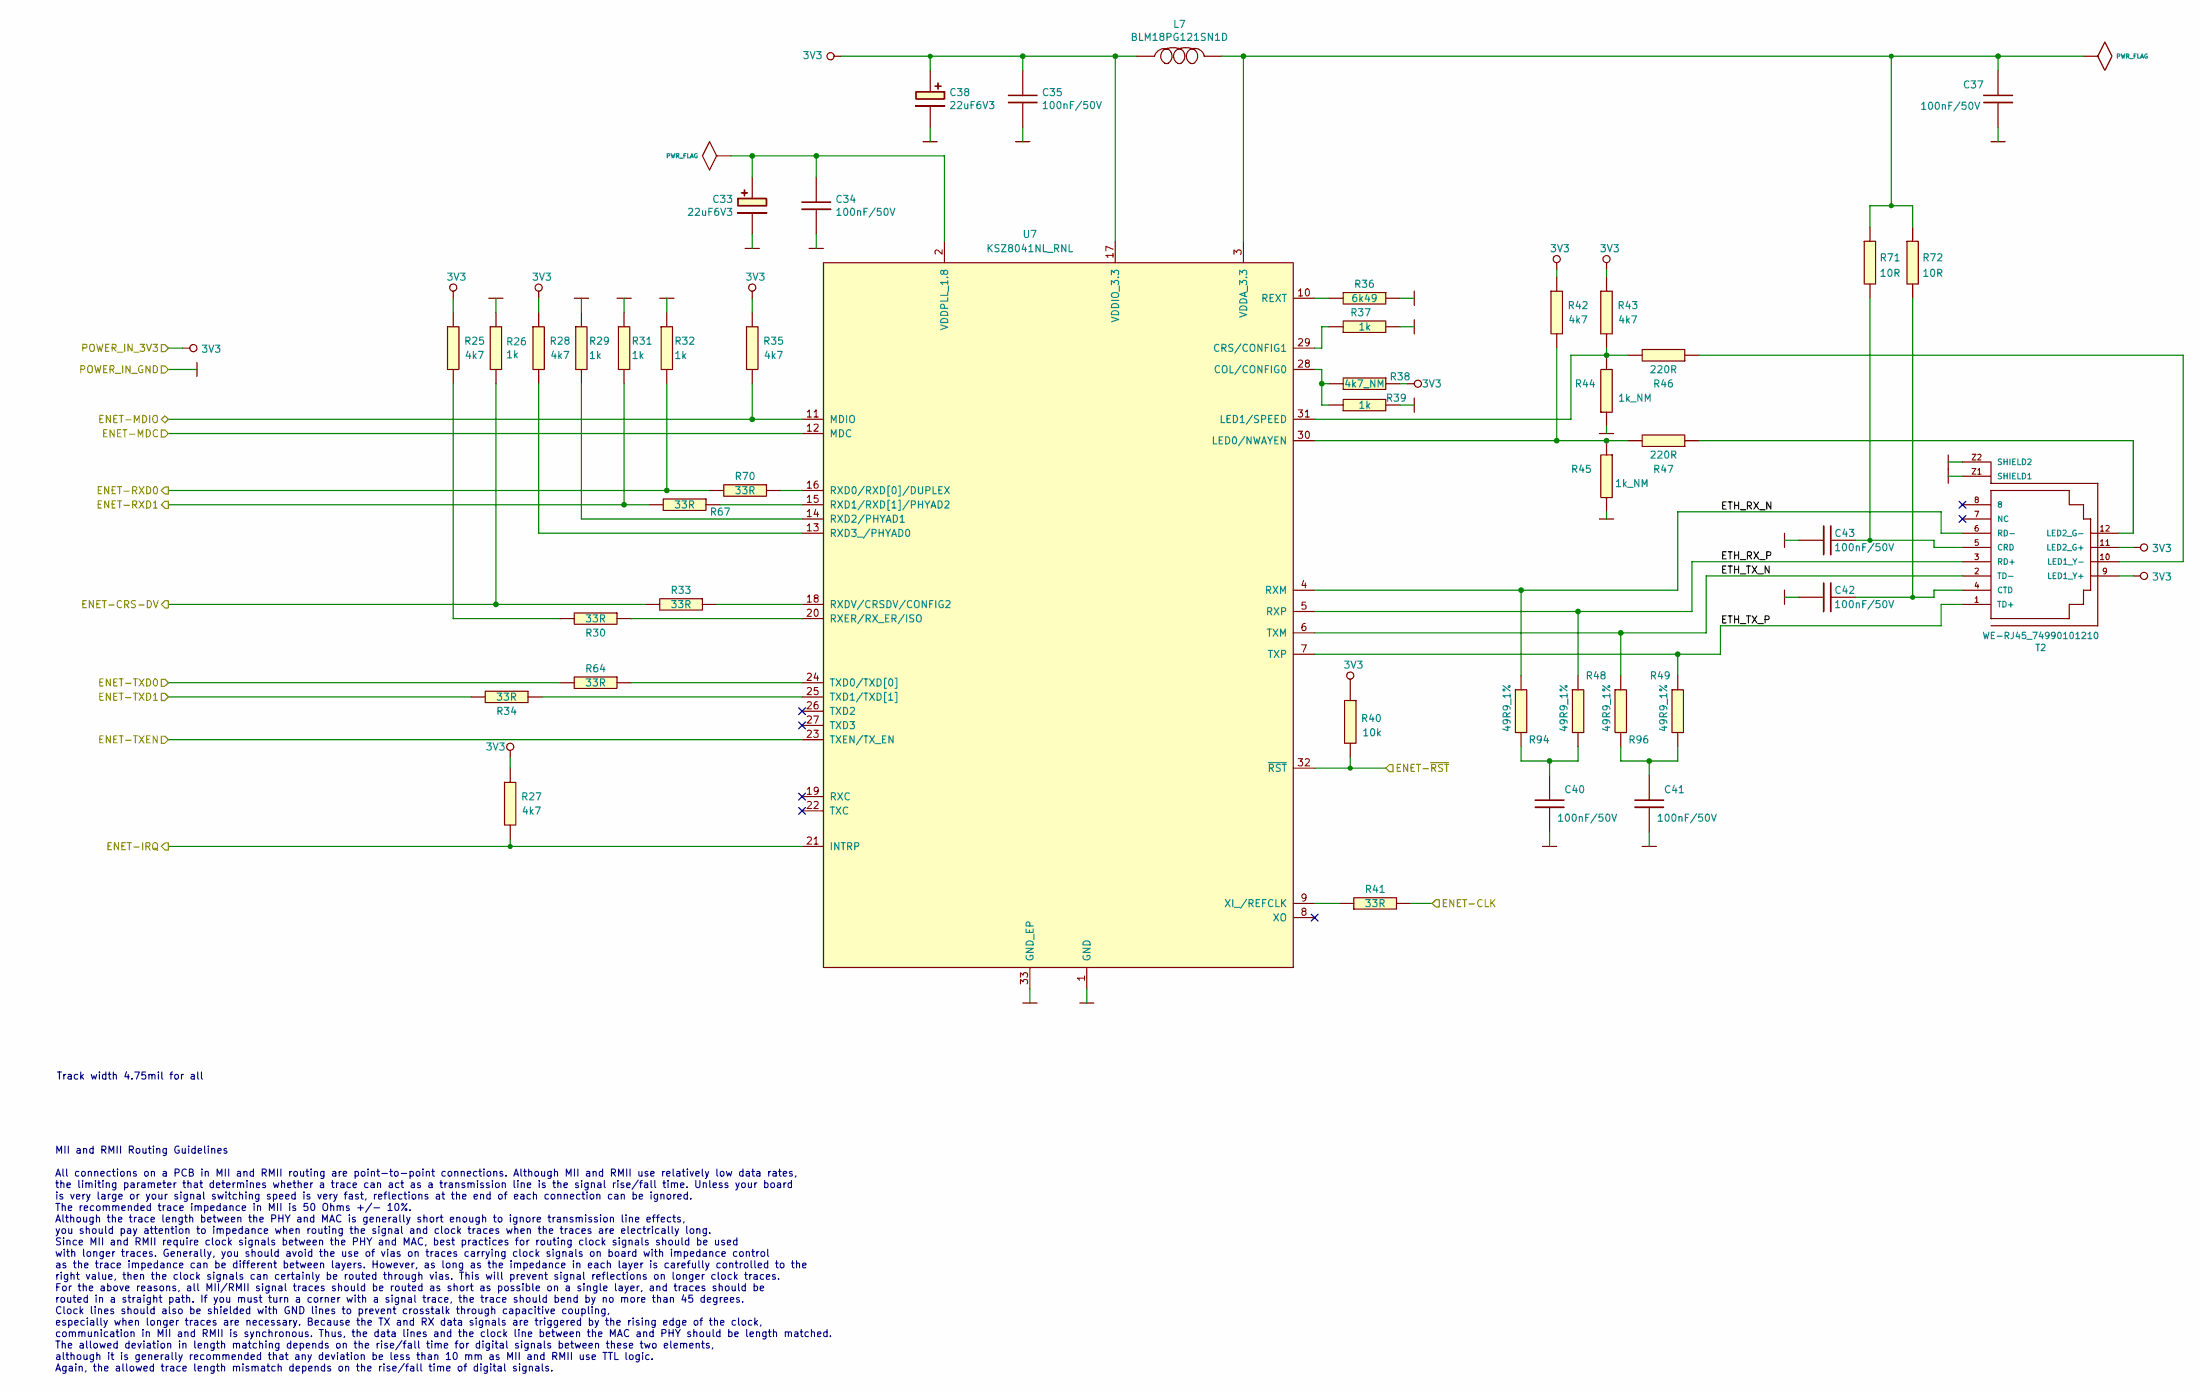
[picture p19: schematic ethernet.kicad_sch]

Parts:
C33, C38: 22uF6V3; 22uF6V3_1206; Manufacturer Part Number 293D226X9010C2TE3; LCSC Part #(optional) C123266
C34, C35, C37, C40, C41, C42, C43: 100nF/50V; 100nF_0402; Manufacturer Part Number CL10B104JB8NNNC; LCSC Part # (optional) C131394
L7: BLM18PG121SN1D; BLM18PG121SN1D_SM0603
R25, R27, R28, R35, R42, R43: 4k7; 4k7_0603
R26, R29, R31, R32, R37, R39: 1k; 1k_0603
R30, R33, R34, R41, R64, R67, R70: 33R; 33R_0402; Manufacturer Part Number CQ02WGF330JTCE; LCSC Part #(optional) C208868
R36: 6k49; 6k49_0603
R38: 4k7_NM; 4k7_0603
R40: 10k; 10k_0603
R44, R45: 1k_NM; 1k_0603
R46, R47: 220R; 220R_0603
R48, R49, R94, R96: 49R9_1%; 49R9_0402; Manufacturer Part Number 0402WGF499JTCE; LCSC Part #(optional) C325388
R71, R72: 10R; 10R_0402; Manufacturer Part Number 0402WGF100JTCE; LCSC Part # (optional) C269385
T2: WE-RJ45_74990101210; Manufacturer Part Number 74990101210
U7: KSZ8041NL_RNL; KSZ8041NL_RNL_QFN32; Manufacturer Part Number KSZ8041NL-TR; LCSC Part #(optional) C11146

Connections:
3V3: C35.1, C38.1, L7.1, R25.1, R27.1, R28.1, R35.1, R38.1, R40.1, R42.1, R43.1, T2.9 (LED1_Y+), T2.11 (LED2_G+), U7.17 (VDDIO_3.3); also elsewhere on the board
/Ethernet Module/ENET-CLK: R41.2; also elsewhere on the board
/Ethernet Module/ENET-CRS-DV: R26.2, R33.2; also elsewhere on the board
/Ethernet Module/ENET-IRQ: R27.2, U7.21 (INTRP); also elsewhere on the board
/Ethernet Module/ENET-MDC: U7.12 (MDC); also elsewhere on the board
/Ethernet Module/ENET-MDIO: R35.2, U7.11 (MDIO); also elsewhere on the board
/Ethernet Module/ENET-RXD0: R32.2, R70.2; also elsewhere on the board
/Ethernet Module/ENET-RXD1: R31.2, R67.2; also elsewhere on the board
/Ethernet Module/ENET-TXD0: R64.2; also elsewhere on the board
/Ethernet Module/ENET-TXD1: R34.2; also elsewhere on the board
/Ethernet Module/ENET-TXEN: U7.23 (TXEN/TX_EN); also elsewhere on the board
/Ethernet Module/ENET-~RST: R40.2, U7.32 (~RST); also elsewhere on the board
/Ethernet Module/ETH_RX_N: R94.1, T2.6 (RD-), U7.4 (RXM)
/Ethernet Module/ETH_RX_P: R48.1, T2.3 (RD+), U7.5 (RXP)
/Ethernet Module/ETH_TX_N: R96.1, T2.2 (TD-), U7.6 (TXM)
/Ethernet Module/ETH_TX_P: R49.1, T2.1 (TD+), U7.7 (TXP)
GND: C33.2, C34.2, C35.2, C37.2, C38.2, C40.2, C41.2, C42.1, C43.1, R26.1, R29.1, R31.1, R32.1, R36.1, R37.2, R39.2, R44.1, R45.2, T2.Z1 (SHIELD1), T2.Z2 (SHIELD2), U7.1 (GND), U7.33 (GND_EP); also elsewhere on the board
unnamed: C33.1, C34.1, U7.2 (VDDPLL_1.8)
unnamed: C37.1, L7.2, R71.1, R72.1, U7.3 (VDDA_3.3)
unnamed: C40.1, R48.2, R94.2
unnamed: C41.1, R49.2, R96.2
unnamed: C42.2, R72.2, T2.4 (CTD)
unnamed: C43.2, R71.2, T2.5 (CRD)
unnamed: R25.2, R30.2
unnamed: R28.2, U7.13 (RXD3_/PHYAD0)
unnamed: R29.2, U7.14 (RXD2/PHYAD1)
unnamed: R30.1, U7.20 (RXER/RX_ER/ISO)
unnamed: R33.1, U7.18 (RXDV/CRSDV/CONFIG2)
unnamed: R34.1, U7.25 (TXD1/TXD[1])
unnamed: R36.2, U7.10 (REXT)
unnamed: R37.1, U7.29 (CRS/CONFIG1)
unnamed: R38.2, R39.1, U7.28 (COL/CONFIG0)
unnamed: R41.1, U7.9 (XI_/REFCLK)
unnamed: R42.2, R45.1, R47.2, U7.30 (LED0/NWAYEN)
unnamed: R43.2, R44.2, R46.2, U7.31 (LED1/SPEED)
unnamed: R46.1, T2.10 (LED1_Y-)
unnamed: R47.1, T2.12 (LED2_G-)
unnamed: R64.1, U7.24 (TXD0/TXD[0])
unnamed: R67.1, U7.15 (RXD1/RXD[1]/PHYAD2)
unnamed: R70.1, U7.16 (RXD0/RXD[0]/DUPLEX)

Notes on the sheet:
Track width 4.75mil for all
MII and RMII Routing Guidelines All connections on a PCB in MII and RMII routing are point-to-point connections. Although MII and RMII use relatively low data rates, the limiting parameter that determines whether a trace can act as a transmission line is the signal rise/fall time. Unless your board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

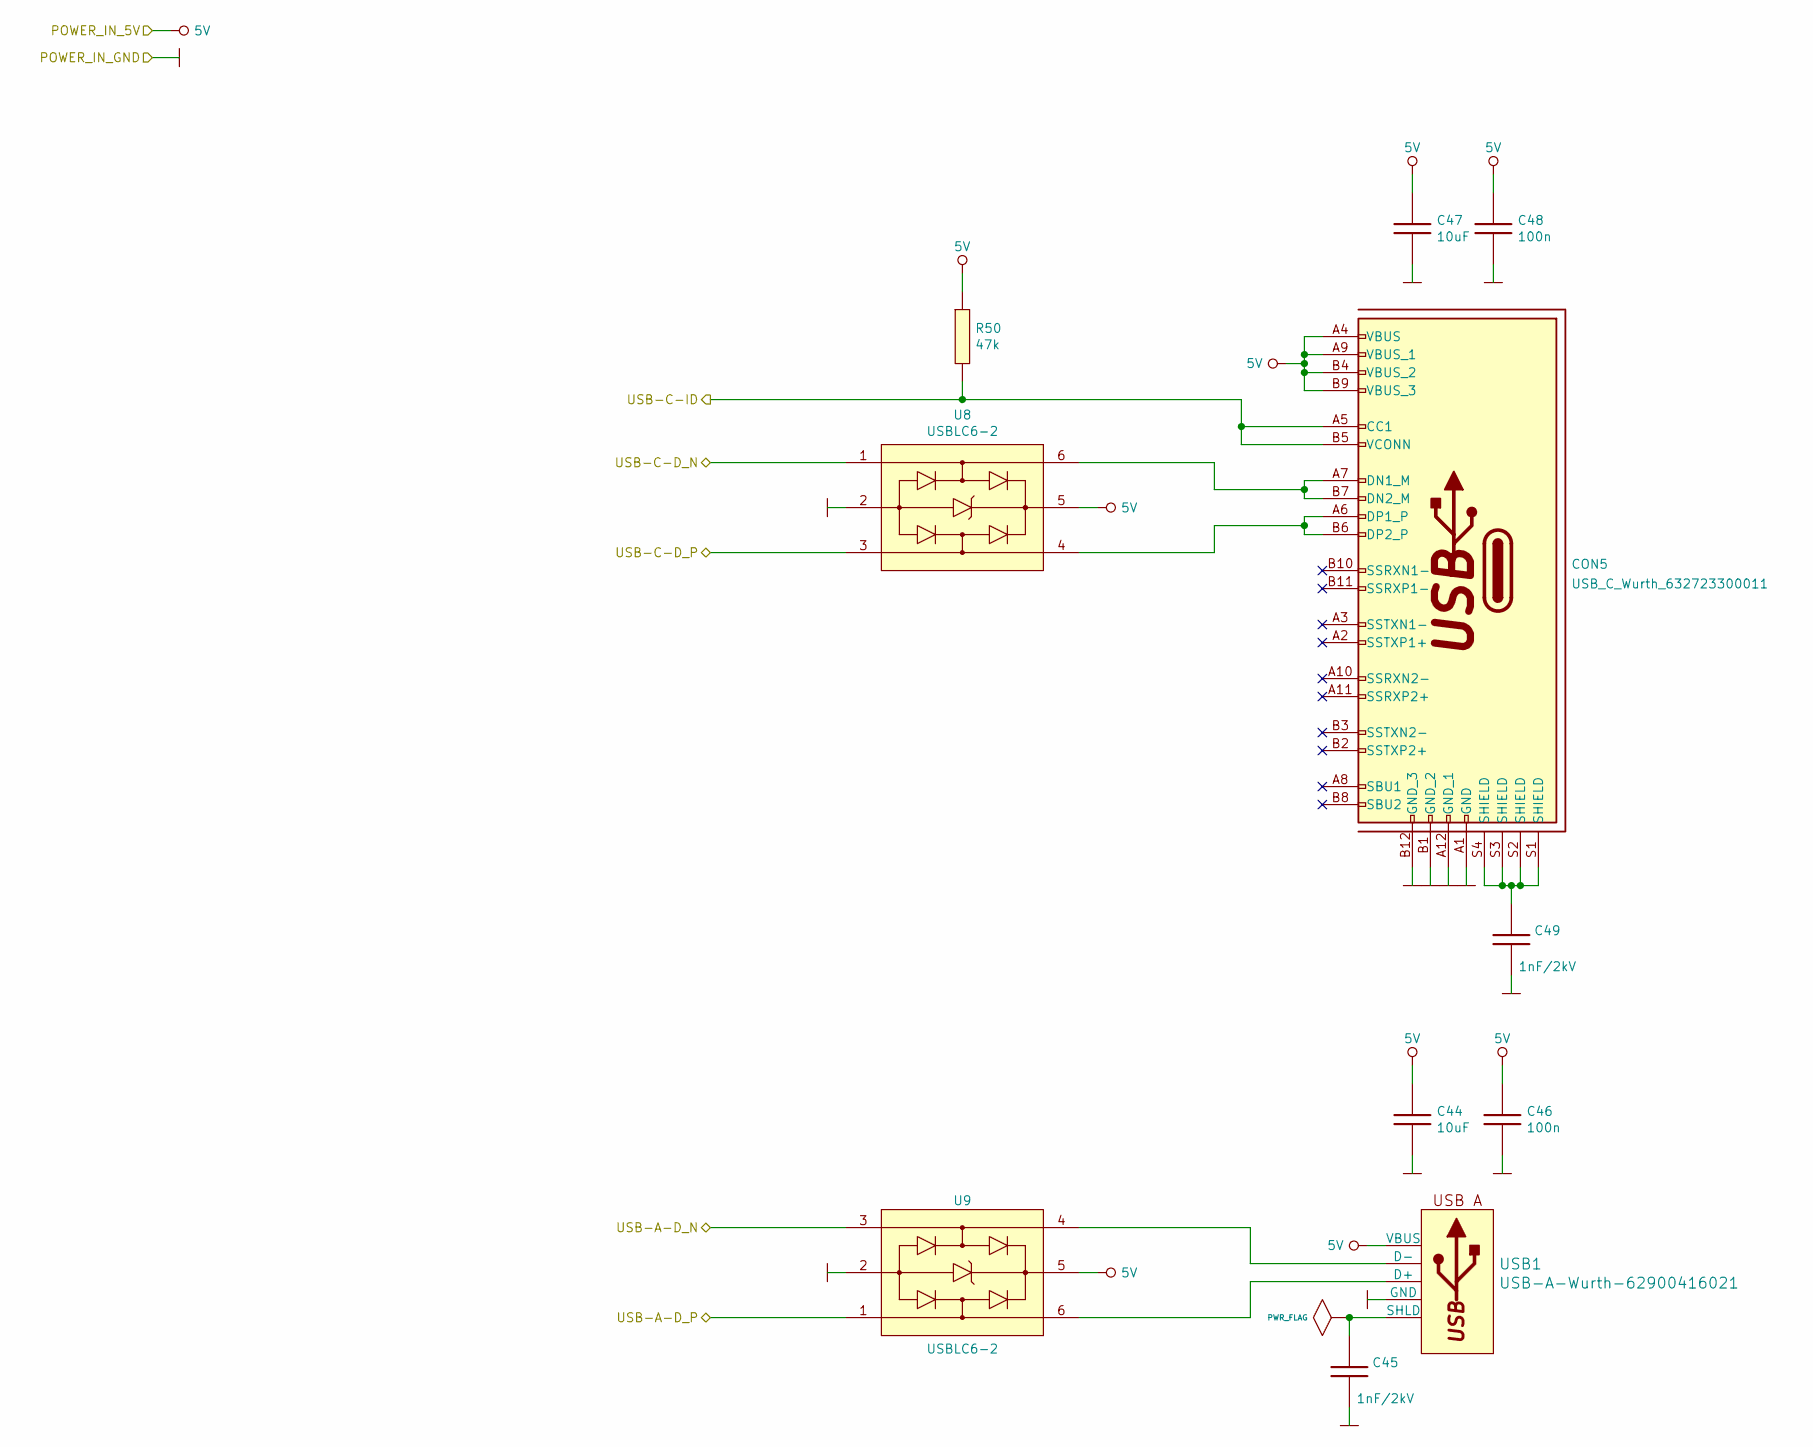
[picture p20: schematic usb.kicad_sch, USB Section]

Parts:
C44, C47: 10uF; 10uF_10V_0603; Manufacturer Part Number C0603C106M9PACTU; LCSC Part # (optional) C162265
C45, C49: 1nF/2kV; 1nF_2kV_1206; Manufacturer Part Number CC1206KKX7RDBB102
C46, C48: 100n; 100nF_0603; Manufacturer Part Number CL10B104JB8NNNC
CON5: USB_C_Wurth_632723300011; 632723300011; Manufacturer Part Number 632723300011
R50: 47k; 47k_0603; Manufacturer Part Number 0603SAF4702T5E; LCSC Part #(optional) C105579
U8, U9: USBLC6-2; USBLC6-2_SOT23-6L; Manufacturer Part Number USBLC6-2SC6; LCSC Part #(optional) C7519
USB1: USB-A-Wurth-62900416021; Wurth-62900416021; Manufacturer Part Number 62900416021

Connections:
5V: C44.1, C46.1, C47.1, C48.1, CON5.A4 (VBUS), CON5.A9 (VBUS_1), CON5.B4 (VBUS_2), CON5.B9 (VBUS_3), R50.1, U8.5, U9.5, USB1.1 (VBUS); also elsewhere on the board
/STM32MP1 module/PA13-GPIO: CON5.A5 (CC1), CON5.B5 (VCONN), R50.2; also elsewhere on the board
/STM32MP1 module/USB-OTG1-D_N: U9.3; also elsewhere on the board
/STM32MP1 module/USB-OTG1-D_P: U9.1; also elsewhere on the board
/STM32MP1 module/USB-OTG2-D_N: U8.1; also elsewhere on the board
/STM32MP1 module/USB-OTG2-D_P: U8.3; also elsewhere on the board
GND: C44.2, C45.1, C46.2, C47.2, C48.2, C49.1, CON5.A1 (GND), CON5.A12 (GND_1), CON5.B1 (GND_2), CON5.B12 (GND_3), U8.2, U9.2, USB1.4 (GND); also elsewhere on the board
unnamed: C45.2, USB1.SH (SHLD)
unnamed: C49.2, CON5.S1 (SHIELD), CON5.S2 (SHIELD), CON5.S3 (SHIELD), CON5.S4 (SHIELD)
unnamed: CON5.A6 (DP1_P), CON5.B6 (DP2_P), U8.4
unnamed: CON5.A7 (DN1_M), CON5.B7 (DN2_M), U8.6
unnamed: U9.4, USB1.2 (D-)
unnamed: U9.6, USB1.3 (D+)

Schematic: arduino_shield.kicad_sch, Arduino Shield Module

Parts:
C50, C51: 10uF; 10uF_10V_0603; Manufacturer Part Number C0603C106M9PACTU; LCSC Part # (optional) C162265
C52, C53: 100n; 100nF_0603; Manufacturer Part Number CL10B104JB8NNNC
R60, R61: 4k7; 4k7_0603; Manufacturer Part Number 0603SAF4701T5E
U12, U13, U14, U15, U16: IP4220CZ6; IP4220CZ6_SOT457; Manufacturer Part Number IP4220CZ6.125; LCSC Part #(optional) C2687127
XA1: Arduino_101_Shield

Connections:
3V3: C51.1, C53.1, R60.1, R61.1, U12.5 (Vp), U13.5 (Vp), U14.5 (Vp), U15.5 (Vp), U16.5 (Vp), XA1.3V3 (3.3V); also elsewhere on the board
5V: C50.1, C52.1, XA1.5V1 (5V), XA1.5V2 (SPI_5V); also elsewhere on the board
/Arduino Shield Module/ANALOG_A0: XA1.A0; also elsewhere on the board
/Arduino Shield Module/ANALOG_A1: XA1.A1; also elsewhere on the board
/Arduino Shield Module/ANALOG_A2: XA1.A2; also elsewhere on the board
/Arduino Shield Module/ANALOG_A3: XA1.A3; also elsewhere on the board
/Arduino Shield Module/ANALOG_A4: XA1.A4; also elsewhere on the board
/Arduino Shield Module/ANALOG_A5: XA1.A5; also elsewhere on the board
/Arduino Shield Module/ATN: XA1.ATN; also elsewhere on the board
/Arduino Shield Module/GPIO-D2: U13.1 (I/O1), XA1.D2; also elsewhere on the board
/Arduino Shield Module/GPIO-D3: U13.3 (I/O2), XA1.D3; also elsewhere on the board
/Arduino Shield Module/GPIO-D4: U13.6 (I/O4), XA1.D4; also elsewhere on the board
/Arduino Shield Module/GPIO-D5: U13.4 (I/O3), XA1.D5; also elsewhere on the board
/Arduino Shield Module/GPIO-D6: U14.1 (I/O1), XA1.D6; also elsewhere on the board
/Arduino Shield Module/GPIO-D7: U14.3 (I/O2), XA1.D7; also elsewhere on the board
/Arduino Shield Module/GPIO-D8: U14.6 (I/O4), XA1.D8; also elsewhere on the board
/Arduino Shield Module/GPIO-D9: U14.4 (I/O3), XA1.D9; also elsewhere on the board
/Arduino Shield Module/GPIO-D10: U16.1 (I/O1), XA1.D10 (D10_CS); also elsewhere on the board
/Arduino Shield Module/GPIO-D11: U16.3 (I/O2), XA1.D11; also elsewhere on the board
/Arduino Shield Module/GPIO-D12: U16.6 (I/O4), XA1.D12; also elsewhere on the board
/Arduino Shield Module/GPIO-D13: U16.4 (I/O3), XA1.D13; also elsewhere on the board
/Arduino Shield Module/I2C-SCL: R60.2, U12.6 (I/O4), XA1.SCL; also elsewhere on the board
/Arduino Shield Module/I2C-SDA: R61.2, U12.4 (I/O3), XA1.SDA; also elsewhere on the board
/Arduino Shield Module/IOREF: XA1.IORF (IOREF); also elsewhere on the board
/Arduino Shield Module/RESET: XA1.RST1 (RESET); also elsewhere on the board
/Arduino Shield Module/SPI-MISO: U15.1 (I/O1), XA1.MISO (SPI_MISO); also elsewhere on the board
/Arduino Shield Module/SPI-MOSI: U15.3 (I/O2), XA1.MOSI (SPI_MOSI); also elsewhere on the board
/Arduino Shield Module/SPI-RST: U15.6 (I/O4), XA1.RST2 (SPI_RESET); also elsewhere on the board
/Arduino Shield Module/SPI-SCK: U15.4 (I/O3), XA1.SCK (SPI_SCK); also elsewhere on the board
/Arduino Shield Module/UART-RX0: U12.3 (I/O2), XA1.D0 (D0_RX0); also elsewhere on the board
/Arduino Shield Module/UART-TX0: U12.1 (I/O1), XA1.D1 (D1_TX0); also elsewhere on the board
GND: C50.2, C51.2, C52.2, C53.2, U12.2 (GND), U13.2 (GND), U14.2 (GND), U15.2 (GND), U16.2 (GND), XA1.GND1 (GND), XA1.GND2 (GND), XA1.GND3 (GND), XA1.GND4 (SPI_GND); also elsewhere on the board
VCC-RTC: XA1.AREF
VPP: XA1.VIN; also elsewhere on the board

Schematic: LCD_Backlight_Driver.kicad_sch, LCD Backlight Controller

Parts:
C1: 1uF/6V3; 1uF_0603; Manufacturer Part Number CL10B105KO8NNNC
C2: 4.7uF/35V; 4_7uF_0603; Manufacturer Part Number CL10A475KQ8NNNC
D1: NSR0530H-D; NSR0530H-D_SOD323
L3: 4.7uH-0.9A-74438333047; Manufacturer Part Number 74438333047
R1: 10Ω/1%/0.1Wat; 10R_0603; Manufacturer Part Number 0603SAF100JT5E; LCSC Part # (optional) C269702
U1: TPS61169DCKR; Manufacturer Part Number TPS61169DCKR; LCSC Part # (optional) C71045

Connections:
3V3: C1.1, L3.1, U1.5 (VIN); also elsewhere on the board
/LCD+Touchscreen/LCD Backlight Controller/BACKLIGHT_HIGH: C2.1, D1.1 (K); also elsewhere on the board
/LCD+Touchscreen/LCD Backlight Controller/BACKLIGHT_LOW: R1.1, U1.3 (FB); also elsewhere on the board
/LCD+Touchscreen/LCD_BACKLIGHT_PWM: U1.4 (CTRL); also elsewhere on the board
GND: C1.2, C2.2, R1.2, U1.2 (GND); also elsewhere on the board
unnamed: D1.2 (A), L3.2, U1.1 (SW)

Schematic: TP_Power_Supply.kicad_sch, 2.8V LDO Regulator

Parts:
C3, C4: 1uF/16V; 1uF_0603; Manufacturer Part Number CL10B105KO8NNNC
U2: MCP1703T-3302E; MCP1703T-3302E_SOT23; Manufacturer Part Number MCP1703T-3302E/CB; LCSC Part #(optional) C39051

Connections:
3V3: C3.1, U2.3 (Vin); also elsewhere on the board
/LCD+Touchscreen/Touchscreen Power Supply/VOUT_3.3V_250mA: C4.1, U2.2 (Vout); also elsewhere on the board
GND: C3.2, C4.2, U2.1 (GND); also elsewhere on the board

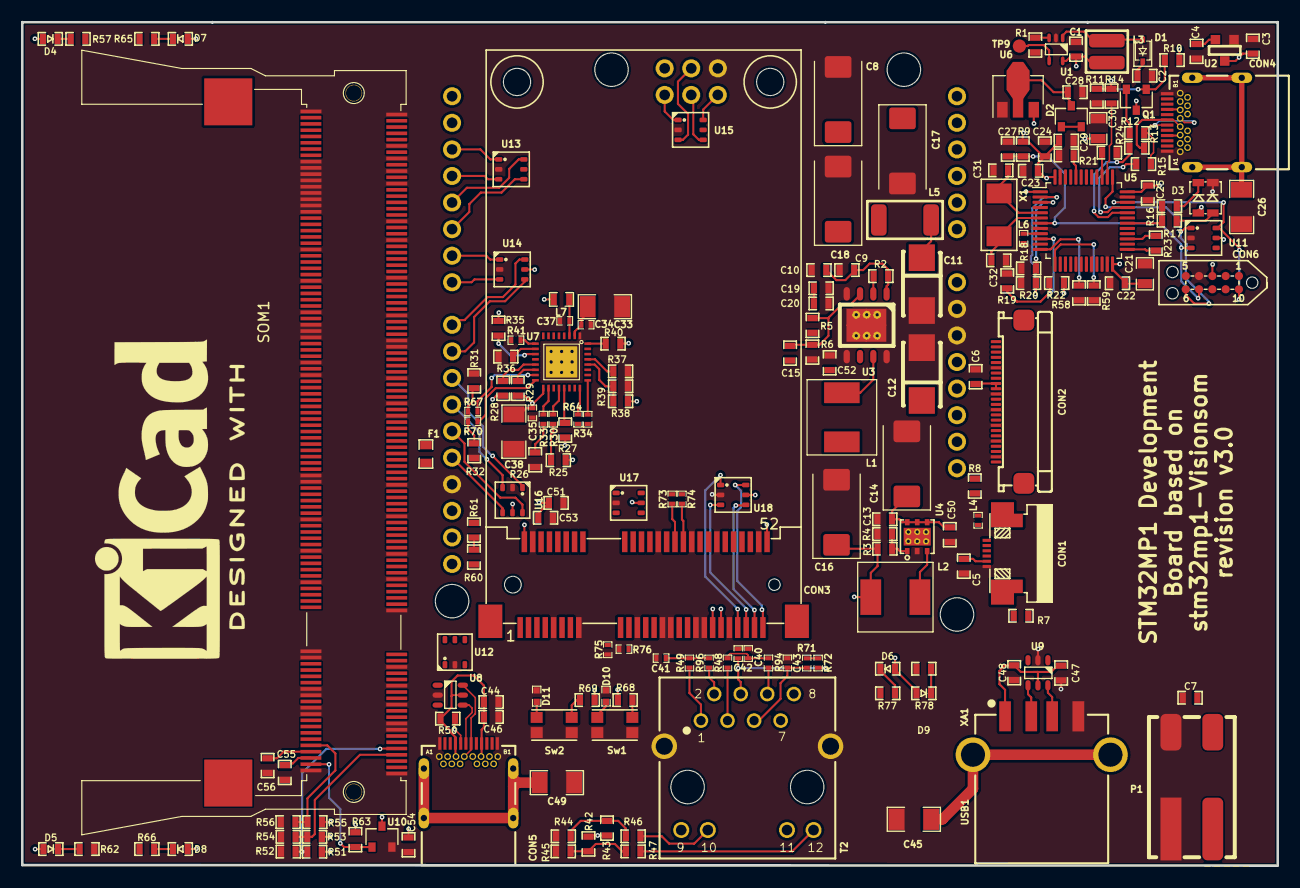
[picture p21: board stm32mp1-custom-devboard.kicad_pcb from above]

Board: 4 copper layers, 120.0 x 80.6 mm, 194 parts (0 on the bottom side), 167 nets.

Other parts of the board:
REF1: KiCad-Logo2_12mm_SilkScreen

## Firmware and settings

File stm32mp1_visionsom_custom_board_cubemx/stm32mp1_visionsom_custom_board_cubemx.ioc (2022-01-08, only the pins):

Mcu.UserName=STM32MP157AABx
PA1.Signal=ETH1_CLK
PA10.Signal=SPI3_NSS
PA11.GPIO_Label=BUTTON1
PA11.Signal=GPIO_Input
PA12.GPIO_Label=BUTTON2
PA12.Signal=GPIO_Input
PA2.Signal=ETH1_MDIO
PA4.Signal=SPI1_NSS
PA5.Signal=ADCx_INP19
PA6.Signal=ADCx_INP3
PA7.Signal=ETH1_CRS_DV
PB10.Signal=GPIO_Output
PB11.Signal=ETH1_TX_EN
PB13.Signal=ETH1_TXD1
PB2.Signal=UART4_RX
PB3.Signal=SPI1_SCK
PB4.Signal=SPI1_MISO
PB5.Signal=SPI1_MOSI
PB7.Signal=I2C4_SDA
PC0.Signal=ADCx_INP10
PC1.Signal=ETH1_MDC
PC10.Signal=SPI3_SCK
PC11.Signal=SDMMC1_D3
PC12.Signal=SDMMC1_CK
PC13.Signal=RTC_LSCO
PC14-OSC32_IN.Signal=RCC_OSC32_IN
PC15-OSC32_OUT.Signal=RCC_OSC32_OUT
PC4.Signal=ETH1_RXD0
PC5.Signal=ETH1_RXD1
PC7.GPIO_Label=MINIPCI_RESET
PC7.Signal=GPIO_Output
PC8.Signal=SDMMC1_D0
PC9.Signal=SDMMC1_D1
PD10.Signal=SPI3_MISO
PD14.GPIO_Label=LED2
PD14.Signal=GPIO_Output
PD15.Signal=S_TIM4_CH4
PD2.Signal=SDMMC1_CMD
PD6.Signal=SPI3_MOSI
PE0.GPIO_Label=GPS_PPS
PE0.Signal=GPIO_Output
PE1.GPIO_Label=SPDT_SEL-WDISABLE
PE1.Signal=GPIO_Output
PE10.Signal=GPIO_Output
PE14.GPIO_Label=LED3
PE14.Signal=GPIO_Output
PE2.Signal=I2C4_SCL
PE3.GPIO_Label=LED1
PE3.Signal=GPIO_Output
PE6.Signal=SDMMC1_D2
PF11.Signal=ADC1_INP2
PG11.Signal=UART4_TX
PG12.Signal=ETH1_PHY_INTN
PG13.Signal=ETH1_TXD0
PH0-OSC_IN.Signal=RCC_OSC_IN

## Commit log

2020-12-19 Added display section
    [LCD_Backlight_Driver.sch, LCD_Touchscreen.sch, Mipi_Dsi_Track_Tunning_Calculations.ods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]
2020-12-19 Added stm32mp1 module and arduino shield
    [LCD_Backlight_Driver.sch, LCD_Touchscreen.sch, TP_Power_Supply.sch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]
2020-12-19 Added new components and hierarchical sheets
    [LCD_Backlight_Driver.sch, LCD_Touchscreen.sch, TP_Power_Supply.sch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]
2020-12-20 Added power source module
    [power_supply.sch, stm32mp1-custom-devboard.kicad_pcb, stm32mp1-custom-devboard.sch]
2020-12-20 Added Mipi Dsi connection, started stlink module
    [LCD_Backlight_Driver.sch, LCD_Touchscreen.sch, TP_Power_Supply.sch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]
2021-01-10 Added minipci connector
    [LCD_Backlight_Driver.sch, LCD_Touchscreen.sch, TP_Power_Supply.sch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]
2021-01-12 Continue work at jtag
    [stlink.sch]
2021-01-12 Finished work at st-link, figurated elements on pcb
    [minipci_module.sch, stlink.sch, stm32mp1-custom-devboard.kicad_pcb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]
2021-01-13 Added ethernet and usb module
    [LCD_Backlight_Driver.sch, LCD_Touchscreen.sch, TP_Power_Supply.sch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]
2021-01-13 Added new USB connectors on schematic, figurated elements on pcb
    [stm32mp1-custom-devboard.kicad_pcb, stm32mp1-custom-devboard.sch, usb.sch]
2021-01-18 Updated schematic, added some components, figurated components on pcb
    [arduino_shield.sch, stlink.sch, stm32mp1-custom-devboard.kicad_pcb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]
2021-01-18 Schematic work contiune, added pinout spreadsheet
    [minipci_module.sch, stm32mp1-custom-devboard.kicad_pcb, stm32mp1-custom-devboard.sch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]
2021-01-18 Schematic finished, elements figurated on pcb, tracking started
    [mpu_module.sch, stm32mp1-custom-devboard.kicad_pcb, stm32mp1-custom-devboard.sch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]
2021-01-19 Tracking in progress
    [stm32mp1-custom-devboard.kicad_pcb, usb.sch]
2021-01-19 Tracking almost finished
    [stm32mp1-custom-devboard.kicad_pcb]
2021-01-19 Tracking finished, started tunning
    [LCD_Touchscreen.sch, arduino_shield.sch, ethernet.sch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]
2021-01-20 Added gnd in stm32f swd interface
    [stm32mp1-custom-devboard.kicad_pcb, stm32mp1-custom-devboard.sch]
2021-01-20 Added missing components like LED diodes, i2c pull-up resistors
    [arduino_shield.sch, minipci_module.sch, stm32mp1-custom-devboard.kicad_pcb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]
2021-01-20 Added BOM list
    [stm32mp1-custom-devboard_bom_V1.0.xls]
2021-01-20 BOM corrections
    [stm32mp1-custom-devboard_bom_V1.0.xls]
2021-01-20 Added missing URLs in BOM
    [LCD_Backlight_Driver.sch, stm32mp1-custom-devboard.kicad_pcb, stm32mp1-custom-devboard.sch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]
2021-01-20 High speed track tuned, aligned BOM with JLCPCB option and position file, regenrated all production files
    [stm32mp1-custom-devboard-B_Cu.gbr, stm32mp1-custom-devboard-B_Mask.gbr, stm32mp1-custom-devboard-B_Paste.gbr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]
2021-01-23 Updated edge cut layer as JLCPCB suggest
    [stm32mp1-custom-devboard-B_Cu.gbr, stm32mp1-custom-devboard-B_Mask.gbr, stm32mp1-custom-devboard-B_Paste.gbr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]
2021-02-09 Updated BOM
    [stm32mp1-custom-devboard_bom_V1.0.xls]
2021-02-13 Started apply issues
    [LCD_Backlight_Driver.kicad_sch, LCD_Touchscreen.kicad_sch, TP_Power_Supply.kicad_sch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]
2021-02-23 Issue 5 applied
    [TP_Power_Supply.kicad_sch, arduino_shield.kicad_sch, minipci_module.kicad_sch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]
2021-02-23 Applied issue 4
    [TP_Power_Supply.kicad_sch, stm32mp1-custom-devboard.kicad_sch, stm32mp1-custom-devboard_bom_V1.0.xls]
2021-02-25 Started issues implementation
    [minipci_module.kicad_sch, mpu_module.kicad_sch, stm32mp1-custom-devboard.kicad_sch]
2021-03-11 Tracking finished
    [LCD_Backlight_Driver.kicad_sch, LCD_Touchscreen.kicad_sch, TP_Power_Supply.kicad_sch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]
2021-03-16 Reworked schematic and applied changes on pcb related with mini pci express
    [LCD_Backlight_Driver.kicad_sch, LCD_Touchscreen.kicad_sch, TP_Power_Supply.kicad_sch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]
2021-03-16 Finalize project
    [mpu_module.kicad_sch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]
2021-04-19 Updated schematic and pdf
    [LCD_Backlight_Driver.kicad_sch, LCD_Touchscreen.kicad_sch, TP_Power_Supply.kicad_sch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]
2021-04-27 Generated schematic in pdf
    [power_supply.kicad_sch]
2021-04-29 Modified ethernet
    [ethernet.kicad_sch, mpu_module.kicad_sch, stm32mp1-custom-devboard.kicad_sch]
2021-04-29 Started etherner reworking
    [ethernet.kicad_sch, stm32mp1-custom-devboard.kicad_sch]
2021-05-11 Changed supply of 3.3V DC-DC converter
    [power_supply.kicad_sch, stm32mp1-custom-devboard.kicad_sch]
2021-05-12 Make all connections, started track tunning
    [stm32mp1-custom-devboard.kicad_sch, usb.kicad_sch]
2021-05-12 Added some rules for ethernet
    [ethernet.kicad_sch]
2021-05-22 Aligned USB C connectors on schematic and on pcb
    [stlink.kicad_sch, stm32mp1-custom-devboard.kicad_sch]
2021-05-22 Ethernet tracking in progress
    [Ethernet_Track_Tunning_Calculations.ods]
2021-05-23 Ethernet TXDx and RXDx tunned
    [Ethernet_Track_Tunning_Calculations.ods]
2021-05-23 Almost all ethernet signals aligned
    [Ethernet_Track_Tunning_Calculations.ods]
2021-05-24 Applied all changes, tunnign started
    [LCD_Touchscreen.kicad_sch, stm32mp1-custom-devboard.kicad_sch]
2021-05-24 Finalized project, regenerated gerbers
    [power_supply.kicad_sch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]
2021-05-25 Finalized project
    [Ethernet_Track_Tunning_Calculations.ods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]
2021-06-20 Updated schematic
    [LCD_Backlight_Driver.kicad_sch, LCD_Touchscreen.kicad_sch, TP_Power_Supply.kicad_sch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]
2021-12-14 GAdded new branch v3.0
    [LCD_Backlight_Driver.kicad_sch, LCD_Touchscreen.kicad_sch, TP_Power_Supply.kicad_sch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]
2021-12-17 Corrected schematic
    [LCD_Touchscreen.kicad_sch, arduino_shield.kicad_sch, ethernet.kicad_sch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]
2022-01-08 Rebuild board
    [mpu_module.kicad_sch, stm32mp1-custom-devboard.kicad_sch]
2022-01-08 Placed all elements on pcb
    [stm32mp1-custom-devboard.kicad_pcb]
2022-01-08 Updated place of capacitor
    [stm32mp1-custom-devboard.kicad_pcb]
2022-01-08 Replaced some elements on pcb
    [stm32mp1-custom-devboard.kicad_pcb]
2022-01-15 Cleared all errors DRC
    [LCD_Backlight_Driver.kicad_sch, LCD_Touchscreen.kicad_sch, TP_Power_Supply.kicad_sch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]
2022-01-15 Eliminated all warnings realted with footprints
    [LCD_Touchscreen.kicad_sch, arduino_shield.kicad_sch, ethernet.kicad_sch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]
2022-01-15 Gerbers created, BOM, CPL
    [Ethernet_Track_Tunning_Calculations.ods, LCD_Backlight_Driver.kicad_sch, TP_Power_Supply.kicad_sch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]
2022-01-15 Aligned BOM with JLCPCB
    [stm32mp1-custom-devboard_bom_V3.0.xls]
2022-01-16 Corrected 3.3V DC power path and regenerated gerbers
    [stm32mp1-custom-devboard-B_Cu.gbr, stm32mp1-custom-devboard-B_Mask.gbr, stm32mp1-custom-devboard-B_Paste.gbr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]
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2022-04-08 Changed ethernet connector to horizontal and changed it position to avoid collision with arduino shield
    [LCD_Backlight_Driver.kicad_sch, LCD_Touchscreen.kicad_sch, TP_Power_Supply.kicad_sch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]
